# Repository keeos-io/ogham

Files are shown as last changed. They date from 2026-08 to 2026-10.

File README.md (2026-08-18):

# Ogham

A dual-voice **bytebeat synthesizer** for Eurorack, built on the Electro-Smith
Daisy Seed. This repository holds everything needed to build one: firmware
source, schematics, PCB, panel, and the fabrication package.

Instead of oscillators and wavetables, Ogham runs *bytebeat* expressions —
single lines of integer arithmetic that, evaluated over time, produce
surprisingly rich rhythmic and melodic patterns. It hosts a bank of them, plays
two at once, and clocks, pitches and modulates them from the rest of your rack.

- **Manual:** <https://keeos.io/docs/ogham-manual/> (or [`docs/ogham-manual.pdf`](docs/ogham-manual.pdf))
- **Firmware downloads and changelog:** <https://keeos.io/firmware/ogham/>
- **Module overview:** <https://keeos.io/modules/ogham/>

> **Status: prototype.** Built and tested on a handful of units, not qualified
> for production. Published so others can learn from it and build on it. Check
> the design yourself before you commit money to a fab run.

## What's here

| Path | Contents |
|---|---|
| [`firmware/`](firmware/) | Firmware source, build and flashing instructions |
| [`hardware/ogham-merged-v1.0/`](hardware/ogham-merged-v1.0/) | KiCad schematics and PCB — the shipping revision |
| [`hardware/panel/`](hardware/panel/) | Front panel: artwork, and the panel PCB project |
| [`hardware/production/`](hardware/production/) | Gerbers, BOM, placement — ready to upload to a fab |
| [`docs/`](docs/) | Build instructions, and the manual as a PDF |
| `lib/` | libDaisy and DaisySP, as pinned submodules |

Only the **current** board revision is published. Earlier prototypes are not
included, so there is nothing here to fabricate by mistake.

## Quick start

**To build the firmware** — [`docs/BUILDING.md`](docs/BUILDING.md) has the full
set-up for Windows, macOS and Linux; [`firmware/README.md`](firmware/README.md)
covers the firmware itself. In short:

```bash
git clone --recurse-submodules https://github.com/keeos-io/ogham.git
cd ogham && make -C lib/libDaisy -j8 && make -C lib/DaisySP -j8
cd firmware && make -j8
```

`--recurse-submodules` is not optional: libDaisy has nested submodules of its
own, and without them the build fails part-way with a missing HAL object.

**To have the boards made** — see [`hardware/README.md`](hardware/README.md).
Upload `hardware/production/ogham-merged-v1.0.zip`, and **read the
hand-populate list first**: several parts are deliberately excluded from
assembly and a board built from the BOM alone will be missing them.

## Licensing

Firmware is **MIT**. Hardware and documentation are **CC BY-SA 4.0**. Build one,
sell one, fork it — but share hardware modifications alike, and give credit. The
*Keeos* name and the panel identity are not covered.

Full terms in [`LICENSE.md`](LICENSE.md); third-party components and the panel
typefaces in [`THIRD-PARTY.md`](THIRD-PARTY.md).

## A note on reproducible builds

The published binaries are byte-for-byte reproducible from this repository.
Building the firmware at a given tag, with the submodules at their pinned
commits and **Arm GNU Toolchain 14.2.Rel1**, reproduces the exact `.bin` shipped
for that release — verified, not assumed.

Two things will break that: building against a *different* libDaisy commit, or a
different compiler version. Both produce working firmware; neither reproduces the
published checksums. If you are verifying a download rather than developing,
compare against the SHA-256 published with each release.

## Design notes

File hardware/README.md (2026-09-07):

# Ogham hardware

KiCad 10 sources and a ready-to-upload fabrication package for the shipping
board revision, **ogham-merged-v1.0**.

| | |
|---|---|
| Main PCB | 50 × 110 mm, 2-layer, double-sided SMT |
| Panel | 10 HP (50.5 × 128.5 mm) |
| Depth behind panel | ~32 mm including power-cable clearance — skiff-friendly |
| Supply | Eurorack ±12 V; the Seed runs from +12 V through a series Schottky, and an on-board +5 V regulator feeds the display and logic |
| MCU | Electro-Smith Daisy Seed (STM32H750), on pin-header standoffs |

Only this revision is published. Earlier prototypes (`ogham-logic`, `ogham-ui`
and their v0.2 iterations) are not included, so there is nothing here to
fabricate by mistake.

## Layout

| Path | Contents |
|---|---|
| `ogham-merged-v1.0/` | Schematics (hierarchical: power, MCU, CV I/O, audio, UI), PCB, netlist |
| `panel/` | Panel artwork as SVG, and the panel as a fabricable PCB (`PanelPCB-v2/`) |
| `production/` | Gerbers, BOM, placement, IPC netlist, and the interactive BOM |

The schematic is a two-level hierarchy: `ogham-merged-v1.0` is the root, and it
pulls in `ogham-logic-v2.0` (→ power, MCU, CV I/O) and `ogham-ui-v0.2` (→ audio,
UI). Those two keep the sheet names they had when the design was two separate
boards — they are **not** old revisions, they are live sub-sheets of this one.

## 3D models are not included

The PCB references five third-party 3D models. They are other people's files, in
one case 34 MB of one, and several arrived without a licence attached, so they
are not redistributed here. Everything else the board needs is in this
repository; only the 3D viewer is affected, and the board fabricates,
assembles and works without them.

The references are `${KIPRJMOD}`-relative, which means KiCad resolves them
against the project directory. Create `hardware/_libs/` and drop the files in
at these paths and the 3D view fills in with no edit to the PCB:

| Path under `hardware/_libs/` | Part | Source | Licence |
|---|---|---|---|
| `AudioJacks/AudioJacks.3dshapes/PJ398SM_Hex_nut.step` | Thonkiconn PJ398SM jacks | [clacktronics/AudioJacks](https://github.com/clacktronics/AudioJacks) | MIT |
| `kicad-3dmodels/potentiometers/ALPHA-RD901F-40.step` | Alpha 9mm pots | [dhaillant/kicad-3dmodels](https://github.com/dhaillant/kicad-3dmodels) | GPL-3.0 |
| `TM1637/YAAJ_4_Digit_LED_Display_0_36_Dots_TM1637_PinHeader_Left_cp.step` | TM1637 display | [yet-another-average-joe/KiCad-Chinese_Modules](https://github.com/yet-another-average-joe/KiCad-Chinese_Modules) | not stated upstream |
| `DaisySeed/ES_Daisy_Seed_Rev7-1.step` | Daisy Seed | Electro-Smith | not stated on the copy used here |
| `Encoder/EC11E1834403/3D/EC11E1834403.stp` | EC11 encoder | manufacturer model; provenance not recorded | unknown |
| `vendor/2MS1T1B1M2QES--3DModel-STEP-56544.STEP` | Mode toggle switch | manufacturer model | unknown |
| `vendor/TAP106J016SCS.STEP` | Tantalum capacitor | manufacturer model | unknown |

A missing model is a warning, not an error: KiCad opens the board and reports
which ones it could not find. Note also that each jack footprint carries a
second, dead model entry naming `${KICAD9_3DMODEL_DIR}`, a KiCad 9 path
variable that KiCad 10 does not define. The jacks render from the AudioJacks
model above, so that entry can be ignored.

## Browse the design without installing anything

[KiCanvas](https://kicanvas.org) renders KiCad files in the browser, straight
from this repository — pan, zoom, click a symbol, follow a net. Nothing to
install, nothing to download.

| | |
|---|---|
| Schematic and PCB | [Open in KiCanvas](https://kicanvas.org/?github=https://github.com/keeos-io/ogham/tree/main/hardware/ogham-merged-v1.0) |
| Panel PCB | [Open in KiCanvas](https://kicanvas.org/?github=https://github.com/keeos-io/ogham/tree/main/hardware/panel/PanelPCB-v2) |

Both links point at a **directory**, not at a file, and that is deliberate. Given
a single `.kicad_sch` KiCanvas loads it alone, which for a hierarchical design
means the root sheet and nothing below it — you would get a page of sheet symbols
with no way into them. Pointed at the directory it enumerates every file, so all
nine sheets resolve and the board is in the same viewer, behind the file picker
at the top left.

This matters more than convenience: these are **KiCad 10** sources, and KiCad 9
cannot open them at all. Until you have KiCad 10 in front of you, the links above
are the only way to read the circuit.

KiCanvas is a third-party viewer and fetches from GitHub anonymously, so it is
subject to GitHub's rate limits and is nobody's idea of a permanent archive. The
files in this repository are the source of truth; the links are a convenience.

## Having the boards made

The package in `production/` is formatted for JLCPCB assembly, but the gerbers
are standard and will work anywhere. **Read
[`production/JLC-upload-checklist.md`](production/JLC-upload-checklist.md)
before ordering** — it covers the whole flow, including the two things most
likely to cost you a board run.

### ⚠ 1. Nineteen parts must be marked "Do Not Place"

90 SMD parts are machine-assembled. **19 designators across 13 BOM rows are
hand-soldered** and will be flagged by the fab as unresolvable, because they
carry no LCSC number. Mark every one of them DNP:

- **C5** — 10 µF tantalum (`TAP106J016SCS`). This one is easy to miss: it looks
  like an ordinary SMD part in the BOM and it is the **+5 V bulk capacitor**, so
  a board that quietly ships without it is not a board you want.
- **A1** — the Daisy Seed
- **J1** — Eurorack power header
- **8 × jacks** — `J_CLK1`, `J_CVA1`, `J_CVB1`, `J_GATE_IN1`, `J_CV_OUT1`,
  `J_GATE_OUT1`, `J_OUT1`, `J_OUT2`
- **J_DISP1**, **J_DISP_SUPP** — display headers
- **4 × pots** — `RVA1`, `RVB1`, `RVLEVEL1`, `RVRATE1`
- **SW_ENC1** — encoder · **SW_MODE1** — mode toggle

### ⚠ 2. Check rotations before you confirm

Rotation is the classic assembly error — KiCad and the fab disagree about
reference orientation. Step through the placement preview and check the
polarised parts: diode cathodes (D1, D2, D8, D3, D4, D5, D_OCT1, D_OCT2, D6,
D7), IC pin-1 (U1–U7), and Q1's collector/emitter. Assembly is **double-sided**,
so also confirm the top-layer parts really are on top.

## Interactive BOM — use this while assembling

[`production/ogham-merged-v1.0-ibom.html`](production/ogham-merged-v1.0-ibom.html)
is a single self-contained file: click a line in the BOM and those parts light up
on the board, front and back, with checkboxes for tracking what you have sourced
and placed. No install, no network — **download it and open it in a browser**.

> GitHub displays committed HTML as source rather than rendering it, so use the
> download button rather than clicking through — the file is useless as text and
> perfectly good once saved.

It carries an **LCSC** column, which doubles as the hand-populate list: a part
with an LCSC number is machine-assembled, and a part **without** one is yours to
solder. `C5` shows its bare MPN `TAP106J016SCS`, and the jacks, pots, encoder and
headers show nothing at all — those are exactly the 19 designators to mark Do Not
Place.

Regenerate it with [`gen-ibom.sh`](gen-ibom.sh) whenever the board changes; the
output is committed, so it can otherwise drift from the design. It needs KiCad's
own Python and [InteractiveHtmlBom](https://github.com/openscopeproject/InteractiveHtmlBom)
**v2.11.2 or newer** — earlier versions cannot read KiCad 10 files.

## Hand-populated parts

Sources that have worked (UK):

| Part | Qty | Where |
|---|---|---|
| Thonkiconn PJ398SM jacks | 8 | [thonk.co.uk](https://www.thonk.co.uk/shop/thonkiconn/) |
| Alpha 9 mm B10K D-shaft pots | 4 | [thonk.co.uk](https://www.thonk.co.uk/shop/alpha-9mm-pots-dshaft/) |
| Rotary encoder, Bourns `PEC11R-4115K-S0018` | 1 | Any distributor — Mouser, Farnell, Digi-Key |
| Breakaway pin header | 1 bag | [thonk.co.uk](https://www.thonk.co.uk/shop/60-pin-header/) |
| 2×5 IDC power header | 1 | Mouser / Soundtronics / York Modular |
| Daisy Seed (Rev 4) | 1 | Electro-Smith |
| C5, 10 µF tantalum | 1 | Any distributor — `TAP106J016SCS` or equivalent |

> **Encoder note.** `PEC11R-4115K-S0018` is a 15 mm knurled (T18) shaft with a
> push switch, 18 detents and 18 pulses per revolution — one pulse per detent.
> It is the swapped-A/B part, which the **default** firmware build targets. Two
> batches exist with opposite A/B phase and the firmware cannot tell them apart,
> so if the Func encoder counts down when turned clockwise, flash the other
> build — see [`../firmware/README.md`](../firmware/README.md).
>
> **Why the 15 mm shaft.** It matches the Alpha pots dimensionally: the same
> 5 mm M7 × 0.75 bushing and the same 15 mm from mounting shoulder to shaft tip,
> so the encoder knob sits level with the four pot knobs rather than standing
> proud of them. The 20 mm variant of the same encoder carries a 7 mm bushing
> and would not. The cost of that choice is a short thread — 5 mm of bushing
> against a 1.6 mm panel — so expect to pack a washer under the nut to pull the
> encoder flush.

## Panel

`panel/` holds the artwork as SVG and as a fabricable PCB, which is how the
panels were actually made — a PCB panel is cheap, flat, and takes the graphics as
silkscreen.

`Ogham Panel Graphics (JLCPCB) v2.svg` is the editable artwork, and
`PanelPCB-v2/` is the KiCad project converted from it — that project, and the
gerbers in its `production/`, are what the built modules use. The first
revision has been removed to leave only one panel to order from; it is still in
the git history if you want it.

**The fabrication files do not depend on any fonts.** The artwork is stored as
polygons, converted from the SVG, so a panel ordered from
`PanelPCB-v2/production/` comes out right regardless of what is installed on your
machine.

**Editing the SVG does need fonts**, though all three are now free and
redistributable — the v2 artwork replaced Bahnschrift, a Windows system font,
with DINish. See
[`../THIRD-PARTY.md`](../THIRD-PARTY.md) for the full list and what to do on
macOS or Linux.

## Design notes

`ogham_pins.h` in the firmware is the pin-assignment source of truth and matches
this schematic. If you rework the board, keep them in step.

Two constraints worth knowing before you move things: the TM1637 display sits on
**D9/D10 (PB4/PB5)**, which are SPI pins with **no I²C alternate function** — an
I²C peripheral needs different pins. Seed pins 12/13 (PB8/PB9, I²C1) are
unconnected and are the obvious place to go.

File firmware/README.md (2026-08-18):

# Ogham firmware

C++ for the STM32H750 on an Electro-Smith Daisy Seed, built against libDaisy and
DaisySP. Runs from **internal flash at `0x08000000`** — there is no bootloader
involved, so the whole 128 KB region is the application.

## Building

Full per-platform setup for **Windows, macOS and Linux** — toolchain, Make, USB
drivers, udev rules — is in [`../docs/BUILDING.md`](../docs/BUILDING.md). That is
the authority; this file covers only what is specific to the firmware itself.

The short version, once the tools are installed:

```bash
git clone --recurse-submodules https://github.com/keeos-io/ogham.git
cd ogham
make -C lib/libDaisy -j8 && make -C lib/DaisySP -j8
cd firmware && make -j8            # -> build/ogham_bytebeat.{elf,bin,hex}
```

`--recurse-submodules` is not optional — libDaisy has nested submodules, and
without them the build fails part-way with a missing HAL object. Fix an existing
clone with `git submodule update --init --recursive`.

Libraries elsewhere? `make LIB_DIR=/path/to/libs -j8`.

Reproducing a published binary exactly needs **Arm GNU Toolchain 14.2.Rel1** and
the submodules at their pinned commits; any other compiler builds working
firmware that simply will not match the release checksum.

## ⚠ Two encoder builds — pick the right one

Two batches of rotary encoder exist with **opposite A/B phase**. The firmware
cannot detect which is fitted, so there are two builds:

| Build | Command | Output | For |
|---|---|---|---|
| **Default** | `make -j8` | `build/ogham_bytebeat.bin` | The current encoder — **almost certainly what you want** |
| Original | `make -f Makefile.encorig BUILD_DIR=build_encorig -j8` | `build_encorig/ogham_bytebeat_encorig.bin` | Early units with the original part |

**If after flashing the Func encoder counts *down* when you turn it clockwise,
you flashed the wrong one.** Flash the other and it is fixed. Nothing else
differs between them — same version, same behaviour, same display.

> Note for anyone reading older release notes: this naming **flipped in v1.05**.
> The default build used to be the original encoder, with the reversed one as
> the variant. It is now the other way round, because the reversed part is what
> current modules use.

## Flashing

Commands and platform notes are in [`../docs/BUILDING.md`](../docs/BUILDING.md#flashing).
In brief: `make program` with an ST-Link, or hold **BOOT**, tap **RESET**, and

```bash
dfu-util -a 0 -s 0x08000000:leave -D build/ogham_bytebeat.bin
```

The `:leave` matters, and **unplug USB before power-cycling** — the Seed is
powered by USB as well as the rack, so the case switch alone does not reset it.

## Layout

| File | Role |
|---|---|
| `ogham_main.cpp` | Init, main loop, encoder/menu state machine, persistence, telemetry |
| `bytebeat_engine.*` | 32.32 fixed-point phase accumulator; dual voice; hard sync; drone |
| `formulas.*` | The formula bank as inline functions, plus metadata |
| `ogham_audio_pipeline.*` | Tone macro, FX chain, low-pass gate |
| `ogham_controls.*` | ADC smoothing, quadrature decode, mode switch |
| `ogham_display.*`, `tm1637.*` | 4-digit 7-segment display |
| `ogham_cv_output.*` | Envelope follower / DC out on the DAC |
| `bpm_clock.*` | Tempo estimation for the EOC output |
| `ogham_pins.h` | Pin assignments — the source of truth, matching the schematic |

Formulas are compiled in. All bitwise operations follow JavaScript `ToInt32`
semantics (shift counts masked to `& 31`, output masked to `& 0xFF`) so formulas
behave as they do in browser bytebeat tools.

`formulas.h` and `formulas.cpp` are **generated**, not hand-written — the bank is
translated out of the curated library by `tools/gen_ogham_bank.cpp` in the
bytebeat repository (the search and curation tooling, which is not published).
The generator emits the manual's Appendix A from the same manifest, and compares
every generated function against the evaluator the formulas were auditioned on.
Change the library and regenerate rather than editing these two files, or the
module and the manual drift apart.

Which formula lands in which slot is stored on the curated formula itself rather
than derived from its position in the library: the generator reads those numbers
and does not sort, group or renumber. Slots are assigned in the bytebeat app's
CURATE view, which can also preview the whole bank against the firmware's
current `formulas.h` before anything is generated. The end-to-end process —
including the flash-size check, which is the binding constraint on this 128 KB
region — is `docs/PUBLISHING-THE-BANK.md` in that repository.

Appendix A of the manual lists every formula's expression and what A and B change.

## Calibration

Pots are non-linear because of the 10 kΩ pull-down, so the firmware holds
measured 12-o'clock ADC values for the Rate and Tone knobs. Those constants are a
fleet mean; if your build's centre detent feels off, measure yours:

```bash
make -f Makefile.diag -j8       # -> build_diag/ogham_pot_diag.{elf,bin}
```

Flash it, read the values off the display, and update `RATE_POT_CENTER` in
`ogham_main.cpp` and `LOFI_CENTER` in `ogham_audio_pipeline.cpp`.

`tools/` holds Python scripts that read live telemetry over SWD while the module
runs — useful for calibration and for watching CPU load.

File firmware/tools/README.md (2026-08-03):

# Ogham Monitor

A PC app that visualizes the running module live over the debugger (ST-Link/SWD):
the 7-segment display (exact segments, even with no TM1637 wired), module state,
pot positions, and CV inputs. For debugging and calibration.

It reads the firmware's `g_telemetry` struct via OpenOCD — **no USB to the
Daisy**, so the module runs on **Eurorack power** with the CV inputs live, and
there's no dual-supply contention.

## Run

1. Power the module from **Eurorack** and connect the **ST-Link** (the same SWD
   setup used for flashing). The board must be powered, or OpenOCD can't connect.
2. Close anything else using the ST-Link (you can't flash while the monitor runs).
3. `python ogham_monitor.py`

The app launches its own OpenOCD instance, finds `g_telemetry` via `nm` on
`build/ogham_bytebeat.elf`, and polls at ~12 Hz.

## Shows
- **7-segment display** — the exact bytes the firmware sends to the TM1637.
- **State** — mode (SELECT/DELAY), edited voice, Out1/Out2 formulas, delay,
  params A/B, rate, ext-clock, lo-fi clean, gate/clock inputs, CPU load.
- **Bars** — raw pot ADCs (A/B/Rate/Level), combined pot+CV (A/B), CV ADC pins
  (shown as volts).

## Notes
- Paths to OpenOCD and `arm-none-eabi-nm` are set at the top of the script.
- The telemetry struct layout is `STRUCT_FMT` in the script; it must match
  `struct Telemetry` in `ogham_main.cpp`. If you change the struct, update both.
- The struct address is found automatically (via `nm`); it moves on rebuilds.

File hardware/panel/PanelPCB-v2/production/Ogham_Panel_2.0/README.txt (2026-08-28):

 FRONT PANEL - NO ELECTRICAL FUNCTION

  1. ALL holes, slots and internal cutouts are NON-PLATED (NPTH).
     Do not plate any hole, slot or cutout.
  2. There are no nets and no plated holes on this board.
     The PTH drill file is intentionally empty.
  3. Internal openings are defined by the Edge_Cuts layer (15 openings)
     and by the NPTH drill file (4 mounting slots, 4.5 x 3.5 mm routed).
     Route all of them; none are plated.
  4. Front copper is decorative artwork only. Where copper meets a routed
     edge, cut through it. Do not add plating, do not add copper thieving,
     and do not modify the copper or silkscreen artwork.

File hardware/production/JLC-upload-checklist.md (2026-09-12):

# JLCPCB Upload Checklist — Ogham v1.0 (ogham-merged-v1.0)

Files: `ogham-merged-v1.0.zip` (gerbers) · `bom.csv` · `positions.csv`
Board: 50 × 110 mm, 2-layer. Assembly: **double-sided SMT** (55 parts bottom / 35 top) + hand-soldered THT.

---

## 1. Upload files
- [ ] Upload gerber zip → confirm JLC preview shows both copper layers, silk, and the board outline (50 × 110 mm)
- [ ] Turn ON "PCB Assembly" → upload `bom.csv` and `positions.csv`
- [ ] Assembly side = **both / top+bottom** (SMD is on both layers)

## 2. Mark "Do Not Place" (DNP) — 14 BOM rows / 19 designators
These are hand-soldered; they have no LCSC (or a non-LCSC MPN) and JLC will ask you to resolve them. Mark each **Do Not Place**:

- [ ] **C5** — 10µF tantalum (MPN `TAP106J016SCS`, not an LCSC number)
- [ ] **A1** — Daisy Seed module
- [ ] **J1** — Eurorack power header
- [ ] **J_CLK1, J_CVA1, J_CVB1, J_GATE_IN1** — 4× audio jacks
- [ ] **J_CV_OUT1** — jack
- [ ] **J_GATE_OUT1** — jack
- [ ] **J_OUT1, J_OUT2** — 2× jacks
- [ ] **J_DISP1** — TM1637 display header
- [ ] **J_DISP_SUPP** — display support header
- [ ] **RVA1, RVB1, RVLEVEL1, RVRATE1** — 4× pots
- [ ] **SW_ENC1** — encoder
- [ ] **SW_MODE1** — mode toggle

_(Everything else — the 90 SMD parts — has a valid LCSC and should stay "Place".)_

## 3. Verify part rotations/polarity in JLC's placement preview
Rotation is the classic assembly error (KiCad vs JLC reference orientation). Eyeball the polarized parts in the online preview; fix any that look flipped 90°/180° before confirming:

- [ ] **Diode cathodes** — D1, D2, **D8** (SS14); D3 (1N4148); D4, D5, D_OCT1, D_OCT2 (BAT54WS); D6, D7 (1N5819WS)
- [ ] **IC pin-1** — U1 (LM4040), U2 (L7805), U3 (MCP6004), U4, U7 (TL072), U5 (74AHCT1G125), U6 (LM393)
- [ ] **Q1** (MMBT3904) collector/emitter orientation
- [ ] Spot-check a couple of the SMD parts on the **top** layer render (double-sided — confirm they're on the correct side)

## 4. Parts / stock confirmation
- [ ] **U1 LM4040 (C156291, LM4040C50FTA)** — confirm in stock at order time (1 per board). Substituted for C156302 on 2026-09-12; JLCPCB places this part, so kits, build guide and manuals are unaffected
- [ ] Note any **Extended parts** loading fee (TL072, MCP6004, LM4040, LM393, 74AHCT1G125 are likely Extended, ~$3 one-time each)

## 5. Place order
- [ ] Review price (double-sided SMT costs more than single-sided)
- [ ] Confirm and order

---

### Hand-solder yourself after boards arrive (the DNP parts above)
8× Thonkiconn jacks · 4× Alpha pots · encoder · mode toggle · Eurorack power header · 2× display headers · C5 tantalum · Daisy Seed (on its pin-header standoffs).

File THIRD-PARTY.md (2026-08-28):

# Third-party components

Everything Ogham depends on that was not written for it, and the licence each
arrives under.

## Firmware

| Component | Licence | Source |
|---|---|---|
| **libDaisy** | MIT © Electrosmith, Corp. | <https://github.com/electro-smith/libDaisy> |
| **DaisySP** | MIT © Electrosmith, Corp. | <https://github.com/electro-smith/DaisySP> |

Both are **git submodules pinned to exact commits**, not copies:

| Submodule | Pinned commit |
|---|---|
| `lib/libDaisy` | `f044cdc312455f174b01bef98d9e97598d94d3bc` |
| `lib/DaisySP`  | `599511b740f8f3a9b8db72a0642aa45b8a23c3a3` |

Pinning is deliberate. A firmware binary is only reproducible if the libraries
are, and libDaisy in particular changes underneath you. Building at these commits
reproduces the published binaries byte for byte; building at `main` may not.

Neither library is modified. If you need a newer one, update the submodule and
rebuild — but expect to re-verify, not to match the published checksums.

The hardware itself is built around the **Electro-Smith Daisy Seed**, which is
itself open hardware. Its schematics and design files are Electrosmith's, are not
reproduced here, and are published at <https://github.com/electro-smith/Hardware>.

## Panel typefaces

The panel artwork uses three typefaces. **No font files are redistributed here** —
the SVG sources reference them by name.

| Typeface | Used for | Licence |
|---|---|---|
| **Uncial Antiqua** | the "ogham" wordmark | SIL Open Font License 1.1 — <https://fonts.google.com/specimen/Uncial+Antiqua> |
| **Noto Sans Ogham** | the ogham script characters | SIL Open Font License 1.1 — <https://fonts.google.com/noto/specimen/Noto+Sans+Ogham> |
| **DINish** | control labels | SIL Open Font License 1.1 — <https://fonts.playbeing.com/dinish/> |

### What this means in practice

**The fabrication files do not depend on any of them.** `hardware/panel/PanelPCB-v2`
and the gerbers in its `production/` directory carry the artwork as **polygons**,
converted from the SVG by svg2shenzhen. The only text left in the footprint is
KiCad's own `Ref**`/`Val**` placeholders, which do not print. You can order a
panel with no fonts installed at all, on any operating system, and get exactly
the intended result.

**The editable SVG sources do depend on them.** Open
`hardware/panel/*.svg` without these fonts installed and the renderer will
substitute — the lettering will still appear, but with different metrics, so it
will not match the fabricated panel and may overlap its own layout. If you intend
to *edit* the panel rather than just fabricate it, install all three: Uncial
Antiqua and Noto Sans Ogham are on Google Fonts, and DINish is at
<https://fonts.playbeing.com/dinish/>. All three are OFL, free, and available on
every platform.

The control labels were set in Bahnschrift until the v2 panel artwork. That is a
Windows system font, proprietary to Microsoft and not redistributable, so editing
the panel on macOS or Linux meant substituting it and re-laying out the labels.
DINish is a DIN 1451 descendant and takes its place with no such condition
attached.

## Fabrication

The `hardware/production/` package is formatted for JLCPCB's assembly service.
Nothing in it is licensed by JLCPCB; the file formats (Gerber, IPC-D-356,
positions CSV) are open. It will work at other fabs, though the BOM's LCSC part
numbers are specific to JLCPCB's supplier and would need mapping.

## Bytebeat formulas

The formulas in `firmware/src/formulas.h` were discovered by machine search
(a purpose-built GPU search with a neural fitness model) and are original to this
project, not taken from published bytebeat collections.

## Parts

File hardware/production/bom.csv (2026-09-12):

Designator | Footprint | Quantity | Value | LCSC Part #
A1 | Electrosmith_Daisy_Seed | 1 | Electrosmith_Daisy_Seed_Rev4
C1, C10, C2 | 1210 | 3 | 10uF | C138687
C3, C4, C6, C7, C8, C9, C_BYP_U3, C_BYP_U4N1, C_BYP_U4P1, C_BYP_U5, C_BYP_U6, C_ENC_A1, C_ENC_B1, C_ENC_SW1, C_FLT1, C_FLT2, C_FLT3, C_FLT4, C_TL1, C_TL2 | 0603 | 20 | 100nF | C14663
C5 | CP_Radial_D5.0mm_P2.50mm | 1 | 10uF | TAP106J016SCS
C_FB_A1, C_FB_B1, C_VOCT_ADC1 | 0603 | 3 | 1nF | C1588
C_FILT1, C_FILT2 | 0603 | 2 | 2.2nF | C1604
D1, D2, D8 | D_SMA | 3 | SS14 | C2480
D3 | D_SOD-323 | 1 | 1N4148 | C2128
D4, D5, D_OCT1, D_OCT2 | D_SOD-323 | 4 | BAT54WS | C22629
D6, D7 | D_SOD-323 | 2 | 1N5819WS | C191023
FB1, FB2 | 0603 | 2 | BLM18PG121 | C14709
J1 | PinHeader_2x05_P2.54mm_Vertical | 1 | Eurorack_Power
J_CLK1, J_CVA1, J_CVB1, J_GATE_IN1 | Jack_3.5mm_QingPu_WQP-PJ398SM_Vertical_CircularHoles | 4 | AudioJack2_SwitchT
J_CV_OUT1 | Jack_3.5mm_QingPu_WQP-PJ398SM_Vertical_CircularHoles | 1 | CV_OUT
J_DISP1 | PinHeader_1x04_P2.54mm_Vertical | 1 | TM1637
J_DISP_SUPP | PinHeader_1x04_P2.54mm_Vertical | 1 | PinHeader_1x04_P2.54mm_Vertical
J_GATE_OUT1 | Jack_3.5mm_QingPu_WQP-PJ398SM_Vertical_CircularHoles | 1 | GATE_OUT
J_OUT1 | Jack_3.5mm_QingPu_WQP-PJ398SM_Vertical_CircularHoles | 1 | OUT1
J_OUT2 | Jack_3.5mm_QingPu_WQP-PJ398SM_Vertical_CircularHoles | 1 | OUT2
Q1 | SOT-23 | 1 | MMBT3904 | C20526
R1, R_CLK_IN1, R_CLK_PU1, R_CV_GND1, R_DIO1, R_DIV1, R_DIV2, R_F1, R_F2, R_VOCT1 | 0603 | 10 | 10k | C25804
R2, R5, R8, R9, R_FB_A1, R_FB_B1, R_GATE_IN1, R_HYS1, R_PD1, R_PD2, R_PD3, R_PD4 | 0603 | 12 | 100k | C25803
R3, R6 | 0603 | 2 | 470k | C23178
R4, R7 | 0603 | 2 | 200k | C25811
RVA1, RVB1, RVLEVEL1, RVRATE1 | Potentiometer_Alpha_RD901F-40-00D_Single_Vertical | 4 | 10k
R_CV_FB1 | 0603 | 1 | 20k | C4184
R_CV_OUT1, R_FLT1, R_FLT2, R_FLT3, R_FLT4, R_GOUT1, R_OUT1, R_OUT2, R_VOCT_ADC1 | 0603 | 9 | 1k | C21190
R_FILT1, R_FILT2 | 0603 | 2 | 470 | C23179
R_G1, R_G2 | 0603 | 2 | 2.7k | C13167
R_GATE_DIV1 | 0603 | 1 | 33k | C4216
R_VOCT2 | 0603 | 1 | 18k | C25810
SW_ENC1 | RotaryEncoder_Alps_EC11E-Switch_Vertical_H20mm | 1 | Encoder
SW_MODE1 | SW_2MS1T1B1M2QES | 1 | SW_SPDT
U1 | SOT-23 | 1 | LM4040-5.0 | C156291
U2 | TO-263-2 | 1 | L7805 | C15077
U3 | TSSOP-14_4.4x5mm_P0.65mm | 1 | MCP6004 | C50282
U4, U7 | SOIC-8_3.9x4.9mm_P1.27mm | 2 | TL072 | C67473
U5 | SOT-23-5 | 1 | 74AHCT1G125 | C7484
U6 | SOIC-8_3.9x4.9mm_P1.27mm | 1 | LM393 | C136033

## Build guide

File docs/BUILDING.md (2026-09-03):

# Building and flashing Ogham firmware

Step-by-step for **Windows**, **macOS** and **Linux**. If you only want to *run*
the firmware, you do not need any of this — download a `.bin` from the
[releases page](https://github.com/keeos-io/ogham/releases) or use the
in-browser flasher at <https://keeos.io/firmware/ogham/>, and skip to
[Flashing](#flashing).

> **Verification note.** The Windows instructions are the ones used day to day
> and are known good. The macOS and Linux instructions follow the standard route
> for each platform and use the same official Arm toolchain, but have not been
> exercised on those machines. If something is off, please open an issue — it
> will be a documentation bug, not a firmware one.

## What you need

| | Why | Version |
|---|---|---|
| **Arm GNU Toolchain, `arm-none-eabi`** | Cross-compiler | **14.2.Rel1** — see below |
| **GNU Make** | Build driver | Any recent |
| **Git** | With submodule support | Any recent |
| *Optional:* **OpenOCD** | Flashing over SWD with an ST-Link | 0.12.x |
| *Optional:* **dfu-util** | Flashing over USB, no probe needed | 0.11+ |
| *Optional:* **Python 3** | Live telemetry tools in `firmware/tools/` | 3.9+ |

### Why the toolchain version is called out

The published binaries are byte-for-byte reproducible with **Arm GNU Toolchain
14.2.Rel1** and the submodules at their pinned commits. A different compiler
version builds perfectly good firmware — it just will not match the SHA-256
published with the release. If you are verifying a download rather than
developing, use 14.2.Rel1; otherwise use whatever you have.

Direct downloads for 14.2.Rel1 (all verified live):

| Platform | File |
|---|---|
| Windows | [`…-mingw-w64-i686-arm-none-eabi.exe`](https://developer.arm.com/-/media/Files/downloads/gnu/14.2.rel1/binrel/arm-gnu-toolchain-14.2.rel1-mingw-w64-i686-arm-none-eabi.exe) |
| macOS (Apple Silicon) | [`…-darwin-arm64-arm-none-eabi.tar.xz`](https://developer.arm.com/-/media/Files/downloads/gnu/14.2.rel1/binrel/arm-gnu-toolchain-14.2.rel1-darwin-arm64-arm-none-eabi.tar.xz) |
| macOS (Intel) | [`…-darwin-x86_64-arm-none-eabi.tar.xz`](https://developer.arm.com/-/media/Files/downloads/gnu/14.2.rel1/binrel/arm-gnu-toolchain-14.2.rel1-darwin-x86_64-arm-none-eabi.tar.xz) |
| Linux (x86-64) | [`…-x86_64-arm-none-eabi.tar.xz`](https://developer.arm.com/-/media/Files/downloads/gnu/14.2.rel1/binrel/arm-gnu-toolchain-14.2.rel1-x86_64-arm-none-eabi.tar.xz) |
| Linux (ARM64) | [`…-aarch64-arm-none-eabi.tar.xz`](https://developer.arm.com/-/media/Files/downloads/gnu/14.2.rel1/binrel/arm-gnu-toolchain-14.2.rel1-aarch64-arm-none-eabi.tar.xz) |

---

## Windows

Use **Git Bash** (installed with Git for Windows) for the commands below. The
Makefiles are POSIX shell; they will not run in `cmd.exe` or PowerShell.

The exact set-up in use, via `winget`:

```powershell
winget install Arm.GnuArmEmbeddedToolchain    # 14.2.Rel1
winget install ezwinports.make                # GNU Make 4.4.1
winget install xpack-dev-tools.openocd-xpack  # optional, for ST-Link flashing
```

**Windows does not ship `make`, and the Arm toolchain does not include it** —
that is the step people miss. `ezwinports.make` is a plain native build with no
MSYS baggage. MSYS2's `make`, or Chocolatey's, work equally well.

`dfu-util` has no reliable winget package; take the Windows binary from
<https://dfu-util.sourceforge.net/> and put it on your `PATH`.

The Arm installer offers to add itself to `PATH` — say yes, or add it per shell:

```bash
export PATH="/c/Program Files (x86)/Arm GNU Toolchain arm-none-eabi/14.2 rel1/bin:$PATH"
```

### USB drivers

Windows needs a driver bound to the device before flashing tools can see it:

- **ST-Link** — install ST's ST-LINK USB driver, or use the one bundled with
  STM32CubeProgrammer.
- **DFU (bootloader mode)** — the Seed enumerates as *STM32 BOOTLOADER* and
  needs the **WinUSB** driver. Use [Zadig](https://zadig.akeo.ie/): put the Seed
  in DFU mode, pick that device, select **WinUSB**, and hit Replace Driver.
  Without this, `dfu-util` reports no DFU capable devices found.

---

## macOS

With [Homebrew](https://brew.sh):

```bash
brew install --cask gcc-arm-embedded    # Arm toolchain (check the version it gives you)
brew install make git open-ocd dfu-util
```

macOS ships GNU Make 3.81, which is old but sufficient here. Homebrew's `make`
installs as `gmake` unless you adjust `PATH`; either works.

**If you need exactly 14.2.Rel1** — because you want to reproduce a published
checksum — install Arm's tarball rather than the cask, since the cask tracks
whatever is current:

```bash
curl -LO https://developer.arm.com/-/media/Files/downloads/gnu/14.2.rel1/binrel/arm-gnu-toolchain-14.2.rel1-darwin-arm64-arm-none-eabi.tar.xz
sudo mkdir -p /opt/arm && sudo tar -xf arm-gnu-toolchain-14.2.rel1-darwin-arm64-arm-none-eabi.tar.xz -C /opt/arm
export PATH="/opt/arm/arm-gnu-toolchain-14.2.rel1-darwin-arm64-arm-none-eabi/bin:$PATH"
```

Substitute `darwin-x86_64` on an Intel Mac.

**Gatekeeper.** Binaries downloaded outside the App Store are quarantined, and
the first `arm-none-eabi-gcc` run may be blocked. Clear it once:

```bash
sudo xattr -dr com.apple.quarantine /opt/arm
```

No driver work is needed — ST-Link and DFU both work through the system USB
stack.

---

## Linux

Install Make, Git and the flashing tools from your distribution:

```bash
# Debian / Ubuntu
sudo apt install build-essential git openocd dfu-util

# Fedora
sudo dnf install make git openocd dfu-util

# Arch
sudo pacman -S make git openocd dfu-util
```

For the compiler, **prefer Arm's tarball over the distro package**. Distro
`gcc-arm-none-eabi` versions vary widely, and some have historically shipped
without the newlib the build expects:

```bash
curl -LO https://developer.arm.com/-/media/Files/downloads/gnu/14.2.rel1/binrel/arm-gnu-toolchain-14.2.rel1-x86_64-arm-none-eabi.tar.xz
sudo mkdir -p /opt/arm && sudo tar -xf arm-gnu-toolchain-14.2.rel1-x86_64-arm-none-eabi.tar.xz -C /opt/arm
export PATH="/opt/arm/arm-gnu-toolchain-14.2.rel1-x86_64-arm-none-eabi/bin:$PATH"
```

Add that `export` to your `~/.bashrc` to make it stick.

> On 64-bit-only distributions the toolchain may need 32-bit support libraries.
> If `arm-none-eabi-gcc` reports "No such file or directory" despite clearly
> existing, that is the cause — install your distro's 32-bit compatibility
> packages.

### udev rules — the step that catches everyone

Without these, flashing fails with a permissions error unless you run as root.
Create `/etc/udev/rules.d/49-ogham.rules`:

```
# ST-Link V2 / V2.1 / V3
SUBSYSTEM=="usb", ATTR{idVendor}=="0483", ATTR{idProduct}=="3748", MODE="0666", TAG+="uaccess"
SUBSYSTEM=="usb", ATTR{idVendor}=="0483", ATTR{idProduct}=="374b", MODE="0666", TAG+="uaccess"
SUBSYSTEM=="usb", ATTR{idVendor}=="0483", ATTR{idProduct}=="374f", MODE="0666", TAG+="uaccess"
# STM32 DFU bootloader (the Daisy Seed in bootloader mode)
SUBSYSTEM=="usb", ATTR{idVendor}=="0483", ATTR{idProduct}=="df11", MODE="0666", TAG+="uaccess"
```

Then reload and re-plug the device:

```bash
sudo udevadm control --reload-rules && sudo udevadm trigger
```

---

## Building

Identical on all three platforms once the tools are in place.

```bash
git clone --recurse-submodules https://github.com/keeos-io/ogham.git
cd ogham
make -C lib/libDaisy -j8      # a few minutes the first time
make -C lib/DaisySP  -j8
cd firmware && make -j8
```

Output lands in `firmware/build/`: `ogham_bytebeat.elf`, `.bin` and `.hex`.

**`--recurse-submodules` is not optional.** libDaisy has nested submodules of its
own (CMSIS, the STM32 HAL). Without them the build fails part-way with
`No rule to make target '.../stm32h7xx_hal.o'`, which does not hint at the real
cause. If you already cloned without it:

```bash
git submodule update --init --recursive
```

**On Windows, turn on long paths before cloning.** Some CMSIS test-suite paths
inside libDaisy are longer than the old 260-character limit, so the recursive
clone stops with `Filename too long` and `Unable to checkout ... in submodule
path 'lib/libDaisy/Drivers/CMSIS_5'`:

```bash
git config --global core.longpaths true
```

Then clone again, or repair an existing clone with the `git submodule update`
line above. The files that fail to arrive are CMSIS unit tests, and a build on
top of the incomplete checkout still produced byte-identical firmware here — but
git reports the clone as failed, which is not a state worth building on.

### Libraries somewhere else

```bash
make LIB_DIR=/path/to/libs -j8    # expects $LIB_DIR/libDaisy and $LIB_DIR/DaisySP
```

---

## Flashing

The application lives in **internal flash at `0x08000000`**. There is no
bootloader, so the whole 128 KB region is yours.

### With an ST-Link (SWD)

Wire the probe to the Seed's SWD pads, power the module from your rack, then:

```bash
cd firmware && make program
```

Look for `** Verified OK **`.

On a Seed3 this route needs soldering first: Electro-Smith replaced the
surface-mount debug connector with bare through-hole pads, so there is nothing
to clip a probe onto until you fit a header. DFU, below, needs no probe at all
and is the easier path on that revision.

### Over USB (DFU) — no probe required

Use a data-capable cable — USB-C on a Seed3, micro-USB on earlier revisions. A
charge-only cable will not enumerate.

Hold **BOOT**, tap **RESET**, release **BOOT**, then:

```bash
dfu-util -a 0 -s 0x08000000:leave -D build/ogham_bytebeat.bin
```

**The `:leave` suffix matters.** Without it the Seed stays parked in DFU mode
with a blank display, looking dead. A trailing
`Error during download get_status` is a benign detach artefact — the write
succeeded.

### ⚠ After flashing, unplug USB before power-cycling

The Seed is powered by USB **and** by the Eurorack bus. With USB connected,
switching your case off does not reset the chip — so the new firmware never
starts and the module looks broken when it is fine. Unplug USB, then power up
from the rack.

---

## Troubleshooting

| Symptom | Cause |
|---|---|
| `No rule to make target '.../stm32h7xx_hal.o'` | Submodules not initialised — `git submodule update --init --recursive` |
| `arm-none-eabi-gcc: command not found` | Toolchain not on `PATH` for *this* shell |
| `make: command not found` (Windows) | Make is a separate install — see above |
| `Target voltage: 0.00V` | Module not powered, or the SWD header is not seated |
| `Target voltage: ~1.8V` | Loose SWD/VTREF contact — reseat the probe |
| `open failed` / device busy | Another tool is holding the probe |
| `No DFU capable USB device available` | Not in DFU mode, or (Windows) no WinUSB driver — see Zadig above |
| `LIBUSB_ERROR_ACCESS` (Linux) | udev rules missing — see above |
| Blank display after DFU | Flashed without `:leave`, so still in DFU mode. Re-flash with it, or power-cycle **with USB unplugged** |
| Builds fine, checksum differs | Different compiler version or unpinned submodules. Harmless unless you are verifying a release |

Anything not covered here, please open an
[issue](https://github.com/keeos-io/ogham/issues).

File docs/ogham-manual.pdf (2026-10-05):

# Ogham Manual

Full user manual for Ogham - a dual-voice bytebeat synthesizer for Eurorack.

UPDATED 5 OCTOBER 2026

A dual-voice bytebeat synthesizer for Eurorack, built on the Electro-Smith Daisy Seed.

# 1. Introduction

Ogham is a Eurorack voice that turns tiny mathematical formulas into music. Instead of oscillators and wavetables, it runs bytebeat expressions - single lines of integer arithmetic that, evaluated over time, produce surprisingly rich rhythmic and melodic patterns. Ogham hosts a bank of these formulas, lets you play two of them at once, shape them with a bipolar Tone macro and a 3-stage modulation FX chain, and clock, pitch, and modulate them from the rest of your system.

At a glance

100 function slots ( F0 - F99 ), each with two performable parameters (A & B). All hundred are filled, grouped by character - twenty each of textural, noise, percussive, rhythmic and melodic (see Section 4). A special AA slot holds a built-in A=440 Hz tuning reference.
Two independent voices (Out 1 / Out 2), each playing its own function.
Out 2 “drone/freeze” - decouple Out 2 into an independent, self-sustaining voice that ignores the knobs, clock, pitch, and FX.
Bipolar Tone macro - one knob from clean through low-pass filtering, wavefolding, saturation, sample-rate reduction, and resonant band-pass grit.
3-stage modulation FX - Chorus → Flanger → Phaser, each with a clean and a characterful variant, in series or parallel.
Mode switch: Clk ↔ VOct on a shared jack.
Clk - external tempo/clock (one pulse per beat) sets the bytebeat playback rate.
VOct - 1 V/oct drives the playback rate, so a formula’s natural pulse tracks the CV.
Hard-sync Sync input - sample-accurate waveform reset, usable up to audio rates.
CV over A and B (±5 V, summed with the knobs); either CV can be re-routed to the Tone macro instead of its parameter.
Internal LPG - a low-pass gate on the output, plucked from the Sync input: sharp attack, decay from 2 ms to 20 s, filter and VCA moving together.
Selectable CV Out - an envelope follower of either voice, or a raw bytebeat used as a slow DC modulation/LFO source; plus an EOC pulse out.
Voice selections, the full effects/settings menu, and all options persist across power cycles; a one-gesture factory reset.
Ogham Manual | Page 1 of 43

Ogham in VCV Rack

There is a VCV Rack 2 version of Ogham - free, and for Windows, macOS and Linux. It is not a recreation. Seven of the firmware’s nine source files are compiled into the plugin unmodified, so the voices you hear there are this module’s own code, and the panel is the same artwork at the same size.

Two things necessarily differ. A mouse has to stand in for a shaft you turn and press, so the encoder answers drag, click and hold instead; and patches do not transfer in either direction, because the module keeps its settings in its own flash format and nothing reads it out.

https://github.com/keeos-io/ogham-vcv (https://github.com/keeos-io/ogham-vcv)

# 2. The panel

Ogham packs a lot into a small panel: five knobs (one is the Func encoder), a mode switch, a 4-digit display, four inputs, and four outputs. The map below names every control; the detailed behaviour of each is in Section 5, Controls - full reference (the numbers here match the references there).

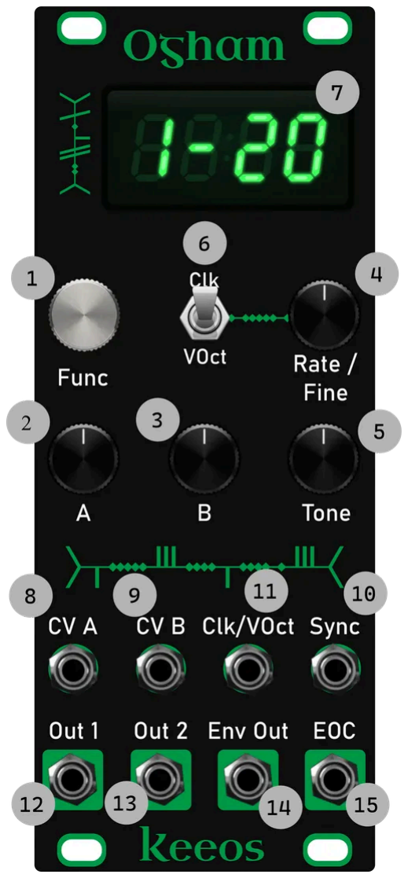
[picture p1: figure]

Control legend

# | Control | Type | In short

1 Func | | Rotary encoder (with push) | Select each voice’s function; long-press opens the Menu; short-click switches voice
2 | A | Knob (+ CV) | Formula Parameter A (0-255), shared by both voices
3 | B | Knob (+ CV) | Formula Parameter B (0-255), shared by both voices
4 | Rate / Fine | Knob | Playback rate 1/64×-64× (a quantized clock ×/÷ when a clock is patched); ±12-semitone fine tune in VOct mode

# | Control | Type | In short

5 | Tone | Knob | Bipolar tone macro - clean at 12 o’clock, filtering/fold CCW, crush/resonance CW
6 | Mode | Toggle switch | Selects the shared jack (11): Clk (tempo) or VOct (pitch)
7 | Display | 4-digit 7-segment | Current function, menu fields, parameter flashes
8 | CV A | Input (±5 V) | Modulates Parameter A (summed with knob 2); can be routed to Tone
9 | CV B | Input (±5 V) | Modulates Parameter B (summed with knob 3); can be routed to Tone
10 | Sync | Input (trigger/gate) | Hard-sync reset - restarts the waveform (audio-rate capable)
11 | Clk/VOct | Input (shared) | Tempo clock or 1 V/oct pitch, per the Mode switch (6)
12 | Out 1 | Audio output | Voice 1 (primary) - drives the EOC / default envelope
13 | Out 2 | Audio output | Voice 2 - independent function; can be frozen as a drone
14 CV Out | | CV output (DC-coupled) | Envelope follower of a voice, or a raw bytebeat DC/LFO - mode set in the Menu
15 | EOC | Gate output | End-of-cycle pulse (~10 ms), BPM-synced from Voice 1

Reading the display (7): functions show as 1-NN / 2-NN (voice + function, 0-based), 1-AA for the tuning reference, and various codes in the Menu (Section 5).

# 3. What is bytebeat?

Bytebeat is a style of music discovered and popularised by Viznut (Ville-Matias Heikkilä) in 2011. The whole instrument is a single expression:

output = f(t) | // f returns an 8-bit value 0-255

t is a counter that increments at a fixed sample rate (Ogham uses 8 kHz for its authored formulas). You feed t through arithmetic and bitwise operators - shifts, AND/OR/XOR, multiply, divide, modulo - and the low 8 bits of the result are sent to the DAC as audio. No envelopes, no note lists; the structure of the number sequence itself becomes rhythm, melody, and timbre.

A classic example is t*(((t>>12)|(t>>8))&(63&(t>>4))) - a handful of characters that produce an evolving arpeggio. It is worth seeing what that actually looks like, because it explains why bytebeat behaves the way it does:

One expression, three time scales

t * (((t>>12) | (t>>8)) & (63 & (t>>4))) — the classic bytebeat one-liner, at 8 kHz
128 steps — 16 ms | the individual numbers, stepping
1,024 steps — 0.13 s | a repeating wave, so a pitch
8,192 steps — 1 s | the pattern moving through it

Same expression in all three — no oscillator, no sequencer, just t counting up

Zoom right in and you see the individual numbers stepping - that is the waveform, and so the timbre. Pull back and those steps form a repeating wave, which is the pitch. Pull back further and the wave itself is being reshaped, and that is the rhythm and the melody.

All three come from the same expression. There is no oscillator and no sequencer to adjust separately, which is what makes bytebeat so compact - and why small changes to the constants produce wildly different results, and why it is both fascinating and hard to control.

How Ogham plays it

Each formula runs at its base rate (8 kHz for the authored bank), then is linearly interpolated up to the 48 kHz codec output for a smoother, less aliased sound.
A 32.32 fixed-point phase accumulator bridges the two rates and provides the variable playback rate (the Rate / Fine knob, or an external clock).
All maths use JavaScript ToInt32 semantics (shifts masked to & 31 , result masked to & 0xFF ) so formulas behave exactly as they do in the browser bytebeat tools they were designed in.

# 4. The functions - 100 slots

Ogham addresses 100 function slots, shown on the display as F0 - F99 (the numbering is 0-based: the first function reads 1-00 ). Turning the Func encoder (1) moves through them; the selector does not wrap (see Section 5).

What’s in the slots today

Slots | Contents
F0 - F19 | Textural (8 kHz base rate) - drones, sweeps and evolving beds.
F20 - F39 | Noise - grit, hiss and broken-radio textures.
F40 - F59 | Percussive - hits, clicks and drum-like transients.
F60 - F79 | Rhythmic - patterns and grooves that repeat.
F80 - F99 | Melodic - pitched lines and harmonic movement.
AA | The A=440 Hz tuning reference - a special slot past F99 (see Section 5, A440 reference).

Appendix A at the end of this manual lists the bank as shipped with your firmware - each function’s name and number, its actual bytebeat expression, and what the A and B knobs change in it. The bank is revised between firmware versions, so the appendix is the authority; the rest of this manual describes how the functions behave rather than naming individual ones.

Discovery

The raw formulas came out of a purpose-built bytebeat research toolchain:

GPU search - evaluating huge numbers of candidate expressions in parallel.
Neural fitness - a model trained on human preference data to score how “musical” a candidate sounds, steering the search toward usable results.

This surfaces expressions with interesting rhythmic and harmonic behaviour from an otherwise enormous and mostly-noisy search space.

Parameterisation (choosing A & B) - evolved in

To make a formula performable, two of its numbers have to become the live parameters A and B. Taking a finished formula and promoting two of its constants turns out to be the hard part:

Most constants in a bytebeat formula are critical - change one by 1 and you get silence, noise, or an unrelated sound. Only a few constants vary musically.

We tried automating that (sweeping every constant on the GPU and scoring for smoothness + variance). It mostly failed - of 75 formulas tested, 66 scored zero. The reasons are fundamental to bytebeat:

1. Integer discontinuity - changing a shift from >>8 to >>9 halves the pitch; there’s no smooth in-between, so a naive search sees only abrupt jumps.
2. Co-evolved constants - in a discovered formula every constant is tuned to work together; replace one and the interference patterns collapse.

Both problems come from the same place: the formula was finished before anyone asked whether it could be played. So the search stopped producing formulas and then parameterising them, and started evolving a and b as part of the expression. They are variables the search can use anywhere, from the first generation -not constants promoted afterwards.

That changes what a candidate has to be good at. Fitness no longer scores one sound; it renders the formula across the whole A/B plane and scores the set of sounds that come back - how far apart they are, how much of the plane is dead, and whether neighbouring settings are related or unrelated. A formula that sounds wonderful at one setting and identical everywhere else now scores badly, because that is a knob you cannot play.

How A and B change the sound

Height is how far each knob setting lands from the average sound of the surface.

a % t >> (t << (b - t) / (76 % 85)) ^ (t - (b ^ t) ^ t >> t / b) >> t

255

B

255

A

0

Slopes are where the knobs sweep the sound; flat ground is where they do nothing, and a step is where a small turn

changes the sound completely.

The search scores this shape. A formula whose surface is flat scores nothing for it, however good it sounds standing

still.

The surface above is one function’s response, measured the way the search measures it: every point is a different A and B, and the height is how far that setting lands from the average sound of the whole plane. Slopes are playable territory. Flat ground is a knob doing nothing. The steps are the integer discontinuity from the first problem above - it does not go away, it is simply now something a candidate is scored on rather than something discovered afterwards.

The co-evolved-constants problem does not go away either; it stops mattering, because nothing gets replaced. a and b were critical from the start, and the rest of the expression grew around them.

The result: on Ogham, A and B always do something for each formula - but what they do is formula-specific, and part of the instrument is exploring it. Expect plateaus and sudden jumps as well as smooth sweeps; all three are visible in the surface above, and all three are in the bank. (The Smooth q option, Section 5, tames the abrupt jumps when you want glide.)

Parameter behaviour on the module

A and B are each 0-255, set by the knobs (and CV), and fed to both voices.
There are no hidden per-formula ranges or stored defaults - the knob position is the value, always. Selecting a new function keeps your current A/B (it just reinterprets them), which maximises exploration and keeps the two voices’ parameters predictable.
Because formulas use A/B differently, expect some knob positions to be silent or harsh on some formulas - that’s the territory; sweep to find the sweet spots.
A few formulas mention only one of A and B, or neither; on those slots the other knob does nothing. Appendix A shows which, since the expressions are printed exactly as the module evaluates them.

One-shots - functions that fire once

Seventeen of the hundred are one-shots. They make their sound over the first fraction of a second to a few seconds, then settle to a steady value - and a steady value is silence at an AC-coupled output. They are not broken; that is the shape of a crash, a snare or a fall.

F2 , F16 , F27 , F37 , F39 , F40 , F41 , F48 , F51 , F52 , F53 , F54 , F55 , F56 , F58 , F59 , F96 .
Eleven of the seventeen are in the percussive twenties of the bank, which is where you would expect them.

Selecting a function restarts it, so a one-shot fires as soon as you land on it and you can audition the whole bank by turning Func. To hear it again, trigger Sync - every edge restarts the waveform. That is what one-shots are for: patch a clock division into Sync and they become a rhythmic voice.

Match the trigger rate to the length. The shortest are well under a second ( F59 Aliasing Hit is about half a second, F53 Ringmod Hit about three quarters); the longest run for a minute or more ( F37 Jet Phase, F27 Hunt The Wumpus). A one-shot triggered slower than its own length simply leaves a gap.

Other functions can become one-shots at particular A and B. Eleven more - F9 , F19 , F24 , F25 , F28 , F31 , F38 , F50 , F64 , F83 , F95 - run continuously across most of their range but fall silent in a corner of it. If a function that was playing goes quiet as you turn a knob, that is usually what has happened: move A or B back, or trigger Sync to restart it.

A separate reason for silence: the LPG. The internal low-pass gate is independent of all of this. If it is switched on (Menu field 18, Lp.NN ) and nothing is patched to Sync, both outputs stay shut whatever function is selected. The two can also compound - a one-shot behind a closed gate is silent twice over. Check the LPG first; see Troubleshooting if in doubt.

# 5. Controls - full reference

This section details every control. Numbers in bold refer to the panel map in Section 2.

Func encoder (1) - the heart of the interface

The Func encoder has two modes. SELECT mode chooses each voice’s function; MENU mode is the effects & settings menu (see below). A long press toggles between them.

Gesture | In SELECT mode | In MENU mode
Turn | Set the selected voice’s function ( F0 - F99 , then AA ; no wrap) | Move through the menu fields (no wrap, accelerating)
Short click | Switch voice (Out 1 ↔ Out 2) | Edit / commit the current field
Long press (~0.6 s) | Enter the Menu | Exit the Menu (from anywhere, incl. mid-edit)
Hold during power-on | Factory reset (functions → F0 , menu → defaults)

No wrap-around: the selector clamps at the ends - a hard crank reliably slams to F0 at one end and AA at the other, instead of looping around. The Menu’s field list clamps the same way.
Acceleration: turn slowly for single steps (one function per detent); spin faster to jump several at a time (roughly ×2 / ×4 / ×8 with turn speed), so you can cross the 100-slot range quickly and still land precisely. The Menu’s fields accelerate too, on a gentler curve (up to ×3) suited to its much shorter list -a brisk crank crosses the whole Menu in a few detents, while a deliberate turn always moves exactly one field.
Editing menu values: in MENU mode, turn to move through fields; click to start editing the highlighted field (its value flashes while editing); turn to change it; click again to commit.
Display: 1-07 = Out 1 playing function 7 (0-based; first slot is 1-00 ); 2-14 = Out 2 playing function 14; 1-AA = Out 1 on the A440 reference.

The Menu (1) - effects chain + settings

A long press on Func opens the Menu. It holds the FX chain (the modulation effects) plus a set of global settings (the CV-output mode with its slew and hold, the internal LPG, CV→Tone routing, parameter smoothing, the Out 2 drone, and the display’s brightness and auto-off).

Navigate with turn; click to edit a field (its value flashes while editing); turn to change it; click to commit; long-press to exit. The field list does not wrap - it stops at the first and last field - and accelerates with turn speed, so a crank reliably slams to either end. Everything in the Menu is saved to flash, and the performance knobs (A, B, Rate / Fine, Tone) keep working while it’s open.

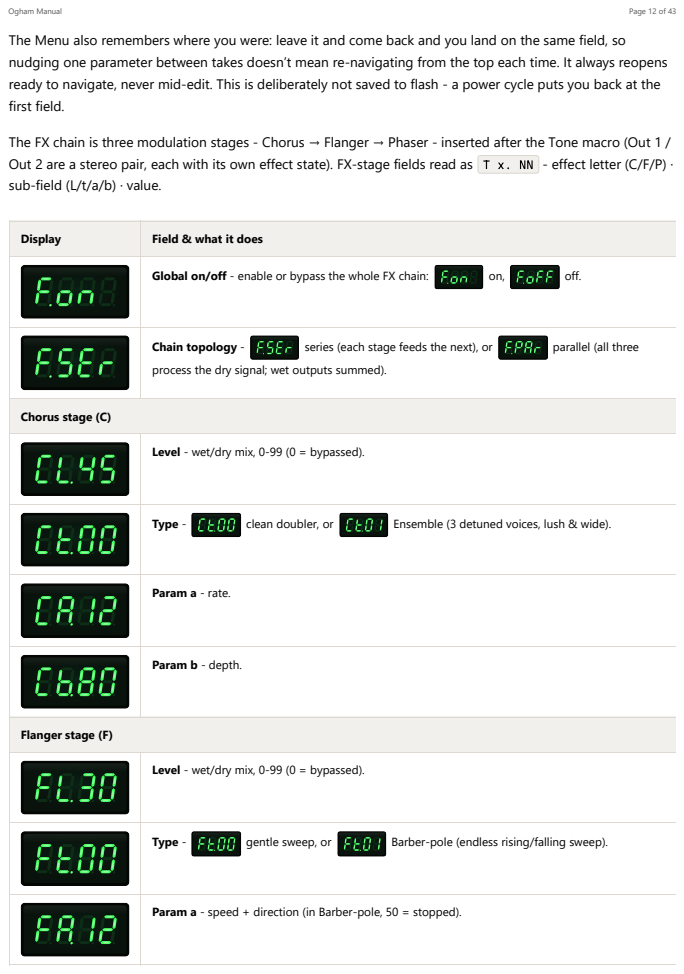
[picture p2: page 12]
Chorus stage (C); Flanger stage (F)

The Menu also remembers where you were: leave it and come back and you land on the same field, so
nudging one parameter between takes doesn’t mean re-navigating from the top each time. It always reopens
ready to navigate, never mid-edit. This is deliberately not saved to flash - a power cycle puts you back at the
first field.

The FX chain is three modulation stages - Chorus → Flanger → Phaser - inserted after the Tone macro (Out 1 /
Out 2 are a stereo pair, each with its own effect state). FX-stage fields read as T x. NN - effect letter (C/F/P) ·
sub-field (L/t/a/b) · value.

Display | Field & what it does

Global on/off - enable or bypass the whole FX chain: on, off.

Chain topology -series (each stage feeds the next), or parallel (all three process the dry signal; wet outputs summed).

Level - wet/dry mix, 0-99 (0 = bypassed).

Type -clean doubler, or Ensemble (3 detuned voices, lush & wide).

Param a - rate.

Param b - depth.

Type -gentle sweep, or Barber-pole (endless rising/falling sweep).

Param a - speed + direction (in Barber-pole, 50 = stopped).

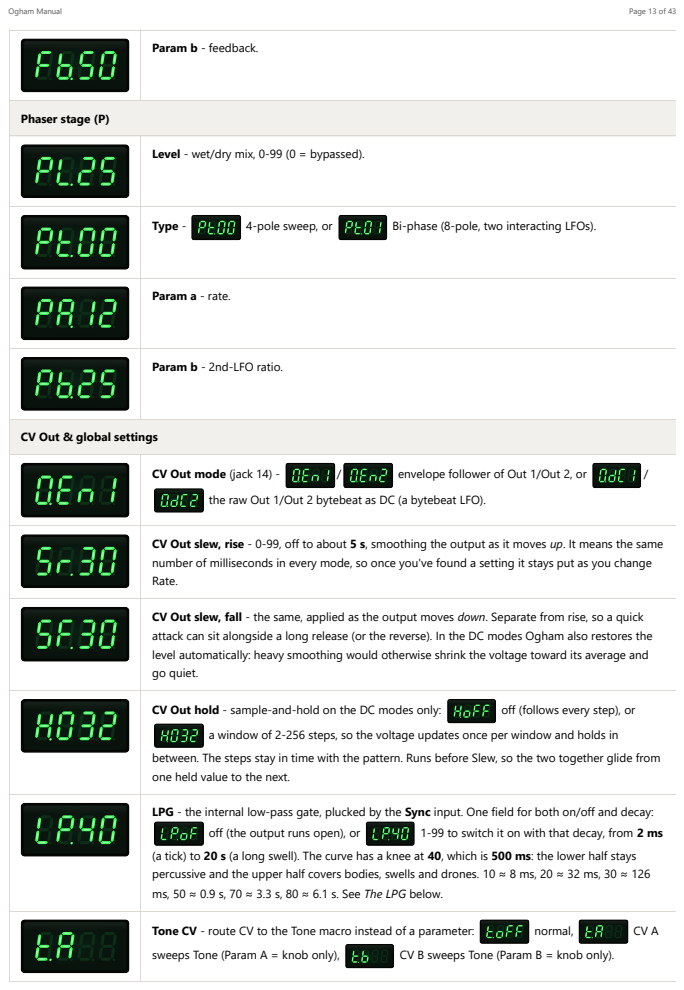
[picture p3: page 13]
Param b - feedback.; Phaser stage (P)

Level - wet/dry mix, 0-99 (0 = bypassed).

Type -4-pole sweep, or Bi-phase (8-pole, two interacting LFOs).

Param a - rate.

Param b - 2nd-LFO ratio.

CV Out & global settings

CV Out mode (jack 14) -/ envelope follower of Out 1/Out 2, or / the raw Out 1/Out 2 bytebeat as DC (a bytebeat LFO).

CV Out slew, rise - 0-99, off to about 5 s, smoothing the output as it moves up. It means the same number of milliseconds in every mode, so once you've found a setting it stays put as you change Rate.

CV Out slew, fall - the same, applied as the output moves down. Separate from rise, so a quick attack can sit alongside a long release (or the reverse). In the DC modes Ogham also restores the level automatically: heavy smoothing would otherwise shrink the voltage toward its average and go quiet.

CV Out hold - sample-and-hold on the DC modes only: off (follows every step), or a window of 2-256 steps, so the voltage updates once per window and holds in between. The steps stay in time with the pattern. Runs before Slew, so the two together glide from one held value to the next.

LPG - the internal low-pass gate, plucked by the Sync input. One field for both on/off and decay: off (the output runs open), or 1-99 to switch it on with that decay, from 2 ms (a tick) to 20 s (a long swell). The curve has a knee at 40, which is 500 ms: the lower half stays percussive and the upper half covers bodies, swells and drones. 10 ≈ 8 ms, 20 ≈ 32 ms, 30 ≈ 126 ms, 50 ≈ 0.9 s, 70 ≈ 3.3 s, 80 ≈ 6.1 s. See The LPG below.

Tone CV - route CV to the Tone macro instead of a parameter: normal, CV A sweeps Tone (Param A = knob only), CV B sweeps Tone (Param B = knob only).

Smooth ( q ) - A/B parameter interpolation: off (raw), or a grid step 4-128 that crossfades the formula output between grid points so A/B sweeps glide (smaller = finer).

Drone - Out 2 decouple / freeze: freeze Out 2 as an independent drone (own pitch + A/B, bypasses Tone + FX), live. The frozen pitch + A/B persist across power cycles.

Display - brightness and auto-off in one field. The last digit is the brightness, 0 (dimmest) to 7. A first digit of 1 adds auto-off: the display goes dark one second after you last turned the encoder
or a knob, and lights again as soon as you touch one. So | 00-07 is always on, and
10-17 is auto-off (the default, at brightness 4). One detent takes you from 07 to 10, and the brightness changes as you edit, so you can judge it by eye. The display's LED drive can add a faint buzz to the outputs; auto-off keeps it away while you're playing hands-off, and a lower brightness makes it quieter when the display is on.

A & B knobs (2, 3) - formula parameters (knob + CV)

Range: 0-255 each, shared by both voices.
Knob + CV are summed in hardware. The knob sets the base value; CV offsets it bipolarly around that point; the sum is clamped 0-255.
CV is ±5 V bipolar (8, 9). With the knob centered, ±5 V sweeps the full range (with a little headroom). With the knob toward an extreme, CV has room only in the other direction (e.g. knob full up → only negative CV does anything).
Moving Rate briefly flashes what it is doing: the playback multiplier when free-running ( 1.0 , 0.25 , 64 ), or the fine tune in semitones off the centre detent when the Mode switch is on V/oct ( 0.0 , -1.5 , 12.0 ). Under a live clock it flashes the clock ratio instead.
Moving A or B briefly flashes its value on the display ( A nnn / b nnn , ~1 s), showing the combined knob + CV value. The flash is triggered by turning the knob (not by CV alone), but once shown it tracks live CV changes until it times out.
Unpatched CV jack = 0 V, so the knob alone sets the value.
Either channel’s CV can be re-routed to the Tone macro - see Tone CV.

Rate / Fine knob (4) - playback rate, or V/oct fine-tune

The label reflects its two jobs, one per Mode:

In Clk/normal mode - Rate: playback rate, 1/64×-64× exponential, 12 o’clock = 1× (native speed). It stretches/compresses time for both voices (it scales the shared phase accumulator) - a coarse pitch/tempo control. With an external clock present, the knob changes character: it becomes a quantized clock multiplier/divider (see Clk input).
In VOct mode - Fine: the knob is a bipolar ±12-semitone fine tune (12 o’clock = 0). Pitch comes from the V/oct CV; the knob trims it, so Ogham can be tuned to another oscillator by ear.

Tone knob (5) - bipolar tone macro

One knob, two opposite characters, clean in the centre detent - the only position with no processing. It applies equally to both voices (unless Out 2 is decoupled). Output level is fixed at unity - use a downstream VCA/mixer. Both endpoints and the centre are calibrated to the physical knob positions.

You find the clean position by feel: the knob detents there, and the detent is calibrated to sit inside the clean band rather than at its edge. Earlier firmware lit a decimal point to confirm it, which was worth having when the knob was smooth and noon had to be judged by eye. With a detented knob the indicator was telling you something your fingers already knew, so it was removed in v1.18.

From center… | Early travel | Further travel
CCW ⟲ | Low-pass filter sweeps closed (smooths/darkens) | Drive → wavefolder → saturation (re-synthesises rich harmonics from the smoothed wave)
CW ⟳ | Sample-rate reduction + saturation ramp in, and a resonant band-pass opens (cutoff rising, bandwidth narrowing) | Adds overdrive/distortion grit; the band-pass sweeps up into a tight resonant peak (gritty, vocal, crushed)

The CW side stacks four stages - sample-rate reduction (exponential), soft saturation, overdrive/distortion (drive into a hard clip), and a resonant band-pass sweep whose cutoff and resonance rise across the throw. So CCW = warm/folded, CW = gritty resonant crush, center = clean. Via Tone CV, CV A or B can sweep this macro hands-free.

Mode switch (6) - Clk ↔ VOct

A toggle that selects what the shared Clk/VOct jack (11) does:

Clk - the jack is an external tempo/clock input (see Clk input).
VOct - the jack is a 1 V/oct pitch input (see VOct input).

The switch changes the jack’s role immediately; the rest of the panel keeps working as normal.

Flipping it does move the pitch, by a little under a semitone, and that is deliberate rather than a fault. The two modes measure from different places: in Clk the Rate knob’s centre is the function’s own natural speed, and in VOct it is concert pitch. Those cannot be the same number - see Why the pitch shifts when you flip the switch, below.

Sync input (10) - hard-sync reset

A rising edge resets t to 0 for both voices (restarts the waveform).
Implemented as a hardware interrupt, applied sample-accurately - so it works cleanly from slow triggers all the way up to audio-rate hard sync: drive it from an oscillator and Ogham locks to that pitch with bytebeat timbre.

Catches narrow trigger pulses (edge-triggered, not width-dependent).
Exception: a decoupled Out 2 (drone) free-runs and ignores Sync; the reset still applies to Out 1. The same edge also plucks the internal LPG, when it is switched on (below).

Gotcha: a formula that starts silent

Many formulas open with a flat run - a stretch at the very beginning where the expression evaluates to the same number over and over, which is silence. Played normally you never notice it, because t runs straight past in a fraction of a second and never comes back.

Hard sync changes that. Every rising edge restarts the formula at t = 0 , so what you hear is only ever its opening, repeated. If that opening is silent and the sync period is shorter than it, the formula never reaches its audible part and the output stays quiet - however far you turn A and B.

It shows up as a formula that sounds fine free-running going silent the moment Sync is patched, or one that plays at low notes and drops out as you move up the keyboard: a higher note is a shorter window, so less of the formula is reached.

Three ways out, in the order worth trying:

Turn the Rate knob up. Under hard sync the Rate knob is a timbre control - it sets how much of the formula is covered between one sync edge and the next. Raising it reaches further in each cycle, which is usually enough on its own.
Sync more slowly, or play lower. A longer window reaches further in.
Choose a different formula. The openings vary enormously: most are audible within a few dozen steps, a handful take thousands.

This is a property of the formulas rather than a fault, and it is why a hard-synced patch can behave quite differently from the same formula free-running.

The LPG - internal low-pass gate

Ogham has a low-pass gate on its output, off by default and switched on from the Menu ( Lp.NN ). It is the classic Buchla-style pairing: one envelope drives a VCA and a low-pass filter together, so a quiet moment is also a dark one. That coupling is what makes it sound like a struck object decaying rather than a volume fade -Ogham’s raw bytebeat, bright and relentless by nature, becomes a plucked, resonant body.

The filter deliberately runs ahead of the VCA: it darkens faster than the note gets quieter, so brightness collapses early in the decay while the level is still up. That is what gives the gate its bite rather than a polite fade.

Trigger: the Sync input. Every rising edge fires the gate - the same edge that resets the waveform, so a single trigger both restarts the timbre and plucks it. Patch a trigger sequencer into Sync and Ogham plays notes.
Attack: fixed and sharp (under a millisecond), so the transient always has bite. It shortens further at the fastest decays, so a 2 ms setting really is a tick.

Decay shares the Lp.NN Menu field with on/off - Lp.oF is off, 1-99 switches it on with that decay, 2 ms to 20 s. The curve is deliberately lopsided: a knee at 40 = 500 ms keeps the percussive material in the lower half (0 ≈ 2 ms, 10 ≈ 8 ms, 20 ≈ 32 ms, 30 ≈ 126 ms) and hands the upper half to bodies and swells (50 ≈ 0.9 s, 70 ≈ 3.3 s, 80 ≈ 6.1 s, 99 = 20 s). The figure is the real length of the note - the envelope reaches actual silence at that time rather than trailing off. The fall is also flatter than a textbook exponential, so a note holds its body and then drops away instead of collapsing the instant it is struck.
Retriggering mid-decay restarts the attack from the current level, so fast trigger streams swell rather than click.

Two things worth knowing:

With the LPG on and nothing patched to Sync, the module is silent - the gate is shut and waiting. That is the nature of an LPG, not a fault. Switching it on in the Menu plucks it once so you can hear the setting; after that it needs triggers.
A decoupled Out 2 (drone) is not gated. The drone deliberately ignores Sync, so it keeps running underneath while Out 1 is plucked - one patch gives you a sustained drone and a rhythmic voice.

The LPG sits last in the chain, after Tone and the FX, so it gates the finished sound. CV Out follows the gated audio, which makes it a ready-made envelope for the rest of your rack.

Clk input (11, Mode = Clk) - tempo / clock

A clock input via a comparator (accepts any Eurorack clock/gate/audio level). It sets the bytebeat playback rate.

Send it one pulse per beat - quarter notes, the division most clocks put out by default. A quarter note at 120 BPM is 2 Hz, and that plays at 1× (native speed); a faster clock plays faster, proportionally. Tempos from about 24 BPM upwards are tracked.

Nothing checks what you actually send, and the rate simply scales with it - a sixteenth-note clock at the same tempo runs the engine 4× faster, a bar clock 4× slower. Both still work; use the Rate / Fine knob’s quantized multiply/divide to bring the result back where you want it.

Edges are timed in hardware (stable, jitter-free) and median-filtered.

Quantized multiply / divide (Rate / Fine knob): with a clock present, the Rate / Fine knob (4) stops being a continuous trim and instead snaps to clean power-of-two ratios of the clock rate. 12 o’clock = 1× (play at the clock rate); clockwise multiplies (×2, ×4, ×8, ×16, ×32); counter-clockwise divides (÷2 … ÷32). Because “rate” time-stretches the whole formula, a multiply/divide shifts pitch and timbre together with the tempo - it is not a pure tempo divider.

As you turn the knob under a clock, the display briefly flashes the selected ratio: a multiply is a bare number -
(×4) - and a divide is the same number with a small bar to its left - | (÷8), | (÷32).

Freeze / hold on cable-pull: when a running clock stops - you pull the cable - Ogham holds the last tempo and keeps playing at it, rather than jumping to whatever the knob says. This is the least-surprising result when a cable is yanked mid-pattern.

Re-lock: if an edge arrives later (a slow clock, or a resumed sequencer), Ogham re-syncs to it and tracks again - so a genuinely slow clock keeps working; only true silence stays frozen.
Take back control: move the Rate / Fine knob past a small deadband to drop the held clock and return to continuous rate control.
Consequence: if you pause your sequencer (the clock genuinely stops), Ogham keeps playing at the held tempo instead of stopping - nudge the knob to go manual.
Because the held tempo simply continues, there is no audible “revert” glitch on a pull, and slow clocks no longer risk a dropout between their beats. (The jacks still have no cable-detect switch - a future hardware revision adds true detection - but freezing sidesteps the old slow-clock timeout entirely.)

VOct input (11, Mode = VOct) - pitch

With the Mode switch on VOct, the shared jack becomes a 1 V/oct pitch CV that drives the playback rate. The formula plays out as normal - nothing is cut short - and everything in it speeds up or slows down together.

That is what makes it track: if a formula contains a repeating pattern, playing it twice as fast doubles that pattern’s frequency, which is exactly one octave. Every partial moves with it, so the character is preserved the way varispeed on tape preserves it.

Formulas with a natural tone play melodically. Roughly a third of the bank has a steady enough pulse to hold a note; those track 1 V/oct properly.
The rest become an exponential speed control - still useful, just not pitched. Nothing goes silent, which is the important part: every formula remains playable in VOct mode.
The Rate / Fine knob (4) is a bipolar fine tune, ±12 semitones with 12 o’clock at zero - continuous, so you can tune Ogham to another oscillator by ear. The V/oct CV adds 1 V/oct on top.
The input is unipolar 0-5 V, so the CV spans about five octaves upward from wherever the fine tune sits. Tuning is one global correction, not a per-formula table: every formula in the bank with a usable pulse repeats over a power-of-two number of steps, so they all sit at the same offset from concert pitch and differ only by octaves. The firmware corrects that offset once, so the whole melodic set is in tune with itself and with the AA 440 Hz reference.
Pitch and evolution are linked. A low note plays the formula slowly, so it evolves slowly; a high note races through it. That is inherent to changing speed, and the Sync input is how you get around it - see below.
Formulas differ in how fast their natural pulse runs - across the bank it spans about seven octaves - so which register a formula lands in is a property of the formula, not something the fine tune can move it out of. The ones that play in a musical range directly are those with a slower pulse; the faster ones are better driven through Sync, where the sync sets the pitch outright.

Why the pitch shifts when you flip the switch

Leave the Rate / Fine knob alone and move the Mode switch between Clk and VOct, and the pitch steps by about three quarters of a semitone. Nothing is broken. The two modes are measuring from different reference points, and they have to be.

In Clk, the knob at 12 o’clock means 1×: the function running at its own natural speed, exactly as written. That has to stay exact, because it is what makes an external clock lock. A function whose pattern repeats every 256 steps runs at 8000 ÷ 256 = 31.25 Hz at 1×, and 31.25 Hz is not a note - it sits about three quarters of a semitone below C1.

In VOct, 0 V has to be a note: C1, at 32.70 Hz. Getting there means running the function about 4.6 % faster than its natural speed, and that is the correction described above - the single number that brings the whole melodic set into tune.

So the same knob position means “as written” in one mode and “in tune” in the other, and the gap between them is the correction. Applying it in Clk as well would put every clocked pattern 4.6 % off the beat, which is a far worse trade: a drifting pattern is obvious, where three quarters of a semitone on a free-running drone is not.

If you are matching a pitch by ear across a mode change, expect to retune with the fine tune. If you are clocked, the question does not arise.

Holding the timbre still across a melody. Patch the Sync input (10) from an oscillator tracking the same 1 V/oct. The sync then sets the pitch, and because both the sync frequency and the playback rate scale together, the slice of the formula heard per cycle stays the same size at every note. The result is a wavetable-style oscillator whose timbre does not drift as you play - and it works for any formula, tonal or not. If a formula falls silent under sync, see the gotcha in the Sync section - its opening is probably a flat run.

A440 reference ( AA slot)

Past F99 sits a special AA slot - a built-in A = 440.0 Hz tuning reference. Select it on Out 1 ( 1-AA ) and Ogham emits a steady 440 Hz tone for tuning oscillators or your ear.

The pitch is fixed and exact - it ignores the Rate / Fine knob, external clock, and V/oct, so you can’t accidentally detune it.
It’s tuned in firmware against the real hardware, reading 440.0 Hz on a meter.
Use it on Out 1 (the primary voice, which clocks the engine); on Out 2 it plays but is not guaranteed to be 440 Hz.

Outputs (12-15)

Output | Carries
Out 1 (12) | Voice 1 - the primary voice. Shaped by the Tone macro + FX.
Out 2 (13) | Voice 2 - an independent formula, same Tone + FX (unless frozen via Drone).
CV Out (14) | Mode-selectable (Menu) - envelope follower of either voice, or a raw bytebeat as a DC/LFO source. See below.
EOC (15) | End-of-cycle pulse (≈10 ms), BPM-synced to Voice 1’s detected tempo.

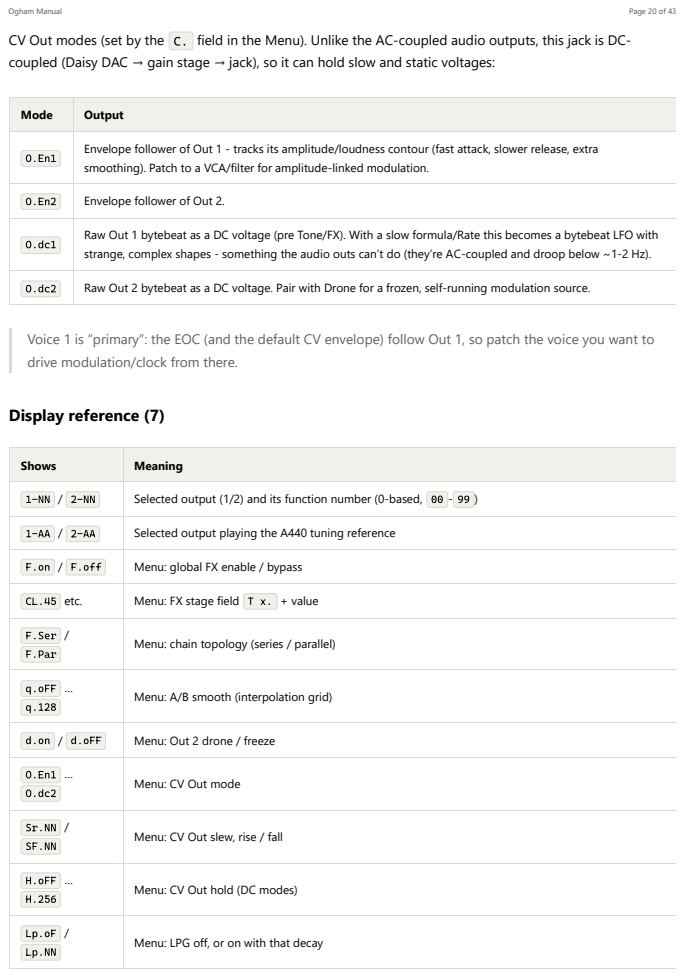
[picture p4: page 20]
Display reference (7)

CV Out modes (set by the C. field in the Menu). Unlike the AC-coupled audio outputs, this jack is DC-
coupled (Daisy DAC → gain stage → jack), so it can hold slow and static voltages:

Mode | Output

O.En1 | Envelope follower of Out 1 - tracks its amplitude/loudness contour (fast attack, slower release, extra smoothing). Patch to a VCA/filter for amplitude-linked modulation.

O.En2 | Envelope follower of Out 2.

O.dc1 | Raw Out 1 bytebeat as a DC voltage (pre Tone/FX). With a slow formula/Rate this becomes a bytebeat LFO with strange, complex shapes - something the audio outs can’t do (they’re AC-coupled and droop below ~1-2 Hz).

O.dc2 | Raw Out 2 bytebeat as a DC voltage. Pair with Drone for a frozen, self-running modulation source.

Voice 1 is “primary”: the EOC (and the default CV envelope) follow Out 1, so patch the voice you want to
drive modulation/clock from there.

Shows | Meaning

1-NN / 2-NN | Selected output (1/2) and its function number (0-based, 00 - 99 )

1-AA / 2-AA | Selected output playing the A440 tuning reference

F.on / F.off | Menu: global FX enable / bypass

CL.45 etc. | Menu: FX stage field T x. + value

F.Ser / F.Par | Menu: chain topology (series / parallel)

q.oFF … q.128 | Menu: A/B smooth (interpolation grid)

d.on / d.oFF | Menu: Out 2 drone / freeze

O.En1 … O.dc2 | Menu: CV Out mode

Sr.NN / SF.NN | Menu: CV Out slew, rise / fall

H.oFF … H.256 | Menu: CV Out hold (DC modes)

Lp.oF / Lp.NN | Menu: LPG off, or on with that decay

Shows | Meaning
t.oFF / t.A / t.b | Menu: CV→Tone routing
br.00 … br.17 | Menu: display brightness (last digit) + auto-off (first digit 1)
(dark) | Auto-off: one second after the last encoder or knob movement. Any of them lights it again; the Mode switch, CV and gates don’t. It stays lit in the Menu
A nnn / b nnn | Brief flash of Param A / B as you adjust it (~1 s)
1.0 / 0.25 / 64 | Playback rate as a multiplier, while turning Rate free-running
0.0 / -1.5 | V/oct fine tune in semitones off the centre detent, while turning Rate

Power-on sequence

At power-up Ogham shows, in order:

1. A startup animation - a single segment chases the outer border of the display for about a second.
2. The firmware version - M.mm for about a second: 1.03 is major version 1, minor 03. Worth noting before you update, since it identifies the installed build. The module also stores it, so a later update can tell which version it is replacing.
3. Normal operation - the function display, and audio begins. With auto-off on (the default), the display goes dark a second later until you touch a control.

Firmware 1.00 predates the version display and shows nothing at step 2; if the animation runs straight into the function display, that is what you have. See Section 12 to update.

To factory-reset, hold the Func encoder through this sequence (see below).

Persistence & factory reset

Your two function selections and the entire Menu (FX levels/types/params, topology, global on/off, smooth q , drone, CV-out mode, Tone-CV routing, LPG on/off and decay, display brightness and auto-off) are saved to flash and restored on power-up (a few seconds after you stop changing them). A frozen drone’s pitch and A/B are saved too.
Factory reset: hold the Func encoder while powering on → both voices return to F0 and the Menu returns to defaults.
Knob-driven values (A, B, Rate / Fine, Tone) always follow the live knobs and are not stored - the panel always reflects what’s playing.

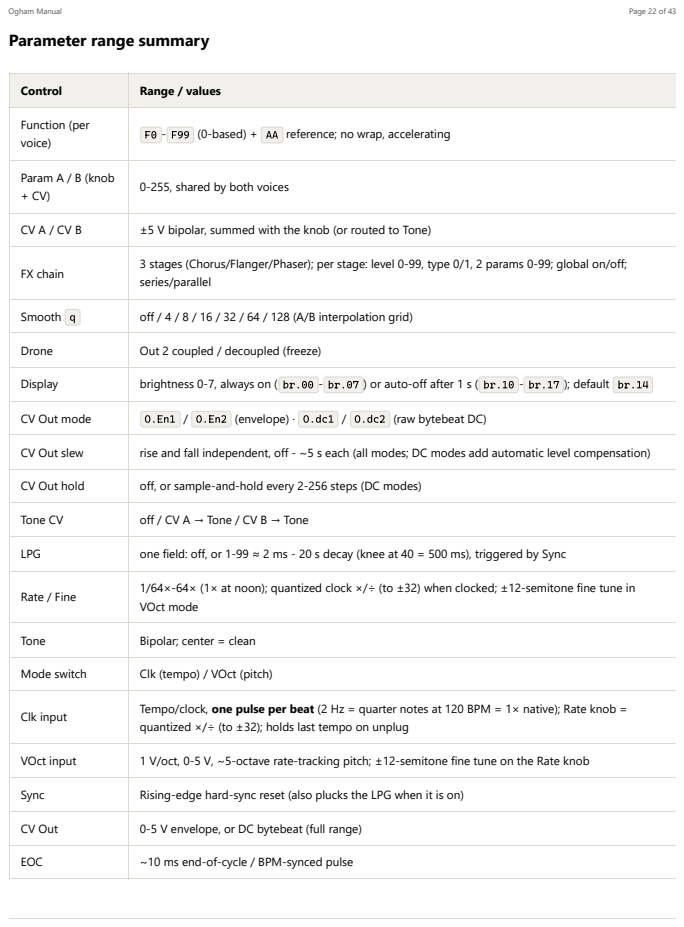
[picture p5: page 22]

Parameter range summary

Control | Range / values

Function (per voice) | F0 - F99 (0-based) + AA reference; no wrap, accelerating

Param A / B (knob + CV) | 0-255, shared by both voices

CV A / CV B | ±5 V bipolar, summed with the knob (or routed to Tone)

FX chain | 3 stages (Chorus/Flanger/Phaser); per stage: level 0-99, type 0/1, 2 params 0-99; global on/off; series/parallel

Smooth q | off / 4 / 8 / 16 / 32 / 64 / 128 (A/B interpolation grid)

Drone | Out 2 coupled / decoupled (freeze)

Display | brightness 0-7, always on ( br.00 - br.07 ) or auto-off after 1 s ( br.10 - br.17 ); default br.14

CV Out mode | O.En1 / O.En2 (envelope) · O.dc1 / O.dc2 (raw bytebeat DC)

CV Out slew | rise and fall independent, off - ~5 s each (all modes; DC modes add automatic level compensation)

CV Out hold | off, or sample-and-hold every 2-256 steps (DC modes)

Tone CV | off / CV A → Tone / CV B → Tone

LPG | one field: off, or 1-99 ≈ 2 ms - 20 s decay (knee at 40 = 500 ms), triggered by Sync

Rate / Fine | 1/64×-64× (1× at noon); quantized clock ×/÷ (to ±32) when clocked; ±12-semitone fine tune in VOct mode

Tone | Bipolar; center = clean

Mode switch | Clk (tempo) / VOct (pitch)

Clk input | Tempo/clock, one pulse per beat (2 Hz = quarter notes at 120 BPM = 1× native); Rate knob = quantized ×/÷ (to ±32); holds last tempo on unplug

VOct input | 1 V/oct, 0-5 V, ~5-octave rate-tracking pitch; ±12-semitone fine tune on the Rate knob

Sync | Rising-edge hard-sync reset (also plucks the LPG when it is on)

CV Out | 0-5 V envelope, or DC bytebeat (full range)

EOC | ~10 ms end-of-cycle / BPM-synced pulse

# 6. Working with two voices

Ogham is really two bytebeat voices sharing one time base:

Out 1 (12) = formula1(t), Out 2 (13) = formula2(t).
By default they share the Rate, A/B params, the Tone macro, and the FX chain, but each plays its own function on its own output.
Each voice keeps independent effect state, so the FX (chorus/flanger/phaser) give Out 1 and Out 2 their own movement - a natural stereo spread.

To set them up: turn Func to set Out 1’s function → short-click to Out 2 → turn to set its function → short-click back to Out 1 as needed.

Decoupling Out 2 (Drone). The Menu’s d.on toggle breaks the link: Out 2 freezes into an independent drone at its current pitch and A/B, bypassing Tone and FX, while Out 1 stays fully live. This turns the pair into a held drone + a performable lead (see Section 5, Drone).

Ideas this enables

Two different formulas → a layered/stereo pair from one module.
Same formula on both → a doubled, FX-widened mono-to-stereo voice.
Freeze + perform → d.on a lush Out 2 drone, then solo over it on Out 1.
CV/gate from Out 1 only → use Voice 1 as a “lead” that also drives the envelope and EOC outs, with Voice 2 as a free companion texture.

# 7. Patch ideas & use cases

Voice / melodic

Layered lead + texture: different formulas on Out 1 and Out 2 to separate channels for an instant stereo/dual-voice patch; sweep A/B to morph both.
V/oct melodies: switch Mode → VOct, patch a sequencer/keyboard’s 1 V/oct into the Clk/VOct jack, and use the Rate / Fine knob to tune to the rest of the patch. Formulas with a steady pulse play chromatically; the rest turn the CV into an exponential speed control.
Wavetable-style lead: as above, but also patch a VCO tracking the same 1 V/oct into Sync. The sync sets the pitch and the window stays the same size at every note, so the timbre holds still across the melody.
Plucked notes: switch the LPG on ( Lp.20 , i.e. on with a short decay) and drive Sync from a trigger sequencer - each trigger restarts the waveform and plucks the gate, so Ogham plays discrete percussive notes instead of a continuous stream. Add V/oct on the Clk/VOct jack and you have a playable tuned instrument.
Drone + pluck from one module: LPG on, drone on ( d.on ). Out 2 holds a frozen drone (ungated) while Out 1 plays plucked notes over it.
Hard-sync lead: patch a VCO (saw/pulse) into the Sync input and take Out 1 - Ogham becomes a hard-synced timbre that tracks the VCO’s pitch; A/B shape the sync’d timbre.
Tune up: select AA on Out 1 for a 440 Hz reference to tune your oscillators.

Rhythmic / clocked

Tempo-locked patterns: Mode → Clk, feed the Clk input one pulse per beat from your master clock (2 Hz at 120 BPM) so Ogham’s rhythm rides your tempo; use the Rate / Fine knob to pick a clean multiply/divide (÷32 … ×32) for half/double-time feels, and reset phase per bar with the Sync input. Pull the clock and it holds the tempo.
Rack clock source: take the EOC out (BPM-synced to the playing formula) to drive sequencers, dividers, or envelopes - a generative clock from the music itself.
Drum/percussion voice: short, sync-reset hits - trigger the Sync input from a sequencer so each step restarts the waveform; pick percussive formulas and use Tone CW for crunch.

Timbre / texture

Modulation FX: long-press into the Menu and bring up Chorus for width, Flanger for sweeps, or Phaser for swirl - try the Barber-pole flanger for an endless rising sweep, or the Ensemble chorus for a lush detuned spread. Flip F.Ser / F.Par to hear series vs parallel.
Hands-free Tone (Tone CV): set t.A , patch an LFO/envelope into CV A, and let it sweep the whole clean→crush macro while knob A sets Param A.
Tone performance: ride the Tone knob live - CCW for warm folded leads, CW for thin/clicky/decimated breakdowns, snap back to center for clean.

Evolving drone: set a low Rate, hold a formula, then d.on to freeze Out 2 as a self-running drone while you keep playing Out 1.

Modulation / system integration

Bytebeat LFO out: set the CV Out to O.dc1 (or O.dc2 ), drop the Rate low, and use the resulting slow, strange bytebeat waveform as a DC modulation/LFO source for filters, VCAs, or wavefolders elsewhere - the audio outs can’t hold these slow shapes, but this DC-coupled jack can. Freeze Out 2
( d.on ) + O.dc2 for a stable, independent LFO. Add Hold for a stepped sample-and-hold voltage and Slew to glide between the steps; nudge the Rate knob to re-roll the shape if a setting feels dull. Envelope follower: set O.En1 (or O.En2 ) and take CV Out into a VCA, filter cutoff, or VCO index - so Ogham’s dynamics shape another voice (auto-wah, ducking, amplitude-linked timbre).
Animated timbres: patch LFOs/envelopes into CV A and CV B (centered knobs) for bipolar modulation of the formula parameters.
Generative duo: cross-patch - Ogham’s EOC clocks a sequencer whose CV drives Ogham’s A/B, and the Sync input is reset from a slow divider - a self-evolving system that never quite repeats.

Quick-start patch

1. Out 1 → mixer/speakers. Tone at 12 o’clock (clean).
2. Turn Func to choose Out 1’s function; sweep A/B to taste.
3. Rate / Fine knob to set speed (12 o’clock = native).
4. Short-click Func → set Out 2 to a second function; patch Out 2 to another channel for stereo.
5. Long-press Func into the Menu; raise a stage’s level and tweak its params (try Chorus), then long-press out.
6. Patch a clock to the Clk/VOct jack (Mode = Clk) or a 1 V/oct source (Mode = VOct), and a trigger to the Sync input (reset/sync).

# 8. Clocking, pitch & sync in depth

Ogham gives you three ways to control time and pitch, and they can be combined.

Free-running: with nothing patched (Mode = Clk, no cable), the Rate / Fine knob sets speed (1/64×-64×, 1× at noon).
Tempo / clock (Mode = Clk): the external clock sets the playback rate (the clock rate plays at 1× native; faster = faster). The Rate / Fine knob is a quantized multiply/divide of the clock - ÷32 … ×1 at noon … ×32 in powers of two. On unplug Ogham holds the last tempo and keeps playing (a later edge re-locks; nudge the Rate knob to return to continuous control).
Pitch / V-oct (Mode = VOct): a 1 V/oct CV drives the playback rate, so a formula’s own pulse tracks the CV over ~5 octaves and the formula keeps running rather than being cut short. The Rate / Fine knob is a ±12-semitone fine tune. Tuning is one global correction (validated by the AA 440 Hz reference).
Hard sync (Sync input): a rising edge restarts the waveform sample-accurately. At audio rates this is true oscillator hard sync - the waveform repeats at the input pitch for a clean, tonal note (here the Rate knob shapes timbre). At musical rates it’s a phase/one-shot reset per trigger. A great pitched path if you don’t have a dedicated V/oct source.

The Clk input sets the tempo; VOct sets pitch; the Sync input restarts the waveform. Clk and VOct share one jack (selected by the Mode switch); Sync is separate and can be combined with either (e.g. V/oct pitch + a per-bar Sync reset).

# 9. Deriving control voltages

CV Out can do two quite different jobs, and the difference matters more than the name suggests. It can follow a voice’s loudness, which behaves like any envelope follower you’ve used before. Or it can use the bytebeat’s own value as a voltage, which behaves like nothing else - and comes with a few consequences worth understanding before you decide something is broken.

How CV Out is built

bytebeat

engine

envelope

follower

Hold

(DC only)

Slew

rise / fall

level

compensation

DC modes take the raw formula value, skipping the follower

O.En1 / O.En2 follow the loudness of a voice

O.dc1 / O.dc2 use the formula value itself as a voltage | Hold and level compensation act on the DC modes only

The two families

Mode | What comes out | Good for
O.En1 / O.En2 | The amplitude contour of Out 1 / Out 2 -rectified, smoothed, always positive. | Ducking, auto-wah, opening a filter in time with the part. Predictable.
O.dc1 / O.dc2 | The formula’s own value, straight out as a voltage (before Tone and FX). | A modulation source with a character you won’t get from an LFO - but see the gotchas.

The envelope modes are the safe choice: whatever the formula is doing, its loudness contour is smooth and well-behaved. The DC modes are where the interesting material is, and where the rest of this section applies.

Hold and Slew

Two stages shape the DC modes, in this order.

Hold ( H.oFF … H.256 ) decides how often the voltage updates. Off, it follows every step of the formula. Set to a window, it takes one value per window and sits on it - a sample-and-hold clocked by the bytebeat itself. The steps stay in time with the pattern.

Slew ( Sr.NN / SF.NN ) smooths the movement, rise and fall independently. It’s a plain time - roughly 3 ms to 5 seconds - and means the same thing at any Rate, so a setting you like stays put as you speed the engine up or down.

Hold and Slew

Hold off — follows every step

Hold 32 — one value per 32 steps

Hold 32 + Slew — glides between the held values

the same 448 formula steps in each row

Together they cover most of what you’d want: raw for something jagged and detailed, Hold for a stepped sequence locked to the music, Hold plus Slew for a smooth wandering voltage.

Slew also compensates its own level in the DC modes. Smoothing a signal shrinks it toward its average - that’s unavoidable - so Ogham measures how much it lost and puts it back. There’s a ceiling: smooth a very fast LFO hard enough and there is genuinely nothing left to restore, and the output goes quiet. That’s physics, not a fault.

Gotcha 1 - where the sample lands decides everything

This is the one that surprises people, and it’s a property of bytebeat itself rather than of Ogham.

Most formulas multiply by t and keep the low 8 bits. The hold window is a power of two. So if the sample were taken exactly on the window boundary, those low bits would be zero every single time - and the output would be a constant. Not a dull voltage: a flat line.

Why the sample point matters

One function, hold window 64. Same function, same window — only the sample point differs.

the formula itself, every step | sampled on the boundary | sampled 7 steps later

Result — every sample lands on zero, so the voltage never moves

Result — the same formula, sampled 7 steps off the boundary

Ogham never samples on the boundary — this is what it is avoiding

The top row is the formula itself, every step. The red dots mark where a boundary sample lands - every one of them on zero, which is the whole problem. The green dots are the same formula and the same window, sampled seven steps later, and they land all over the waveform. The two rows below are the voltages those two choices produce.

Ogham always samples off the boundary, so you should never see the flat case. It also picks a new sample point each time you move the Rate knob, because which point you land on changes the character of the result quite a lot and there’s no way to know a good one in advance. If a setting feels dull, nudge Rate and you get a different draw of the same formula at the same speed. That is the intended way to hunt for something you like.

Gotcha 2 - some functions can only make a handful of voltages

A bytebeat formula was written to sound interesting, not to make a good control voltage, and those are different jobs. A function can sound rich and still be built from very few numbers - and if there are only a few numbers, there are only a few voltages.

The cause is usually a single operator, and it shows up plainly if you plot a function on top of every voltage it can reach:

How many voltages a function can make

Faint lines mark every value a function can reach — the trace can only ever sit on them.

t * ((t>>11 * A) & B) - 126 | A = 176 B = 204
4

voltages

multiples of 64 — a

mask leaves the

multiplier just four

values

((t | t>>1) / A) & (((B % t) ^ (23 % (t + t)) + t) << 4) | A = 101 B = 99
16

voltages

multiples of 16 — a

final AND with one

side shifted left by

four

t * ((t>>11 * A) & B) - 126 | A = 120 B = 190
32

voltages

multiples of 8 — the

same formula, opened

up by a different A

and B

The faint lines are the complete set - every value the function is capable of producing, not just the ones in view. The trace can only ever sit on them.

Each panel prints the function’s actual expression - taken from the current bank - along with the A and B it was drawn at.

The first manages just four voltages. The mask in (t»11 × A) & B leaves its multiplier only four possible values, so the output jumps between four rails with nothing in between: closer to a four-step sequencer than an LFO. The second reaches 16, where the « 4 at the end of its expression forces every value onto a multiple of 16.

The third is the same expression as the first, with different A and B - and it reaches 32. That is the clearest demonstration that the knobs matter as much as the choice of function: one setting gives a four-step stepper, another gives something eight times finer, from identical arithmetic. If a function looks promising and still won’t move, try A and B before giving up on it.

Even 32 is a staircase rather than a contour once spread across the output range, and Slew will not fill the gaps - it smooths the path between values, it cannot invent values the function never produces. The better functions in the bank reach all 256 and sweep smoothly; these three cannot, whatever you do downstream.

Gotcha 3 - a longer Hold changes the timing, not the range

Widening the hold window makes the voltage step less often. What it does not do is give the function more values to reach - that is fixed by the function and its A/B setting.

What a bigger Hold window does

Hold 16 against Hold 128, on the same stretch of each function. Dots mark the Hold 128 samples.

A function with plenty of levels — a shorter window buys detail

Hold 16

Hold 128

A function with only a few levels — the window changes timing, not range

Hold 16

Hold 128

Same range in both rows of the lower pair — only the step rate changed

The top pair is a function with plenty of levels. A short window traces a detailed contour; a long one picks a few points out of the same shape.

The bottom pair is a function with only a handful. Both windows cover about the same range, and all the longer window does is hold each value for longer.

That second case is the usual reason for “I changed Hold and nothing happened”. If the function only has a few voltages in it, every window setting looks much the same - the steps simply get wider. The fix is a different function, or different A and B, not a different window.

A long window can also actively lose range on some functions, because it keeps landing on a similar part of the pattern. One in the bank reaches 64 distinct values at a 16-step window and only 4 at 256; another drops to 2. If a long Hold goes lifeless, shorten it or nudge Rate to re-roll the sample point.

Getting a good result

Find a function with range before tuning anything else. Put the CV on a scope or a slow filter sweep and step through functions with Hold off - the usable ones move over most of the range in many small steps, rather than flicking between a few levels. It is worth a minute; it decides everything that follows. Hold sets the rhythm, Rate sets the speed. Drop Rate well below noon for LFO territory; the free-running range goes down to 1/64×.

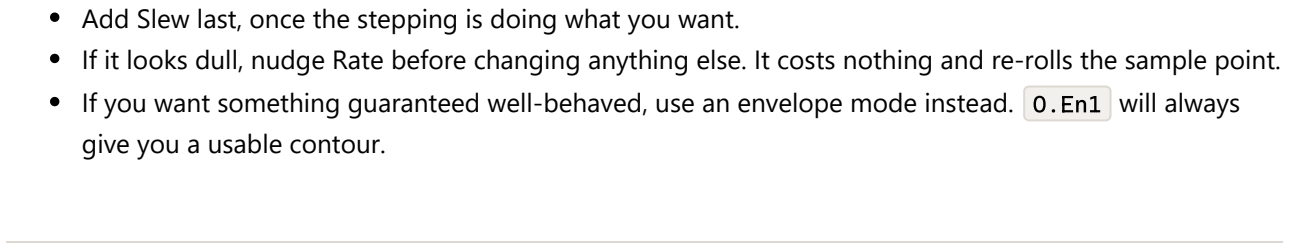
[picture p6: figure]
give you a usable contour.

Add Slew last, once the stepping is doing what you want.
If it looks dull, nudge Rate before changing anything else. It costs nothing and re-rolls the sample point. If you want something guaranteed well-behaved, use an envelope mode instead. O.En1 will always

# 10. Troubleshooting

No sound at all, but the module boots and the Menu works

Before suspecting a hardware fault, check the internal LPG (Menu field 18, Lp.NN / Lp.oF ). With it switched on and nothing patched to Sync, the gate sits fully shut on both outputs - that is the LPG working as designed, not a fault. It plucks once when you switch it on so you can hear the setting, then goes quiet again until the next trigger.

Long-press Func into the Menu, navigate to field 18, and switch it off - sound returns immediately, since the LPG is the last stage in the chain.
Or patch a trigger/gate into Sync to pluck it.

If it is back on after a power cycle, that is the saved setting doing its job, not a bug - see Persistence & factory reset above. A factory reset (hold Func at power-on) clears it back to off.

See The LPG above for the full behaviour.

A function that made a sound has gone quiet

Two independent causes, and it is worth knowing which you are looking at.

The function is a one-shot - it fired and finished. Seventeen of the bank behave this way, and eleven more do so at particular A/B settings. Trigger Sync to restart it, or turn Func away and back. See One-shots - functions that fire once in section 4 for the list.
The LPG is on with nothing patched to Sync - see above. This one silences every function, not just some, which is the quickest way to tell them apart.

The display goes dark

That’s auto-off, the default since firmware 1.19: the display goes dark one second after you last turned the encoder or a knob, and lights again as soon as you touch one. Patched CV, gates and the Mode switch don’t wake it, so a module you aren’t touching stays dark. To keep it lit, set the Menu’s last field to br.00 - br.07 (see The Menu above).

# 11. Specifications

Platform: Electro-Smith Daisy Seed (STM32H7), custom Eurorack PCB.
Format: 10 HP (50.5 × 128.5 mm panel), 32 mm deep behind the panel including power-cable clearance - skiff-friendly.
Voices: 2 independent bytebeat voices, shared time base; Out 2 decouple/freeze.
Functions: 100 slots ( F0 - F99 ), all filled (8 kHz base, interpolated to 48 kHz output) - twenty each of textural, noise, percussive, rhythmic and melodic - plus an AA A=440 Hz tuning reference. See Appendix A for the bank as shipped.
FX: 3-stage modulation chain (Chorus / Flanger / Phaser), each with a clean and a characterful variant; per-stage mix, series/parallel, global bypass; A/B interpolation (“smooth”).
LPG: internal low-pass gate (coupled VCA + 2-pole filter), sharp attack, decay 2 ms - 20 s, triggered from the Sync input.
Audio: 2 outputs (Out 1 / Out 2), ~10 Vpp (±5 V, Eurorack level), AC-coupled.
CV in: CV A, CV B (±5 V bipolar, summed with knobs, or routable to the Tone macro).
Pitch / clock in: shared Clk/VOct jack (Mode switch) - external tempo clock (one pulse per beat), or 1 V/oct rate-tracking pitch (~5 octaves).
CV out: DC-coupled; selectable envelope follower (of Out 1 or Out 2) or raw bytebeat DC/LFO (of Out 1 or Out 2).
Sync in: hard-sync reset (edge-triggered, up to audio rate).
EOC out: end-of-cycle / BPM-synced pulse (~10 ms).
Display: 4-digit 7-segment (TM1637); 8 brightness levels, optional auto-off.
Power: Eurorack ±12 V (with an on-board +5 V regulator for the Daisy); +3.3 V from the Seed. Controls: rotary encoder (Func) + 4 pots + Mode switch; settings persist to flash.

# 12. Updating the firmware

Ogham’s firmware can be updated over the same USB socket the Daisy Seed uses for power - either from your browser, with nothing to install, or with dfu-util if you would rather drive it yourself. Both write the same image by the same route; the browser simply does the talking for you.

Check what you are running first: the version appears on the display at power-up (see Power-on sequence, Section 5).

Putting the module in bootloader mode

Both methods need the Seed in its DFU bootloader:

1. Power down the case and remove the module.
2. Connect the Daisy Seed to your computer with a USB data cable - a charge-only cable will not enumerate.
3. Hold BOOT, tap RESET, then release BOOT.

Nothing visible happens: the display stays blank and the module makes no sound. That is the bootloader, not a fault.

This bootloader is in the STM32’s factory ROM and cannot be overwritten. An interrupted flash leaves a module that will not start, but never a dead one - BOOT + RESET always brings it back here to try again.

Flashing from the browser

Open the firmware page (http://localhost:4487/firmware/ogham/) and use the flasher there. It needs Chrome, Edge or Opera on desktop: Firefox and Safari have not implemented WebUSB, and the page will tell you so rather than fail silently. It also only works over https:// - WebUSB is unavailable on an insecure origin, and the page distinguishes that case from an unsupported browser, because the fix is a different one.

Click Connect module and the browser shows its device chooser. The list is filtered to devices identifying as 0483:DF11 - the STM32 bootloader - so a module in DFU mode is normally the only entry, and there is nothing to identify by guesswork. Pick STM32 BOOTLOADER , then Flash.

The page erases only the sectors the image occupies, writes it, and verifies the size and checksum of what it sent. When it finishes, power-cycle the module.

On Windows the module may not appear in the chooser at all. Browsers can only reach USB devices through WinUSB, and Windows usually binds ST’s own DFU driver first. Zadig (https://zadig.akeo.ie/) replaces the driver for STM32 BOOTLOADER with WinUSB; reconnect afterwards and it appears. macOS and Linux need no driver setup.

Flashing with dfu-util

Download the .bin from the firmware page, then:

dfu-util -a 0 -s 0x08000000:leave -D ogham-v1.18-standard.bin

The :leave matters. Without it the module stays parked in DFU mode after writing - blank display,
apparently dead - and, because USB keeps it powered, a rack power cycle will not shift it. A trailing | Error
during download get_status | is the device detaching as it restarts, not a failed write.

dfu-util does not verify by default. To check the image landed intact, read the flash back and compare it against what you downloaded:

dfu-util -a 0 -U readback.bin -s 0x08000000:128400

cmp readback.bin ogham-v1.18-standard.bin

Each release on the firmware page publishes its SHA-256 and exact byte size, so you can confirm the download before flashing as well as after. The size above is v1.18’s; use the figure for the release you are flashing.

After flashing: unplug USB before power-cycling

The Seed is powered by USB and by the Eurorack bus. With the USB cable connected, powering the case off and on does not actually reset it - the Seed never loses power, so the new firmware never starts, and the module can look broken when it is fine.

Unplug USB, then power up from the rack. You should see the startup animation, the version, and normal operation.

If the encoder turns the wrong way

Some modules use an encoder with its A/B phases swapped, and there are two builds of each release to match. If the Func encoder counts down when you turn it clockwise, you have flashed the other one -download the alternative from the firmware page and flash again. Nothing else differs between them.

# Appendix A - the formula bank

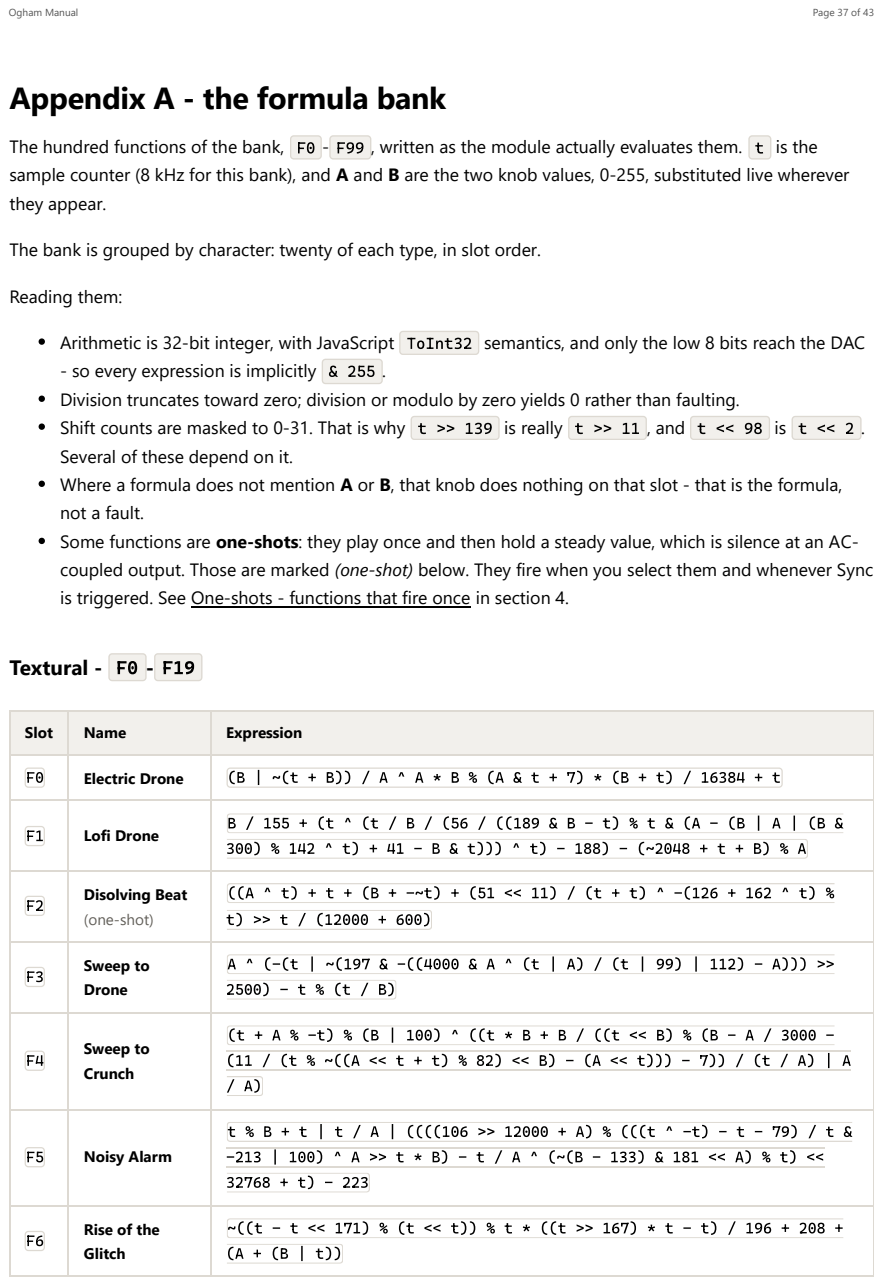
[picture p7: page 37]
Reading them:; Textural - F0 - F19

The hundred functions of the bank, F0 - F99 , written as the module actually evaluates them. t is the
sample counter (8 kHz for this bank), and A and B are the two knob values, 0-255, substituted live wherever
they appear.

The bank is grouped by character: twenty of each type, in slot order.

Arithmetic is 32-bit integer, with JavaScript ToInt32 semantics, and only the low 8 bits reach the DAC
- so every expression is implicitly & 255 .
Division truncates toward zero; division or modulo by zero yields 0 rather than faulting.
Shift counts are masked to 0-31. That is why t >> 139 is really t >> 11 , and t << 98 is t << 2 .
Several of these depend on it.
Where a formula does not mention A or B, that knob does nothing on that slot - that is the formula,
not a fault.
Some functions are one-shots: they play once and then hold a steady value, which is silence at an AC-
coupled output. Those are marked (one-shot) below. They fire when you select them and whenever Sync
is triggered. See One-shots - functions that fire once in section 4.

Slot | Name | Expression

F0 | Electric Drone | (B | ~(t + B)) / A ^ A * B % (A & t + 7) * (B + t) / 16384 + t

F1 | Lofi Drone | B / 155 + (t ^ (t / B / (56 / ((189 & B - t) % t & (A - (B | A | (B & 300) % 142 ^ t) + 41 - B & t))) ^ t) - 188) - (~2048 + t + B) % A

F2 | Disolving Beat (one-shot) | ((A ^ t) + t + (B + -~t) + (51 << 11) / (t + t) ^ -(126 + 162 ^ t) % t) >> t / (12000 + 600)

F3 | Sweep to Drone | A ^ (-(t | ~(197 & -((4000 & A ^ (t | A) / (t | 99) | 112) - A))) >> 2500) - t % (t / B)

F4 | Sweep to Crunch | (t + A % -t) % (B | 100) ^ ((t * B + B / ((t << B) % (B - A / 3000 -(11 / (t % ~((A << t + t) % 82) << B) - (A << t))) - 7)) / (t / A) | A / A)

F5 | Noisy Alarm | t % B + t | t / A | ((((106 >> 12000 + A) % (((t ^ -t) - t - 79) / t & -213 | 100) ^ A >> t * B) - t / A ^ (~(B - 133) & 181 << A) % t) << 32768 + t) - 223

F6 | Rise of the Glitch | ~((t - t << 171) % (t << t)) % t * ((t >> 167) * t - t) / 196 + 208 + (A + (B | t))

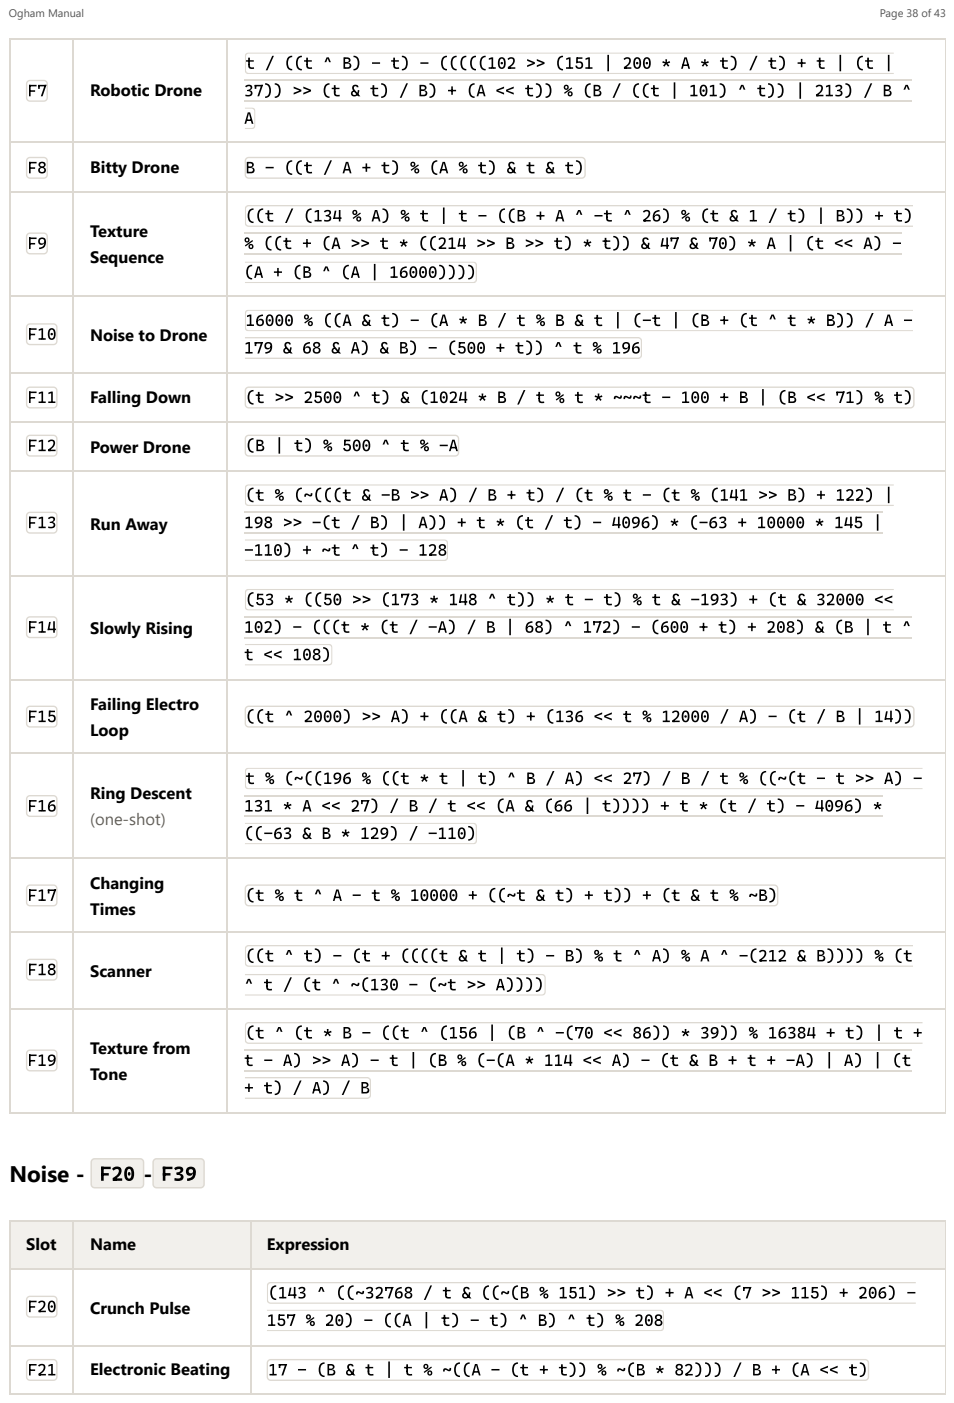
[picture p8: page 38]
Noise - F20 - F39

F7 | Robotic Drone | t / ((t ^ B) - t) - (((((102 >> (151 | 200 * A * t) / t) + t | (t | 37)) >> (t & t) / B) + (A << t)) % (B / ((t | 101) ^ t)) | 213) / B ^ A

F8 | Bitty Drone | B - ((t / A + t) % (A % t) & t & t)

F9 | Texture Sequence | ((t / (134 % A) % t | t - ((B + A ^ -t ^ 26) % (t & 1 / t) | B)) + t) % ((t + (A >> t * ((214 >> B >> t) * t)) & 47 & 70) * A | (t << A) -(A + (B ^ (A | 16000))))

F10 | Noise to Drone | 16000 % ((A & t) - (A * B / t % B & t | (-t | (B + (t ^ t * B)) / A -179 & 68 & A) & B) - (500 + t)) ^ t % 196

F11 | Falling Down | (t >> 2500 ^ t) & (1024 * B / t % t * ~~~t - 100 + B | (B << 71) % t)

F12 | Power Drone | (B | t) % 500 ^ t % -A

F13 | Run Away | (t % (~(((t & -B >> A) / B + t) / (t % t - (t % (141 >> B) + 122) | 198 >> -(t / B) | A)) + t * (t / t) - 4096) * (-63 + 10000 * 145 | -110) + ~t ^ t) - 128

F14 | Slowly Rising | (53 * ((50 >> (173 * 148 ^ t)) * t - t) % t & -193) + (t & 32000 << 102) - (((t * (t / -A) / B | 68) ^ 172) - (600 + t) + 208) & (B | t ^ t << 108)

F15 | Failing Electro Loop | ((t ^ 2000) >> A) + ((A & t) + (136 << t % 12000 / A) - (t / B | 14))

F16 | Ring Descent (one-shot) | t % (~((196 % ((t * t | t) ^ B / A) << 27) / B / t % ((~(t - t >> A) -131 * A << 27) / B / t << (A & (66 | t)))) + t * (t / t) - 4096) * ((-63 & B * 129) / -110)

F17 | Changing Times | (t % t ^ A - t % 10000 + ((~t & t) + t)) + (t & t % ~B)

F18 | Scanner | ((t ^ t) - (t + ((((t & t | t) - B) % t ^ A) % A ^ -(212 & B)))) % (t ^ t / (t ^ ~(130 - (~t >> A))))

F19 | Texture from Tone | (t ^ (t * B - ((t ^ (156 | (B ^ -(70 << 86)) * 39)) % 16384 + t) | t + t - A) >> A) - t | (B % (-(A * 114 << A) - (t & B + t + -A) | A) | (t + t) / A) / B

Slot | Name | Expression

F20 | Crunch Pulse | (143 ^ ((~32768 / t & ((~(B % 151) >> t) + A << (7 >> 115) + 206) -157 % 20) - ((A | t) - t) ^ B) ^ t) % 208

F21 | Electronic Beating | 17 - (B & t | t % ~((A - (t + t)) % ~(B * 82))) / B + (A << t)

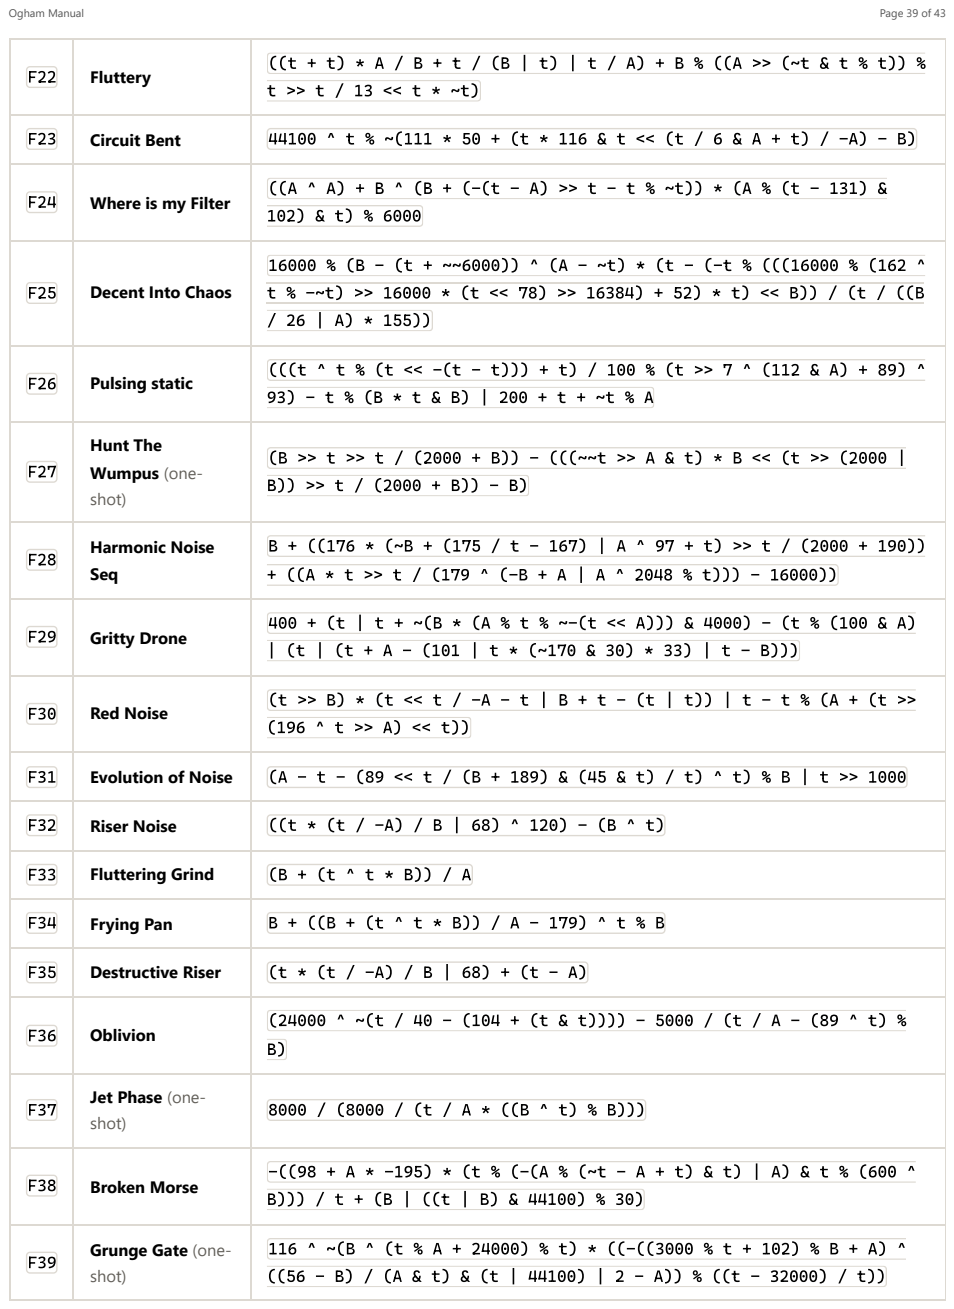
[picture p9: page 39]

F22 | Fluttery | ((t + t) * A / B + t / (B | t) | t / A) + B % ((A >> (~t & t % t)) % t >> t / 13 << t * ~t)

F23 | Circuit Bent | 44100 ^ t % ~(111 * 50 + (t * 116 & t << (t / 6 & A + t) / -A) - B)

F24 | Where is my Filter | ((A ^ A) + B ^ (B + (-(t - A) >> t - t % ~t)) * (A % (t - 131) & 102) & t) % 6000

F25 | Decent Into Chaos | 16000 % (B - (t + ~~6000)) ^ (A - ~t) * (t - (-t % (((16000 % (162 ^ t % -~t) >> 16000 * (t << 78) >> 16384) + 52) * t) << B)) / (t / ((B / 26 | A) * 155))

F26 | Pulsing static | (((t ^ t % (t << -(t - t))) + t) / 100 % (t >> 7 ^ (112 & A) + 89) ^ 93) - t % (B * t & B) | 200 + t + ~t % A

F27 | Hunt The Wumpus (one-shot) | (B >> t >> t / (2000 + B)) - (((~~t >> A & t) * B << (t >> (2000 | B)) >> t / (2000 + B)) - B)

F28 | Harmonic Noise Seq | B + ((176 * (~B + (175 / t - 167) | A ^ 97 + t) >> t / (2000 + 190)) + ((A * t >> t / (179 ^ (-B + A | A ^ 2048 % t))) - 16000))

F29 | Gritty Drone | 400 + (t | t + ~(B * (A % t % ~-(t << A))) & 4000) - (t % (100 & A) | (t | (t + A - (101 | t * (~170 & 30) * 33) | t - B)))

F30 | Red Noise | (t >> B) * (t << t / -A - t | B + t - (t | t)) | t - t % (A + (t >> (196 ^ t >> A) << t))

F31 | Evolution of Noise | (A - t - (89 << t / (B + 189) & (45 & t) / t) ^ t) % B | t >> 1000

F32 | Riser Noise | ((t * (t / -A) / B | 68) ^ 120) - (B ^ t)

F33 | Fluttering Grind | (B + (t ^ t * B)) / A

F34 | Frying Pan | B + ((B + (t ^ t * B)) / A - 179) ^ t % B

F35 | Destructive Riser | (t * (t / -A) / B | 68) + (t - A)

F36 | Oblivion | (24000 ^ ~(t / 40 - (104 + (t & t)))) - 5000 / (t / A - (89 ^ t) % B)

F37 | Jet Phase (one-shot) | 8000 / (8000 / (t / A * ((B ^ t) % B)))

F38 | Broken Morse | -((98 + A * -195) * (t % (-(A % (~t - A + t) & t) | A) & t % (600 ^ B))) / t + (B | ((t | B) & 44100) % 30)

F39 | Grunge Gate (one-shot) | 116 ^ ~(B ^ (t % A + 24000) % t) * ((-((3000 % t + 102) % B + A) ^ ((56 - B) / (A & t) & (t | 44100) | 2 - A)) % ((t - 32000) / t))

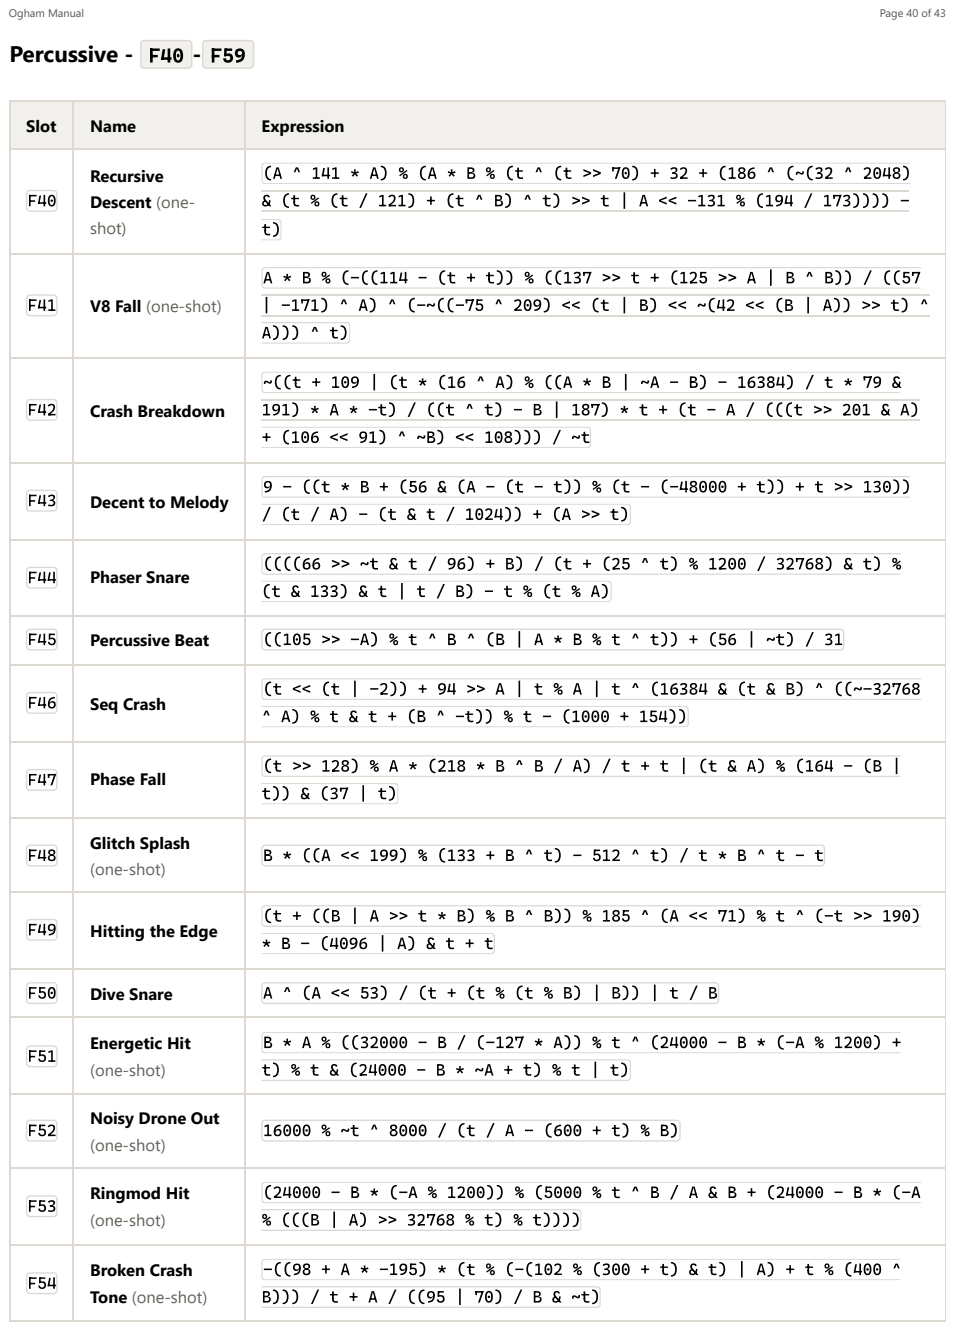
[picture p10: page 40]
Percussive - F40 - F59

Slot | Name | Expression

F40 | Recursive Descent (one-shot) | (A ^ 141 * A) % (A * B % (t ^ (t >> 70) + 32 + (186 ^ (~(32 ^ 2048) & (t % (t / 121) + (t ^ B) ^ t) >> t | A << -131 % (194 / 173)))) -t)

F41 | V8 Fall (one-shot) | A * B % (-((114 - (t + t)) % ((137 >> t + (125 >> A | B ^ B)) / ((57 | -171) ^ A) ^ (-~((-75 ^ 209) << (t | B) << ~(42 << (B | A)) >> t) ^ A))) ^ t)

F42 | Crash Breakdown | ~((t + 109 | (t * (16 ^ A) % ((A * B | ~A - B) - 16384) / t * 79 & 191) * A * -t) / ((t ^ t) - B | 187) * t + (t - A / (((t >> 201 & A) + (106 << 91) ^ ~B) << 108))) / ~t

F43 | Decent to Melody | 9 - ((t * B + (56 & (A - (t - t)) % (t - (-48000 + t)) + t >> 130)) / (t / A) - (t & t / 1024)) + (A >> t)

F44 | Phaser Snare | ((((66 >> ~t & t / 96) + B) / (t + (25 ^ t) % 1200 / 32768) & t) % (t & 133) & t | t / B) - t % (t % A)

F45 | Percussive Beat | ((105 >> -A) % t ^ B ^ (B | A * B % t ^ t)) + (56 | ~t) / 31

F46 | Seq Crash | (t << (t | -2)) + 94 >> A | t % A | t ^ (16384 & (t & B) ^ ((~-32768 ^ A) % t & t + (B ^ -t)) % t - (1000 + 154))

F47 | Phase Fall | (t >> 128) % A * (218 * B ^ B / A) / t + t | (t & A) % (164 - (B | t)) & (37 | t)

F48 | Glitch Splash (one-shot) | B * ((A << 199) % (133 + B ^ t) - 512 ^ t) / t * B ^ t - t

F49 | Hitting the Edge | (t + ((B | A >> t * B) % B ^ B)) % 185 ^ (A << 71) % t ^ (-t >> 190) * B - (4096 | A) & t + t

F50 | Dive Snare | A ^ (A << 53) / (t + (t % (t % B) | B)) | t / B

F51 | Energetic Hit (one-shot) | B * A % ((32000 - B / (-127 * A)) % t ^ (24000 - B * (-A % 1200) + t) % t & (24000 - B * ~A + t) % t | t)

F52 | Noisy Drone Out (one-shot) | 16000 % ~t ^ 8000 / (t / A - (600 + t) % B)

F53 | Ringmod Hit (one-shot) | (24000 - B * (-A % 1200)) % (5000 % t ^ B / A & B + (24000 - B * (-A % (((B | A) >> 32768 % t) % t))))

F54 | Broken Crash Tone (one-shot) | -((98 + A * -195) * (t % (-(102 % (300 + t) & t) | A) + t % (400 ^ B))) / t + A / ((95 | 70) / B & ~t)

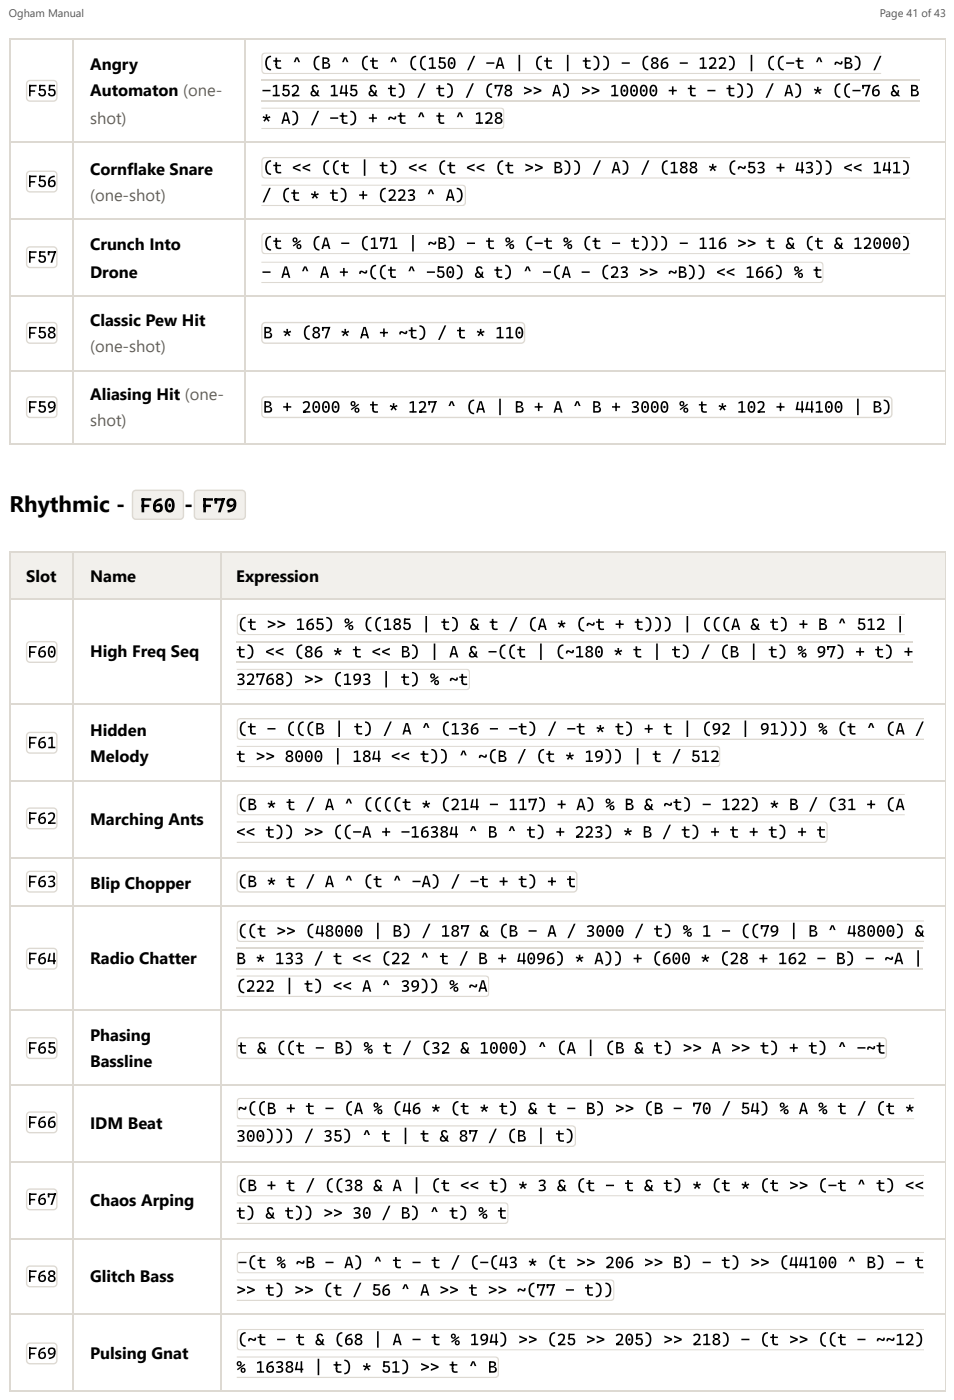
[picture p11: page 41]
Rhythmic - F60 - F79

F55 | Angry Automaton (one-shot) | (t ^ (B ^ (t ^ ((150 / -A | (t | t)) - (86 - 122) | ((-t ^ ~B) / -152 & 145 & t) / t) / (78 >> A) >> 10000 + t - t)) / A) * ((-76 & B * A) / -t) + ~t ^ t ^ 128

F56 | Cornflake Snare (one-shot) | (t << ((t | t) << (t << (t >> B)) / A) / (188 * (~53 + 43)) << 141) / (t * t) + (223 ^ A)

F57 | Crunch Into Drone | (t % (A - (171 | ~B) - t % (-t % (t - t))) - 116 >> t & (t & 12000) - A ^ A + ~((t ^ -50) & t) ^ -(A - (23 >> ~B)) << 166) % t

F58 | Classic Pew Hit (one-shot) | B * (87 * A + ~t) / t * 110

F59 | Aliasing Hit (one-shot) | B + 2000 % t * 127 ^ (A | B + A ^ B + 3000 % t * 102 + 44100 | B)

Slot | Name | Expression

F60 | High Freq Seq | (t >> 165) % ((185 | t) & t / (A * (~t + t))) | (((A & t) + B ^ 512 | t) << (86 * t << B) | A & -((t | (~180 * t | t) / (B | t) % 97) + t) + 32768) >> (193 | t) % ~t

F61 | Hidden Melody | (t - (((B | t) / A ^ (136 - -t) / -t * t) + t | (92 | 91))) % (t ^ (A / t >> 8000 | 184 << t)) ^ ~(B / (t * 19)) | t / 512

F62 | Marching Ants | (B * t / A ^ ((((t * (214 - 117) + A) % B & ~t) - 122) * B / (31 + (A << t)) >> ((-A + -16384 ^ B ^ t) + 223) * B / t) + t + t) + t

F63 | Blip Chopper | (B * t / A ^ (t ^ -A) / -t + t) + t

F64 | Radio Chatter | ((t >> (48000 | B) / 187 & (B - A / 3000 / t) % 1 - ((79 | B ^ 48000) & B * 133 / t << (22 ^ t / B + 4096) * A)) + (600 * (28 + 162 - B) - ~A | (222 | t) << A ^ 39)) % ~A

F65 | Phasing Bassline | t & ((t - B) % t / (32 & 1000) ^ (A | (B & t) >> A >> t) + t) ^ -~t

F66 | IDM Beat | ~((B + t - (A % (46 * (t * t) & t - B) >> (B - 70 / 54) % A % t / (t * 300))) / 35) ^ t | t & 87 / (B | t)

F67 | Chaos Arping | (B + t / ((38 & A | (t << t) * 3 & (t - t & t) * (t * (t >> (-t ^ t) << t) & t)) >> 30 / B) ^ t) % t

F68 | Glitch Bass | -(t % ~B - A) ^ t - t / (-(43 * (t >> 206 >> B) - t) >> (44100 ^ B) - t >> t) >> (t / 56 ^ A >> t >> ~(77 - t))

F69 | Pulsing Gnat | (~t - t & (68 | A - t % 194) >> (25 >> 205) >> 218) - (t >> ((t - ~~12) % 16384 | t) * 51) >> t ^ B

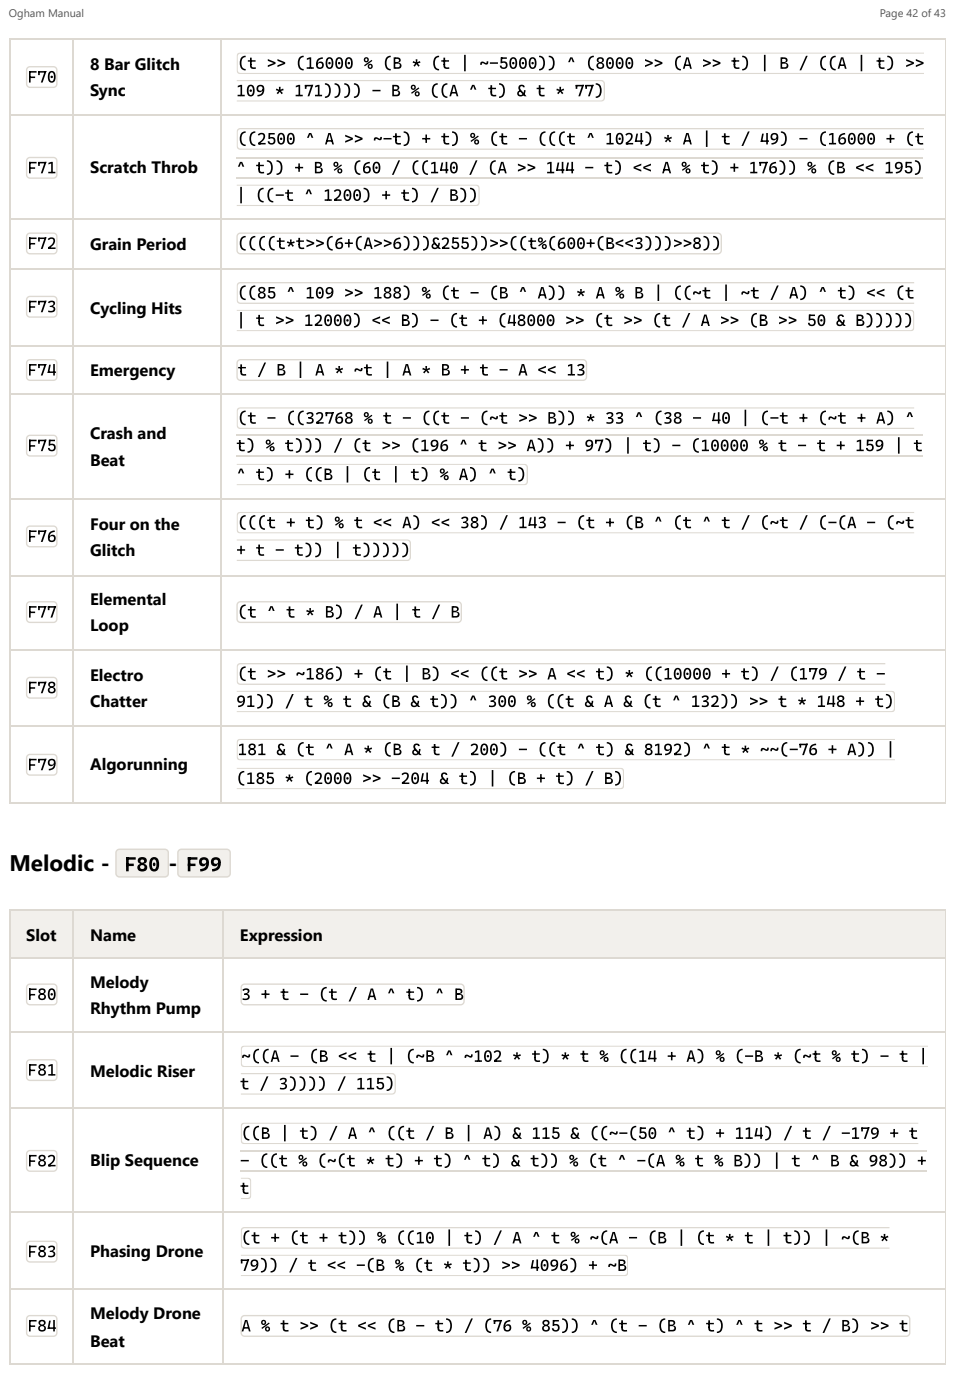
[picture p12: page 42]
Melodic - F80 - F99

F70 | 8 Bar Glitch Sync | (t >> (16000 % (B * (t | ~-5000)) ^ (8000 >> (A >> t) | B / ((A | t) >> 109 * 171)))) - B % ((A ^ t) & t * 77)

F71 | Scratch Throb | ((2500 ^ A >> ~-t) + t) % (t - (((t ^ 1024) * A | t / 49) - (16000 + (t ^ t)) + B % (60 / ((140 / (A >> 144 - t) << A % t) + 176)) % (B << 195) | ((-t ^ 1200) + t) / B))

F72 | Grain Period | ((((t*t>>(6+(A>>6)))&255))>>((t%(600+(B<<3)))>>8))

F73 | Cycling Hits | ((85 ^ 109 >> 188) % (t - (B ^ A)) * A % B | ((~t | ~t / A) ^ t) << (t | t >> 12000) << B) - (t + (48000 >> (t >> (t / A >> (B >> 50 & B)))))

F74 | Emergency | t / B | A * ~t | A * B + t - A << 13

F75 | Crash and Beat | (t - ((32768 % t - ((t - (~t >> B)) * 33 ^ (38 - 40 | (-t + (~t + A) ^ t) % t))) / (t >> (196 ^ t >> A)) + 97) | t) - (10000 % t - t + 159 | t ^ t) + ((B | (t | t) % A) ^ t)

F76 | Four on the Glitch | (((t + t) % t << A) << 38) / 143 - (t + (B ^ (t ^ t / (~t / (-(A - (~t + t - t)) | t)))))

F77 | Elemental Loop | (t ^ t * B) / A | t / B

F78 | Electro Chatter | (t >> ~186) + (t | B) << ((t >> A << t) * ((10000 + t) / (179 / t -91)) / t % t & (B & t)) ^ 300 % ((t & A & (t ^ 132)) >> t * 148 + t)

F79 | Algorunning | 181 & (t ^ A * (B & t / 200) - ((t ^ t) & 8192) ^ t * ~~(-76 + A)) | (185 * (2000 >> -204 & t) | (B + t) / B)

Slot | Name | Expression

F80 | Melody Rhythm Pump | 3 + t - (t / A ^ t) ^ B

F81 | Melodic Riser | ~((A - (B << t | (~B ^ ~102 * t) * t % ((14 + A) % (-B * (~t % t) - t | t / 3)))) / 115)

F82 | Blip Sequence | ((B | t) / A ^ ((t / B | A) & 115 & ((~-(50 ^ t) + 114) / t / -179 + t - ((t % (~(t * t) + t) ^ t) & t)) % (t ^ -(A % t % B)) | t ^ B & 98)) + t

F83 | Phasing Drone | (t + (t + t)) % ((10 | t) / A ^ t % ~(A - (B | (t * t | t)) | ~(B * 79)) / t << -(B % (t * t)) >> 4096) + ~B

F84 | Melody Drone Beat | A % t >> (t << (B - t) / (76 % 85)) ^ (t - (B ^ t) ^ t >> t / B) >> t

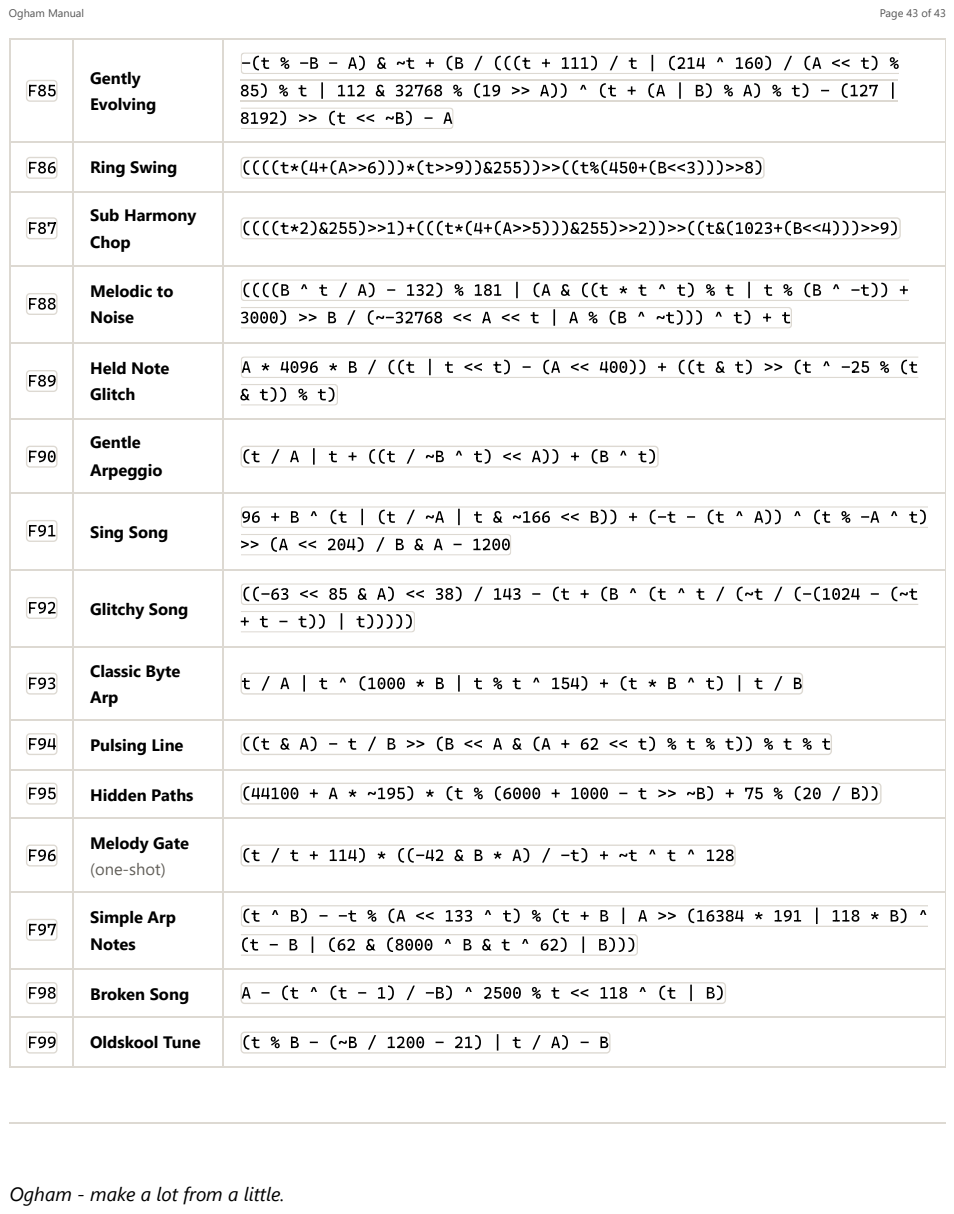
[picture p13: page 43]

F85 | Gently Evolving | -(t % -B - A) & ~t + (B / (((t + 111) / t | (214 ^ 160) / (A << t) % 85) % t | 112 & 32768 % (19 >> A)) ^ (t + (A | B) % A) % t) - (127 | 8192) >> (t << ~B) - A

F86 | Ring Swing | ((((t*(4+(A>>6)))*(t>>9))&255))>>((t%(450+(B<<3)))>>8)

F87 | Sub Harmony Chop | ((((t*2)&255)>>1)+(((t*(4+(A>>5)))&255)>>2))>>((t&(1023+(B<<4)))>>9)

F88 | Melodic to Noise | ((((B ^ t / A) - 132) % 181 | (A & ((t * t ^ t) % t | t % (B ^ -t)) + 3000) >> B / (~-32768 << A << t | A % (B ^ ~t))) ^ t) + t

F89 | Held Note Glitch | A * 4096 * B / ((t | t << t) - (A << 400)) + ((t & t) >> (t ^ -25 % (t & t)) % t)

F90 | Gentle Arpeggio | (t / A | t + ((t / ~B ^ t) << A)) + (B ^ t)

F91 | Sing Song | 96 + B ^ (t | (t / ~A | t & ~166 << B)) + (-t - (t ^ A)) ^ (t % -A ^ t) >> (A << 204) / B & A - 1200

F92 | Glitchy Song | ((-63 << 85 & A) << 38) / 143 - (t + (B ^ (t ^ t / (~t / (-(1024 - (~t + t - t)) | t)))))

F93 | Classic Byte Arp | t / A | t ^ (1000 * B | t % t ^ 154) + (t * B ^ t) | t / B

F94 | Pulsing Line | ((t & A) - t / B >> (B << A & (A + 62 << t) % t % t)) % t % t

F95 | Hidden Paths | (44100 + A * ~195) * (t % (6000 + 1000 - t >> ~B) + 75 % (20 / B))

F96 | Melody Gate (one-shot) | (t / t + 114) * ((-42 & B * A) / -t) + ~t ^ t ^ 128

F97 | Simple Arp Notes | (t ^ B) - -t % (A << 133 ^ t) % (t + B | A >> (16384 * 191 | 118 * B) ^ (t - B | (62 & (8000 ^ B & t ^ 62) | B)))

F98 | Broken Song | A - (t ^ (t - 1) / -B) ^ 2500 % t << 118 ^ (t | B)

F99 | Oldskool Tune | (t % B - (~B / 1200 - 21) | t / A) - B

Ogham - make a lot from a little.

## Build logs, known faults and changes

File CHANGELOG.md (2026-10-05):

# Changelog

Firmware releases. Each version is tagged here, with its binary attached to the
corresponding GitHub Release and the SHA-256 published. Releases up to 1.17
carried two encoder builds; from 1.18 there is one.

Full release notes, and the in-browser flasher, live at
<https://keeos.io/firmware/ogham/>.

## 1.19 - 2026-10-05

The display can dim itself, or turn itself off when you're not touching the
module.

- **New Menu field 22, `br.NN`.** The last digit is the display brightness, 0-7
  (the TM1637's eight levels). A first digit of 1 adds auto-off: the display
  goes dark one second after the last encoder or knob movement and lights on the
  next one, so `br.00`-`br.07` stay on and `br.10`-`br.17` auto-off. One detent
  goes from 07 to 10. Default `br.14`: brightness 4 as before, plus auto-off.
- **Why.** On the v1.0 board the display's multiplexed LED current is audible
  on the outputs as a faint buzz that grows with brightness. It is not the
  CLK/DIO bus: a build that stopped writing to the display entirely left it
  unchanged. Auto-off removes it hands-off; the hardware fix (a series resistor
  and bulk capacitor at the display connector) is for the next board revision.
- **What wakes it.** The encoder and the four knobs. The Mode switch, CV, gates
  and clock never do, so a patched module you aren't touching stays dark. It
  never sleeps in the Menu or while a value flash is showing.
- **Settings survive.** The new setting lives in the byte that was `reserved0`,
  stored as the menu value + 1, so every existing patch reads as the default
  and `SETTINGS_VERSION` stays 16. Invalid values, left by a field that was
  withdrawn in development, reset to the default at boot.
- 128,952 B (98.38%), 2,120 B spare.

## 1.17 — 2026-08-30

A correctness fix that changes nothing on the module. The image is byte-identical
to 1.16; it is here because the same source now also runs in the VCV Rack port,
where the difference is real.

- **`BpmClock` initialises its own members.** The class follows the usual
  `Init()`-rather-than-constructor convention, and `Init()` leaves four working
  arrays alone — `fftBuffer_`, `fluxLin_`, `corr_` and `bpmHist_` — because they
  are written before they are read in normal operation. On the module that is
  free: the instance is a file-scope static, so the loader zeroes it. In Rack it
  is a member of a heap-allocated object, where those arrays start as whatever
  was in that memory, and `bpmHist_` is the estimator's agreement history — so a
  fresh instance could lock to a tempo derived from nothing, differently each
  time. Every member now carries a default initialiser, which makes the class
  correct wherever it is constructed rather than correct-if-the-caller-remembers.
- **Nothing changed on the module.** The initialisers are all constant
  expressions, so the static instance is still constant-initialised into `.bss`.
  The compiled binary is byte-for-byte identical to 1.16 — same text, data and
  bss, same MD5 — so there is no reason to reflash for this.
- Settings are untouched — the stored layout is unchanged.

## 1.16 — 2026-08-18

Housekeeping ahead of the sources being published: the unreachable placeholder
formula is gone.

- **The out-of-range fallback is removed.** Every numbered slot has held a real
  formula since 1.11, and both voices clamp their index before the lookup, so
  the placeholder could not be reached from the panel or by any tool. An
  out-of-range index now returns slot 0. Nothing sounds different; 48 bytes of
  flash recovered, leaving the build at 127,712 B (97.44%).
- Settings are untouched — the stored layout is unchanged.

## 1.15 — 2026-08-18

The A and B knobs get their top fifth back, one-shot formulas fire when you
select them, and a menu field added the day before is withdrawn.

- **A and B stopped climbing at 2 o'clock.** Both knobs reached 255 at about 80%
  of travel, on every module, and the last fifth of the rotation did nothing.
  The pot and its CV were summed in hardware into a single ADC, and that sum sits
  on the 0 V rail before the pot finishes its sweep — by the time the firmware
  saw it, the information was gone. The pot is now read from its own ADC and the
  CV recovered as the sum's departure from the fitted line: 255 arrives at 100%
  of travel on both channels. Bipolar CV behaviour is unchanged, measured
  symmetric at +83/−82 counts about the pot's position. Channel A had also
  carried a ~1% scale error against B since the original port.
- **Selecting a one-shot fires it.** Roughly a fifth of the bank is percussive
  one-shots that make their sound within the first few thousand ticks and are
  silent ever after, so landing on one after a few minutes of playing gave
  nothing at all — at every A and B, with no indication why. Changing either
  voice's formula now restarts the waveform. A decoupled Out 2 drone is not
  affected.
- **The V/oct start offset (`P`) field is withdrawn**, added and removed the same
  day. Skipping a formula's silent opening is better described in the manual than
  dialled in from a menu, so the Sync chapter gains a section on formulas that
  start silent — the first remedy being to turn Rate up. Settings are *not*
  reset: the persisted byte was kept as a reserved field, so the stored layout
  and `SETTINGS_VERSION` 16 are unchanged.
- **Appendix A marks the one-shots.** Every formula in the manual now says
  whether it plays continuously, one-shots, or one-shots only at some A/B
  settings, classified by measurement across the whole bank rather than by ear.
- Flash: 127,760 B, 97.47% of the 128 KB region.

## 1.14 — 2026-08-11

Pitch, tempo and the low-pass gate all change here.

> **This update resets your settings.** The stored layout changed, so every
> module returns to factory defaults on first boot: both voices to `F0`, and the
> whole menu — FX chain, LPG, CV Out — back to defaults.

- **V/oct transposes instead of hard-syncing.** It previously reset the formula
  every cycle to force a pitch, which gave a clean note but discarded most of
  what the formula was doing, and silenced plenty of formulas outright. It now
  scales the playback rate exponentially, so every partial moves together —
  varispeed transposition rather than a per-cycle reset. The Rate knob becomes a
  quantized octave placement, ÷32 to ×32, which is what puts a formula into a
  register you can play.
- **Clock In assumes one pulse per beat**, not per sixteenth — what most gear
  actually sends. At the same knob position a patched clock now plays about four
  times slower and sits much closer to native speed. The dropout timeouts moved
  from 2 s to 10 s with it: a 4/4 bar at 120 BPM is exactly 2 s, so a slow clock
  had been reading as a stopped one.
- **The LPG decay knee moves to 40 = 500 ms** (it was 50 = 10 s). The bottom
  third of the dial had crammed a 166× range into 30 numbers while the top half
  spent 49 values on a 2× range nobody could hear. A stored patch keeps its
  number but sounds different.
- **A and B recover their odd numbers** — a resolution loss in the parameter
  path, separate from the range problem fixed in 1.15.

## 1.13 — 2026-08-10

The encoder stops missing clicks, and effects you are not using stop costing you
CPU. Settings are not reset.

- **The encoder no longer drops small movements.** Its scan ran on the
  lowest-priority timer interrupt in the system, below the audio callback: at
  light load that cost nothing, but under a full FX chain the effective scan rate
  collapsed by nearly half, and a brisk turn crossed two positions between looks
  — at which point the movement was discarded rather than delayed. The scan
  interrupt now outranks the audio DMA. Measured on the same gesture: 21 detents
  decoded under load, against 6 before.
- **A stage at Level 0 is skipped, not just mixed out.** All three FX stages were
  evaluated and then discarded, so a one-effect patch paid for the whole chain. A
  typical one-effect patch now runs at about 20% CPU. Stage phasors keep running
  while skipped, so a sweep does not jump when its level comes back up.
- v1.12 was a bench build flashed to one module during the encoder
  investigation, and is folded into this release.

## 1.11 — 2026-08-10

The full bank: all 100 slots are now real formulas, grouped by character.

- **The bank is complete and reorganised.** `F0`–`F99` are a hundred curated
  formulas — twenty each of **textural** (`F0`–`F19`), **noise** (`F20`–`F39`),
  **percussive** (`F40`–`F59`), **rhythmic** (`F60`–`F79`) and **melodic**
  (`F80`–`F99`). The placeholder no longer plays on any numbered slot.
- **Every slot number now means something different.** The previous 22-formula
  bank is entirely replaced, so a saved patch (or a written-down slot number)
  selects a different sound than it did on 1.10. Settings themselves are not
  touched — the layout is unchanged, so updating does **not** reset them — but
  the two saved formula indices will need re-choosing by ear.
- The formulas are generated from the curated library rather than hand-written,
  and each one is verified against the evaluator they were auditioned on before
  it ships: 72 million samples per build, across nine A/B settings and four
  windows of `t`, all matching sample for sample.
- Manual: Appendix A rewritten as the hundred-formula bank, grouped by type,
  listing each slot's number, name and expression.

## 1.10 — 2026-08-08

Maintenance release: no new user-facing features, no settings-layout change
(updating from 1.09 does **not** reset your saved settings).

- Firmware source clean-up — removed several accessors and one code path left
  behind by earlier, since-superseded designs (an unused Out 2 "delay"
  mechanism, an unused engine freeze, unused polled gate/clock edge
  detection, among others). No behaviour change.
- Manual: new Troubleshooting section — the internal LPG being left on with
  nothing patched to Sync produces total silence on both outputs by design,
  not a fault; that's now written down instead of only discoverable by
  re-deriving it live.

## 1.09 — 2026-07-30

First release published from this repository.

- **Internal LPG.** A low-pass gate on the output, off by default, plucked by the
  **Sync** input. One envelope drives a VCA *and* a low-pass filter together, so
  quiet is also dark — the module can play discrete percussive notes from a
  trigger instead of only running continuously. Decay 2 ms – 20 s.
- **Menu navigation.** The field list no longer wraps, it remembers where you
  were, and it accelerates with turn speed.
- **Encoder scanning moved to a dedicated 10 kHz timer.** 1.03 fixed steps being
  lost during display writes; this fixes the remainder, where a fast crank
  outran the 1 kHz scan.

> **Updating from 1.03 or earlier resets the module to factory defaults** — the
> stored-settings layout changed. Both voices return to `F0` and the menu to its
> defaults, once, on the first boot after flashing.

## 1.03 — 2026-07-28

- Firmware version shown for ~1 s at boot, and recorded in stored settings.
- Encoder decoding moved into the audio interrupt, so detents are no longer
  dropped while the display is being written.
- Pot ranges recalibrated across the built units; the Tone control's clockwise
  sweep spread out so the crush and resonance region is easier to land on.
- Two encoder builds introduced, for the two A/B phasings in circulation.

## 1.00

Initial release. Predates the boot version display — if the startup animation
runs straight into the function display with no version, that is what the module
is running.

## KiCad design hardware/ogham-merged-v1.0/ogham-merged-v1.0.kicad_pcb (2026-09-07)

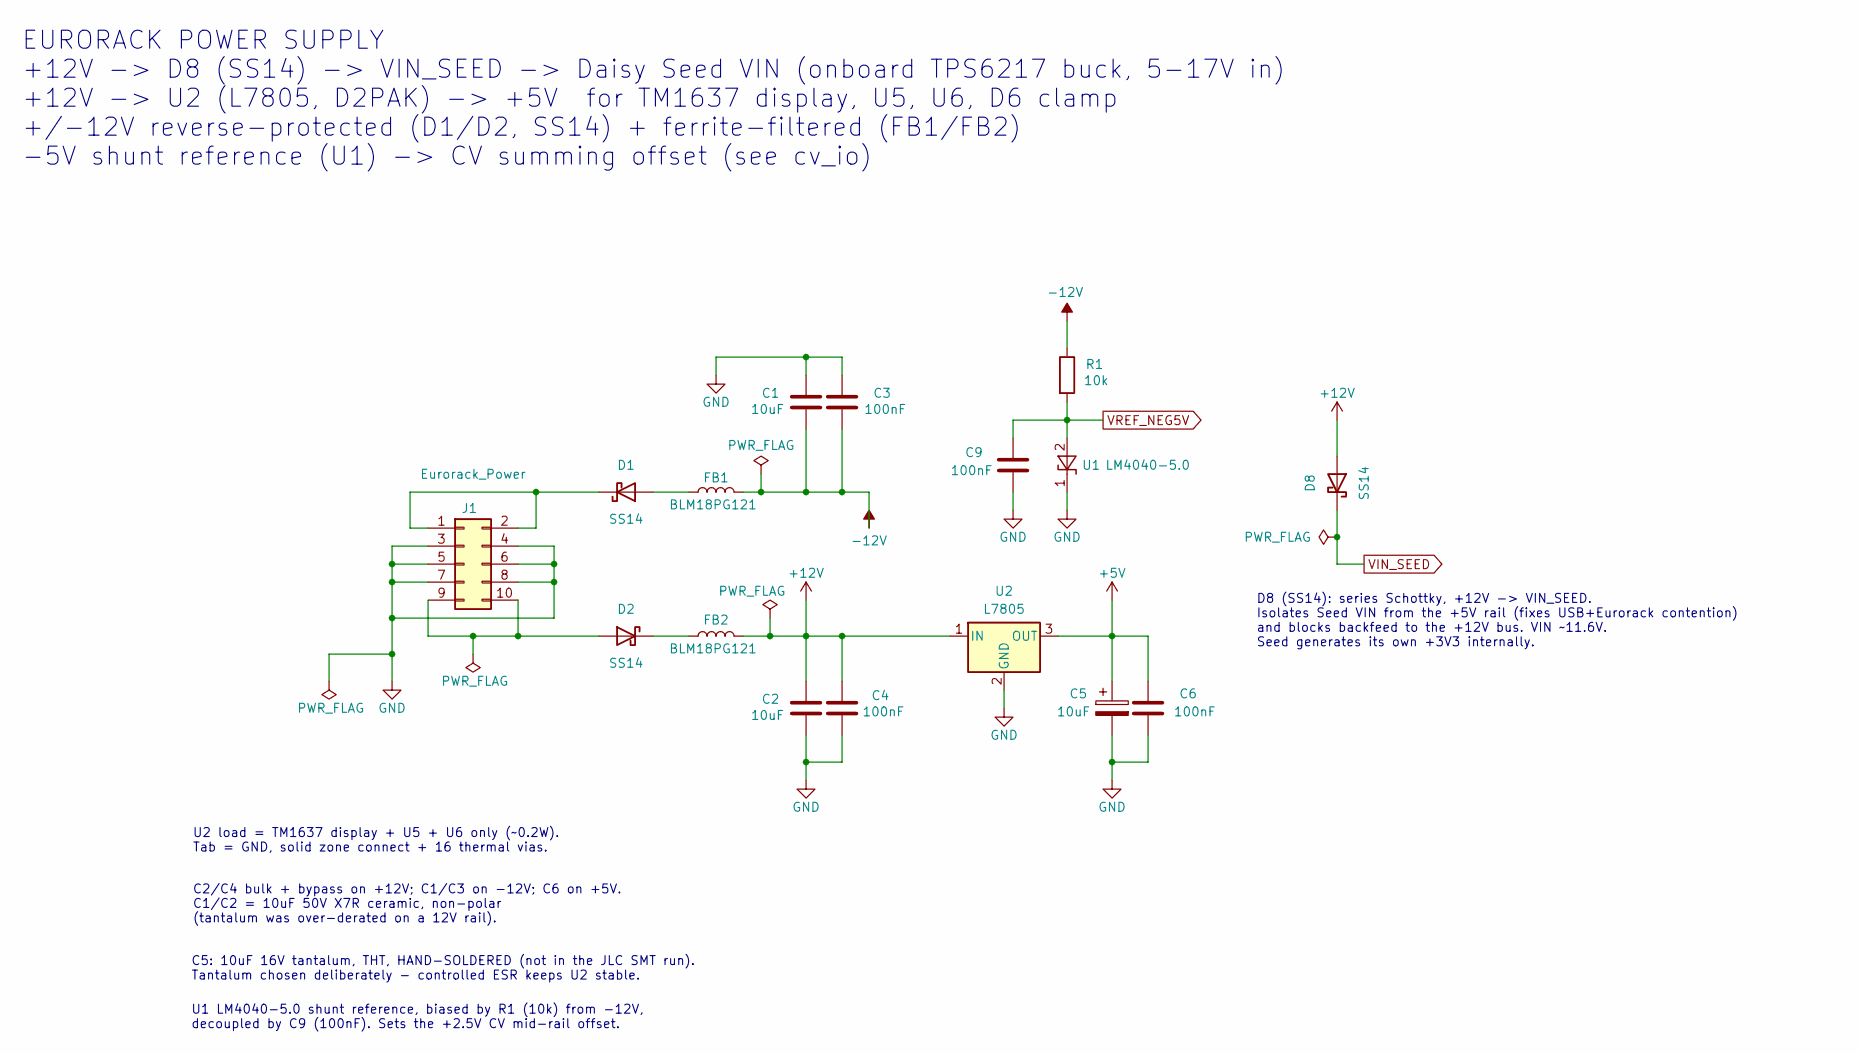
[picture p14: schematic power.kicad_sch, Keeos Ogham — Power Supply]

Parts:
C1, C2: 10uF; C_1210_3225Metric; LCSC C138687
C3, C4, C6, C9: 100nF; C_0603_1608Metric; LCSC C14663
C5: 10uF; CP_Radial_D5.0mm_P2.50mm; LCSC TAP106J016SCS
D1, D2, D8: SS14; D_SMA; LCSC C2480
FB1, FB2: BLM18PG121; L_0603_1608Metric; LCSC C14709
J1: Eurorack_Power; PinHeader_2x05_P2.54mm_Vertical
R1: 10k; R_0603_1608Metric; LCSC C25804
U1: LM4040-5.0; SOT-23; LCSC C156302
U2: L7805; TO-263-2; LCSC C15077

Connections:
+5V: C5.1, C6.1, U2.3 (OUT); also elsewhere on the board
+12V: C2.1, C4.1, D8.2 (A), FB2.2, U2.1 (IN); also elsewhere on the board
-12V: C1.2, C3.2, FB1.2, R1.1; also elsewhere on the board
GND: C1.1, C2.2, C3.1, C4.2, C5.2, C6.2, C9.2, J1.3, J1.4, J1.5, J1.6, J1.7, J1.8, U1.1 (K), U2.2 (GND); also elsewhere on the board
unnamed: D1.2 (A), FB1.1
unnamed: D1.1 (K), J1.1, J1.2
unnamed: D2.2 (A), J1.9, J1.10
unnamed: D2.1 (K), FB2.1
VIN_SEED: D8.1 (K); also elsewhere on the board
VREF_NEG5V: C9.1, R1.2, U1.2 (A); also elsewhere on the board

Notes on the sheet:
U1 LM4040-5.0 shunt reference, biased by R1 (10k) from -12V, decoupled by C9 (100nF). Sets the +2.5V CV mid-rail offset.
EURORACK POWER SUPPLY +12V -> D8 (SS14) -> VIN_SEED -> Daisy Seed VIN (onboard TPS6217 buck, 5-17V in) +12V -> U2 (L7805, D2PAK) -> +5V for TM1637 display, U5, U6, D6 clamp +/-12V reverse-protected (D1/D2, SS14) + ferrite-filtered (FB1/FB2) -5V shunt reference (U1) -> CV summing offset (see cv_io)
D8 (SS14): series Schottky, +12V -> VIN_SEED. Isolates Seed VIN from the +5V rail (fixes USB+Eurorack contention) and blocks backfeed to the +12V bus. VIN ~11.6V. Seed generates its own +3V3 internally.
C5: 10uF 16V tantalum, THT, HAND-SOLDERED (not in the JLC SMT run). Tantalum chosen deliberately - controlled ESR keeps U2 stable.
U2 load = TM1637 display + U5 + U6 only (~0.2W). Tab = GND, solid zone connect + 16 thermal vias.
C2/C4 bulk + bypass on +12V; C1/C3 on -12V; C6 on +5V. C1/C2 = 10uF 50V X7R ceramic, non-polar (tantalum was over-derated on a 12V rail).

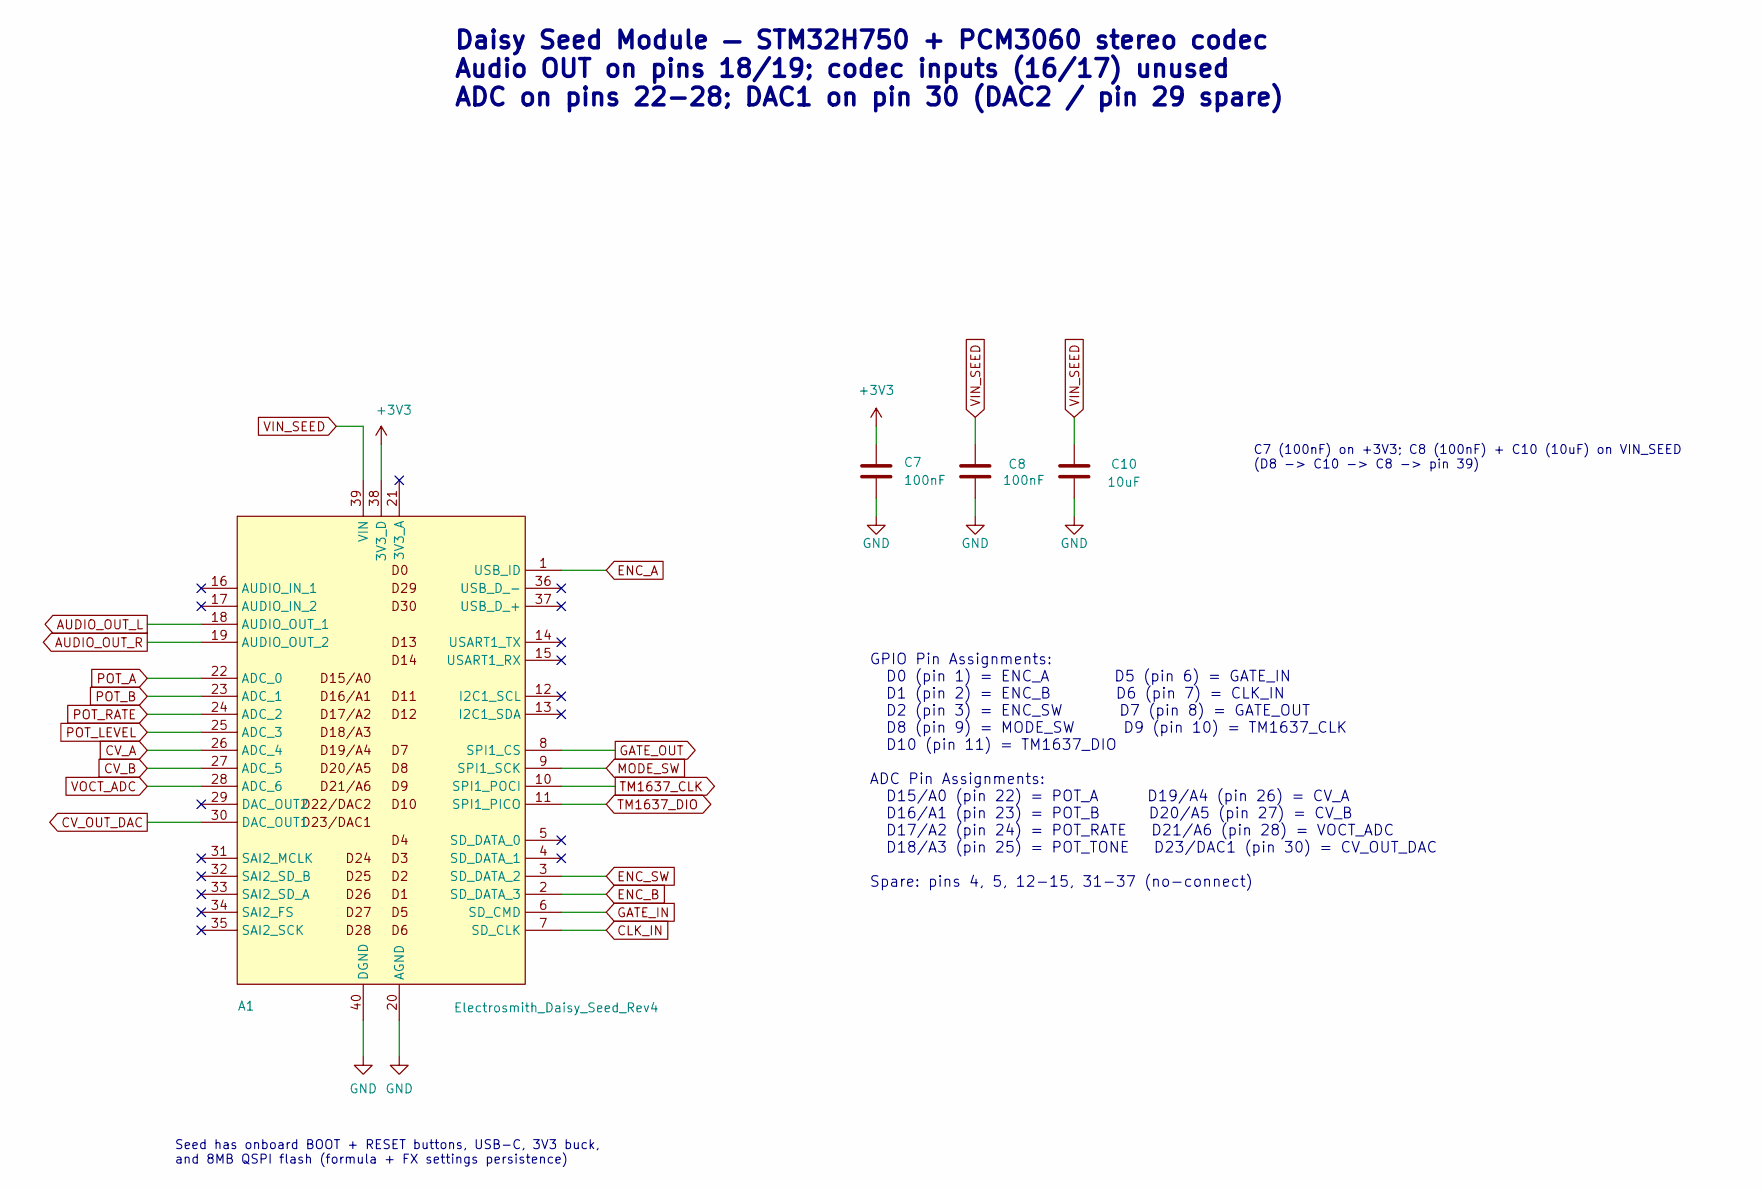
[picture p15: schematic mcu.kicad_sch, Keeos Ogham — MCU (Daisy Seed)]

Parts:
A1: Electrosmith_Daisy_Seed_Rev4; Electrosmith_Daisy_Seed
C7, C8: 100nF; C_0603_1608Metric; LCSC C14663
C10: 10uF; C_1210_3225Metric; LCSC C138687

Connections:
+3V3: A1.38 (3V3_D), C7.1; also elsewhere on the board
AUDIO_OUT_L: A1.18 (AUDIO_OUT_1); also elsewhere on the board
AUDIO_OUT_R: A1.19 (AUDIO_OUT_2); also elsewhere on the board
CLK_IN: A1.7 (SD_CLK); also elsewhere on the board
CV_A: A1.26 (ADC_4); also elsewhere on the board
CV_B: A1.27 (ADC_5); also elsewhere on the board
CV_OUT_DAC: A1.30 (DAC_OUT1); also elsewhere on the board
ENC_A: A1.1 (USB_ID); also elsewhere on the board
ENC_B: A1.2 (SD_DATA_3); also elsewhere on the board
ENC_SW: A1.3 (SD_DATA_2); also elsewhere on the board
GATE_IN: A1.6 (SD_CMD); also elsewhere on the board
GATE_OUT: A1.8 (SPI1_CS); also elsewhere on the board
GND: A1.20 (AGND), A1.40 (DGND), C7.2, C8.2, C10.2; also elsewhere on the board
MODE_SW: A1.9 (SPI1_SCK); also elsewhere on the board
POT_A: A1.22 (ADC_0); also elsewhere on the board
POT_B: A1.23 (ADC_1); also elsewhere on the board
POT_LEVEL: A1.25 (ADC_3); also elsewhere on the board
POT_RATE: A1.24 (ADC_2); also elsewhere on the board
TM1637_CLK: A1.10 (SPI1_POCI); also elsewhere on the board
TM1637_DIO: A1.11 (SPI1_PICO); also elsewhere on the board
VIN_SEED: A1.39 (VIN), C8.1, C10.1; also elsewhere on the board
VOCT_ADC: A1.28 (ADC_6); also elsewhere on the board

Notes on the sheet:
C7 (100nF) on +3V3; C8 (100nF) + C10 (10uF) on VIN_SEED (D8 -> C10 -> C8 -> pin 39)
Daisy Seed Module — STM32H750 + PCM3060 stereo codec Audio OUT on pins 18/19; codec inputs (16/17) unused ADC on pins 22-28; DAC1 on pin 30 (DAC2 / pin 29 spare)
GPIO Pin Assignments: D0 (pin 1) = ENC_A D5 (pin 6) = GATE_IN D1 (pin 2) = ENC_B D6 (pin 7) = CLK_IN D2 (pin 3) = ENC_SW D7 (pin 8) = GATE_OUT D8 (pin 9) = MODE_SW D9 (pin 10) = TM1637_CLK D10 (pin 11) = TM1637_DIO ADC Pin Assignments: D15/A0 (pin 22) = POT_A D19/A4 (pin 26) = CV_A D16/A1 (pin 23) 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
Seed has onboard BOOT + RESET buttons, USB-C, 3V3 buck, and 8MB QSPI flash (formula + FX settings persistence)

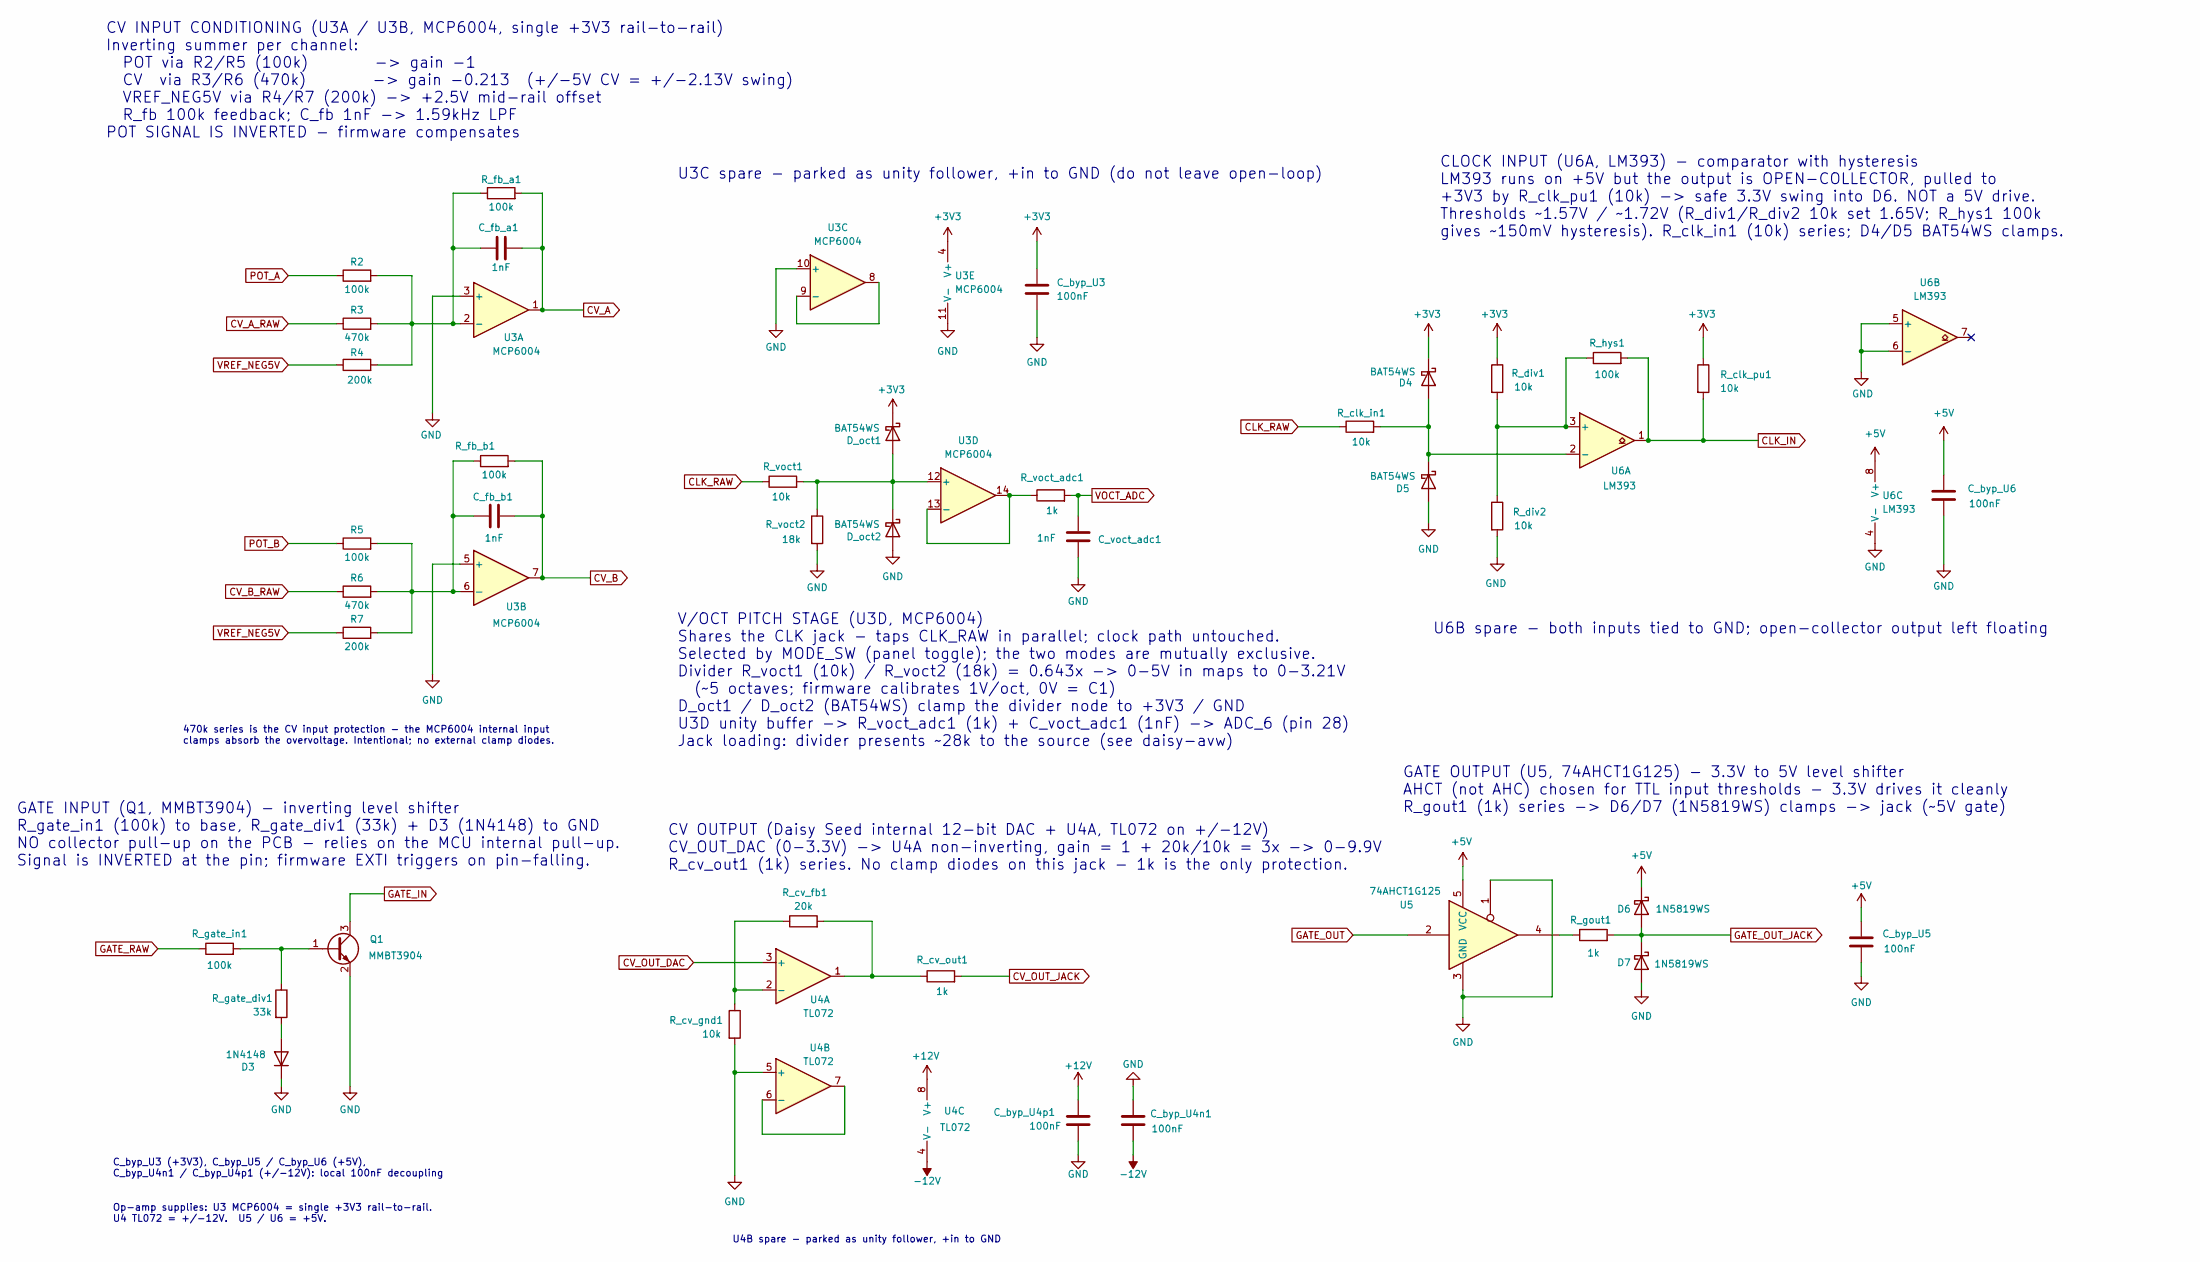
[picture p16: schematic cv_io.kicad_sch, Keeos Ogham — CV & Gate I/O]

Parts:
C_byp_U3, C_byp_U4n1, C_byp_U4p1, C_byp_U5, C_byp_U6: 100nF; C_0603_1608Metric; LCSC C14663
C_fb_a1: 1nF; C_0603_1608Metric; LCSC C1588
C_fb_b1: 1nF; C_0603_1608Metric; LCSC C1588
C_voct_adc1: 1nF; C_0603_1608Metric; LCSC C1588
D3: 1N4148; D_SOD-323; LCSC C2128
D4, D5: BAT54WS; D_SOD-323; LCSC C22629
D6, D7: 1N5819WS; D_SOD-323; LCSC C191023
D_oct1, D_oct2: BAT54WS; D_SOD-323; LCSC C22629
Q1: MMBT3904; SOT-23; LCSC C20526
R2, R5: 100k; R_0603_1608Metric; LCSC C25803
R3, R6: 470k; R_0603_1608Metric; LCSC C23178
R4, R7: 200k; R_0603_1608Metric; LCSC C25811
R_clk_in1: 10k; R_0603_1608Metric; LCSC C25804
R_clk_pu1: 10k; R_0603_1608Metric; LCSC C25804
R_cv_fb1: 20k; R_0603_1608Metric; LCSC C4184
R_cv_gnd1: 10k; R_0603_1608Metric; LCSC C25804
R_cv_out1: 1k; R_0603_1608Metric; LCSC C21190
R_div1, R_div2: 10k; R_0603_1608Metric; LCSC C25804
R_fb_a1: 100k; R_0603_1608Metric; LCSC C25803
R_fb_b1: 100k; R_0603_1608Metric; LCSC C25803
R_gate_div1: 33k; R_0603_1608Metric; LCSC C4216
R_gate_in1: 100k; R_0603_1608Metric; LCSC C25803
R_gout1: 1k; R_0603_1608Metric; LCSC C21190
R_hys1: 100k; R_0603_1608Metric; LCSC C25803
R_voct1: 10k; R_0603_1608Metric; LCSC C25804
R_voct2: 18k; R_0603_1608Metric; LCSC C25810
R_voct_adc1: 1k; R_0603_1608Metric; LCSC C21190
U3: MCP6004; TSSOP-14_4.4x5mm_P0.65mm; LCSC C50282
U4: TL072; SOIC-8_3.9x4.9mm_P1.27mm; LCSC C67473
U5: 74AHCT1G125; SOT-23-5; LCSC C7484
U6: LM393; SOIC-8_3.9x4.9mm_P1.27mm; LCSC C136033

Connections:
+3V3: C_byp_U3.1, D4.1 (K), D_oct1.1 (K), R_clk_pu1.1, R_div1.1, U3.4 (V+); also elsewhere on the board
+5V: C_byp_U5.1, C_byp_U6.1, D6.1 (K), U5.5 (VCC), U6.8 (V+); also elsewhere on the board
+12V: C_byp_U4p1.1, U4.8 (V+); also elsewhere on the board
-12V: C_byp_U4n1.2, U4.4 (V-); also elsewhere on the board
CLK_IN: R_clk_pu1.2, R_hys1.2, U6.1; also elsewhere on the board
CLK_RAW: R_clk_in1.1, R_voct1.1; also elsewhere on the board
CV_A: C_fb_a1.2, R_fb_a1.2, U3.1; also elsewhere on the board
CV_A_RAW: R3.1; also elsewhere on the board
CV_B: C_fb_b1.2, R_fb_b1.2, U3.7; also elsewhere on the board
CV_B_RAW: R6.1; also elsewhere on the board
CV_OUT_DAC: U4.3 (+); also elsewhere on the board
CV_OUT_JACK: R_cv_out1.2; also elsewhere on the board
GATE_IN: Q1.3 (C); also elsewhere on the board
GATE_OUT: U5.2; also elsewhere on the board
GATE_OUT_JACK: D6.2 (A), D7.1 (K), R_gout1.2; also elsewhere on the board
GATE_RAW: R_gate_in1.1; also elsewhere on the board
GND: C_byp_U3.2, C_byp_U4n1.1, C_byp_U4p1.2, C_byp_U5.2, C_byp_U6.2, C_voct_adc1.1, D3.1 (K), D5.2 (A), D7.2 (A), D_oct2.2 (A), Q1.2 (E), R_cv_gnd1.2, R_div2.2, R_voct2.2, U3.3 (+), U3.5 (+), U3.10 (+), U3.11 (V-), U4.5 (+), U5.1, U5.3 (GND), U6.4 (V-), U6.5 (+), U6.6 (-); also elsewhere on the board
unnamed: D3.2 (A), R_gate_div1.2
unnamed: D4.2 (A), D5.1 (K), R_clk_in1.2, U6.2 (-)
unnamed: D_oct1.2 (A), D_oct2.1 (K), R_voct1.2, R_voct2.1, U3.12 (+)
unnamed: Q1.1 (B), R_gate_div1.1, R_gate_in1.2
unnamed: R_cv_fb1.2, R_cv_out1.1, U4.1
unnamed: R_gout1.1, U5.4
unnamed: C_fb_a1.1, R2.2, R3.2, R4.2, R_fb_a1.1, U3.2 (-)
unnamed: C_fb_b1.1, R5.2, R6.2, R7.2, R_fb_b1.1, U3.6 (-)
unnamed: U3.8, U3.9 (-)
unnamed: R_voct_adc1.1, U3.13 (-), U3.14
unnamed: R_cv_fb1.1, R_cv_gnd1.1, U4.2 (-)
unnamed: U4.6 (-), U4.7
unnamed: R_div1.2, R_div2.1, R_hys1.1, U6.3 (+)
POT_A: R2.1; also elsewhere on the board
POT_B: R5.1; also elsewhere on the board
VOCT_ADC: C_voct_adc1.2, R_voct_adc1.2; also elsewhere on the board
VREF_NEG5V: R4.1, R7.1; also elsewhere on the board

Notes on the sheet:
U3C spare - parked as unity follower, +in to GND (do not leave open-loop)
U6B spare - both inputs tied to GND; open-collector output left floating
470k series is the CV input protection - the MCP6004 internal input clamps absorb the overvoltage. Intentional; no external clamp diodes.
V/OCT PITCH STAGE (U3D, MCP6004) Shares the CLK jack - taps CLK_RAW in parallel; clock path untouched. Selected by MODE_SW (panel toggle); the two modes are mutually exclusive. Divider R_voct1 (10k) / R_voct2 (18k) = 0.643x -> 0-5V in maps to 0-3.21V (~5 octaves; firmware calibrates 1V/oct, 0V = C1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
C_byp_U3 (+3V3), C_byp_U5 / C_byp_U6 (+5V), C_byp_U4n1 / C_byp_U4p1 (+/-12V): local 100nF decoupling
U4B spare - parked as unity follower, +in to GND
Op-amp supplies: U3 MCP6004 = single +3V3 rail-to-rail. U4 TL072 = +/-12V. U5 / U6 = +5V.
CV INPUT CONDITIONING (U3A / U3B, MCP6004, single +3V3 rail-to-rail) Inverting summer per channel: POT via R2/R5 (100k) -> gain -1 CV via R3/R6 (470k) -> gain -0.213 (+/-5V CV = +/-2.13V swing) VREF_NEG5V via R4/R7 (200k) -> +2.5V mid-rail offset R_fb 100k feedback; C_fb 1nF -> 1.59kHz LPF POT SIGN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
CLOCK INPUT (U6A, LM393) - comparator with hysteresis LM393 runs on +5V but the output is OPEN-COLLECTOR, pulled to +3V3 by R_clk_pu1 (10k) -> safe 3.3V swing into D6. NOT a 5V drive. Thresholds ~1.57V / ~1.72V (R_div1/R_div2 10k set 1.65V; R_hys1 100k gives ~150mV hysteresis). R_clk_in1 (10k) seri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
GATE INPUT (Q1, MMBT3904) - inverting level shifter R_gate_in1 (100k) to base, R_gate_div1 (33k) + D3 (1N4148) to GND NO collector pull-up on the PCB - relies on the MCU internal pull-up. Signal is INVERTED at the pin; firmware EXTI triggers on pin-falling.
GATE OUTPUT (U5, 74AHCT1G125) - 3.3V to 5V level shifter AHCT (not AHC) chosen for TTL input thresholds - 3.3V drives it cleanly R_gout1 (1k) series -> D6/D7 (1N5819WS) clamps -> jack (~5V gate)
CV OUTPUT (Daisy Seed internal 12-bit DAC + U4A, TL072 on +/-12V) CV_OUT_DAC (0-3.3V) -> U4A non-inverting, gain = 1 + 20k/10k = 3x -> 0-9.9V R_cv_out1 (1k) series. No clamp diodes on this jack - 1k is the only protection.

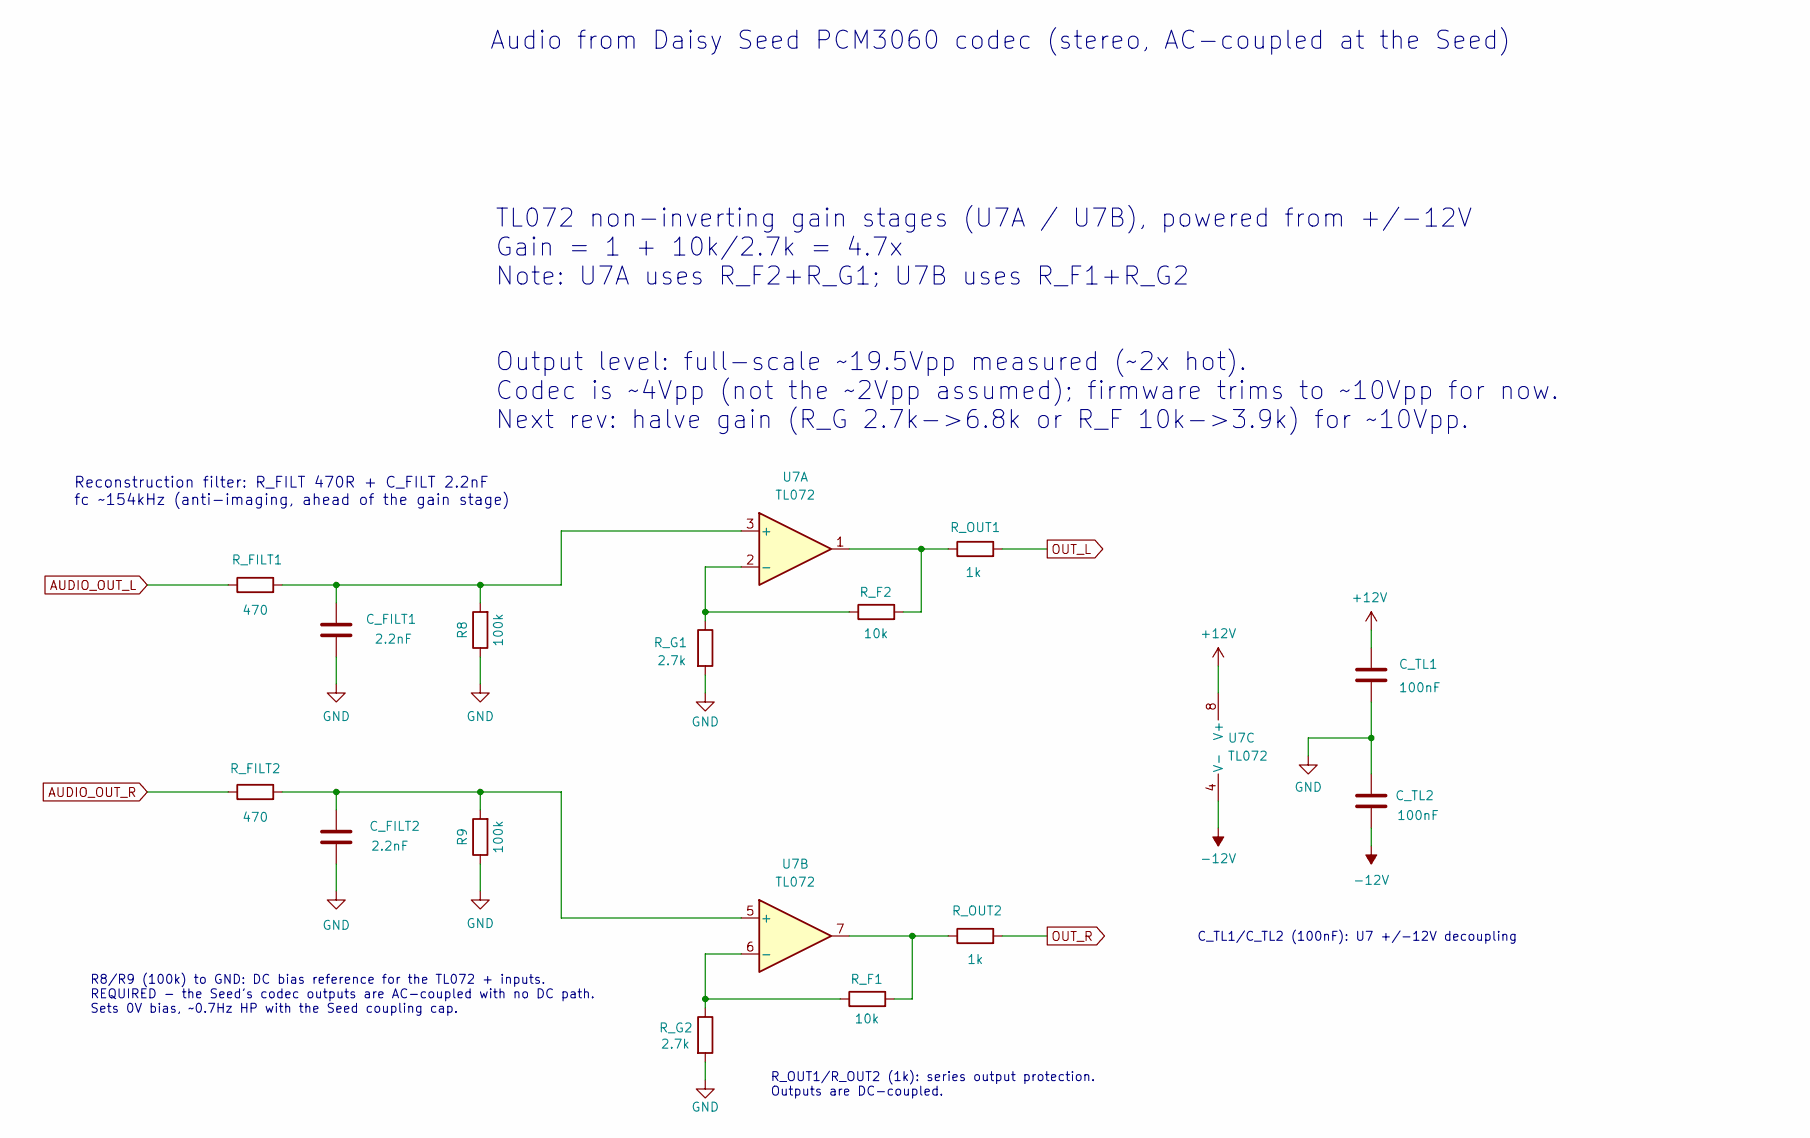
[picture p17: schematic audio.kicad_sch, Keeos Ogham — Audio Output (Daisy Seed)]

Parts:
C_FILT1, C_FILT2: 2.2nF; C_0603_1608Metric; LCSC C1604
C_TL1, C_TL2: 100nF; C_0603_1608Metric; LCSC C14663
R8, R9: 100k; R_0603_1608Metric; LCSC C25803
R_F1, R_F2: 10k; R_0603_1608Metric; LCSC C25804
R_FILT1, R_FILT2: 470; R_0603_1608Metric; LCSC C23179
R_G1, R_G2: 2.7k; R_0603_1608Metric; LCSC C13167
R_OUT1, R_OUT2: 1k; R_0603_1608Metric; LCSC C21190
U7: TL072; SOIC-8_3.9x4.9mm_P1.27mm; LCSC C67473

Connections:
+12V: C_TL1.1, U7.8 (V+); also elsewhere on the board
-12V: C_TL2.2, U7.4 (V-); also elsewhere on the board
AUDIO_OUT_L: R_FILT1.1; also elsewhere on the board
AUDIO_OUT_R: R_FILT2.1; also elsewhere on the board
GND: C_FILT1.2, C_FILT2.2, C_TL1.2, C_TL2.1, R8.1, R9.1, R_G1.2, R_G2.2; also elsewhere on the board
unnamed: R_F1.2, R_OUT2.1, U7.7
unnamed: R_F2.2, R_OUT1.1, U7.1
unnamed: C_FILT1.1, R8.2, R_FILT1.2, U7.3 (+)
unnamed: R_F2.1, R_G1.1, U7.2 (-)
unnamed: C_FILT2.1, R9.2, R_FILT2.2, U7.5 (+)
unnamed: R_F1.1, R_G2.1, U7.6 (-)
OUT_L: R_OUT1.2; also elsewhere on the board
OUT_R: R_OUT2.2; also elsewhere on the board

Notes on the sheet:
R_OUT1/R_OUT2 (1k): series output protection. Outputs are DC-coupled.
Audio from Daisy Seed PCM3060 codec (stereo, AC-coupled at the Seed)
TL072 non-inverting gain stages (U7A / U7B), powered from +/-12V Gain = 1 + 10k/2.7k = 4.7x Note: U7A uses R_F2+R_G1; U7B uses R_F1+R_G2
Output level: full-scale ~19.5Vpp measured (~2x hot). Codec is ~4Vpp (not the ~2Vpp assumed); firmware trims to ~10Vpp for now. Next rev: halve gain (R_G 2.7k->6.8k or R_F 10k->3.9k) for ~10Vpp.
Reconstruction filter: R_FILT 470R + C_FILT 2.2nF fc ~154kHz (anti-imaging, ahead of the gain stage)
R8/R9 (100k) to GND: DC bias reference for the TL072 + inputs. REQUIRED - the Seed's codec outputs are AC-coupled with no DC path. Sets 0V bias, ~0.7Hz HP with the Seed coupling cap.
C_TL1/C_TL2 (100nF): U7 +/-12V decoupling

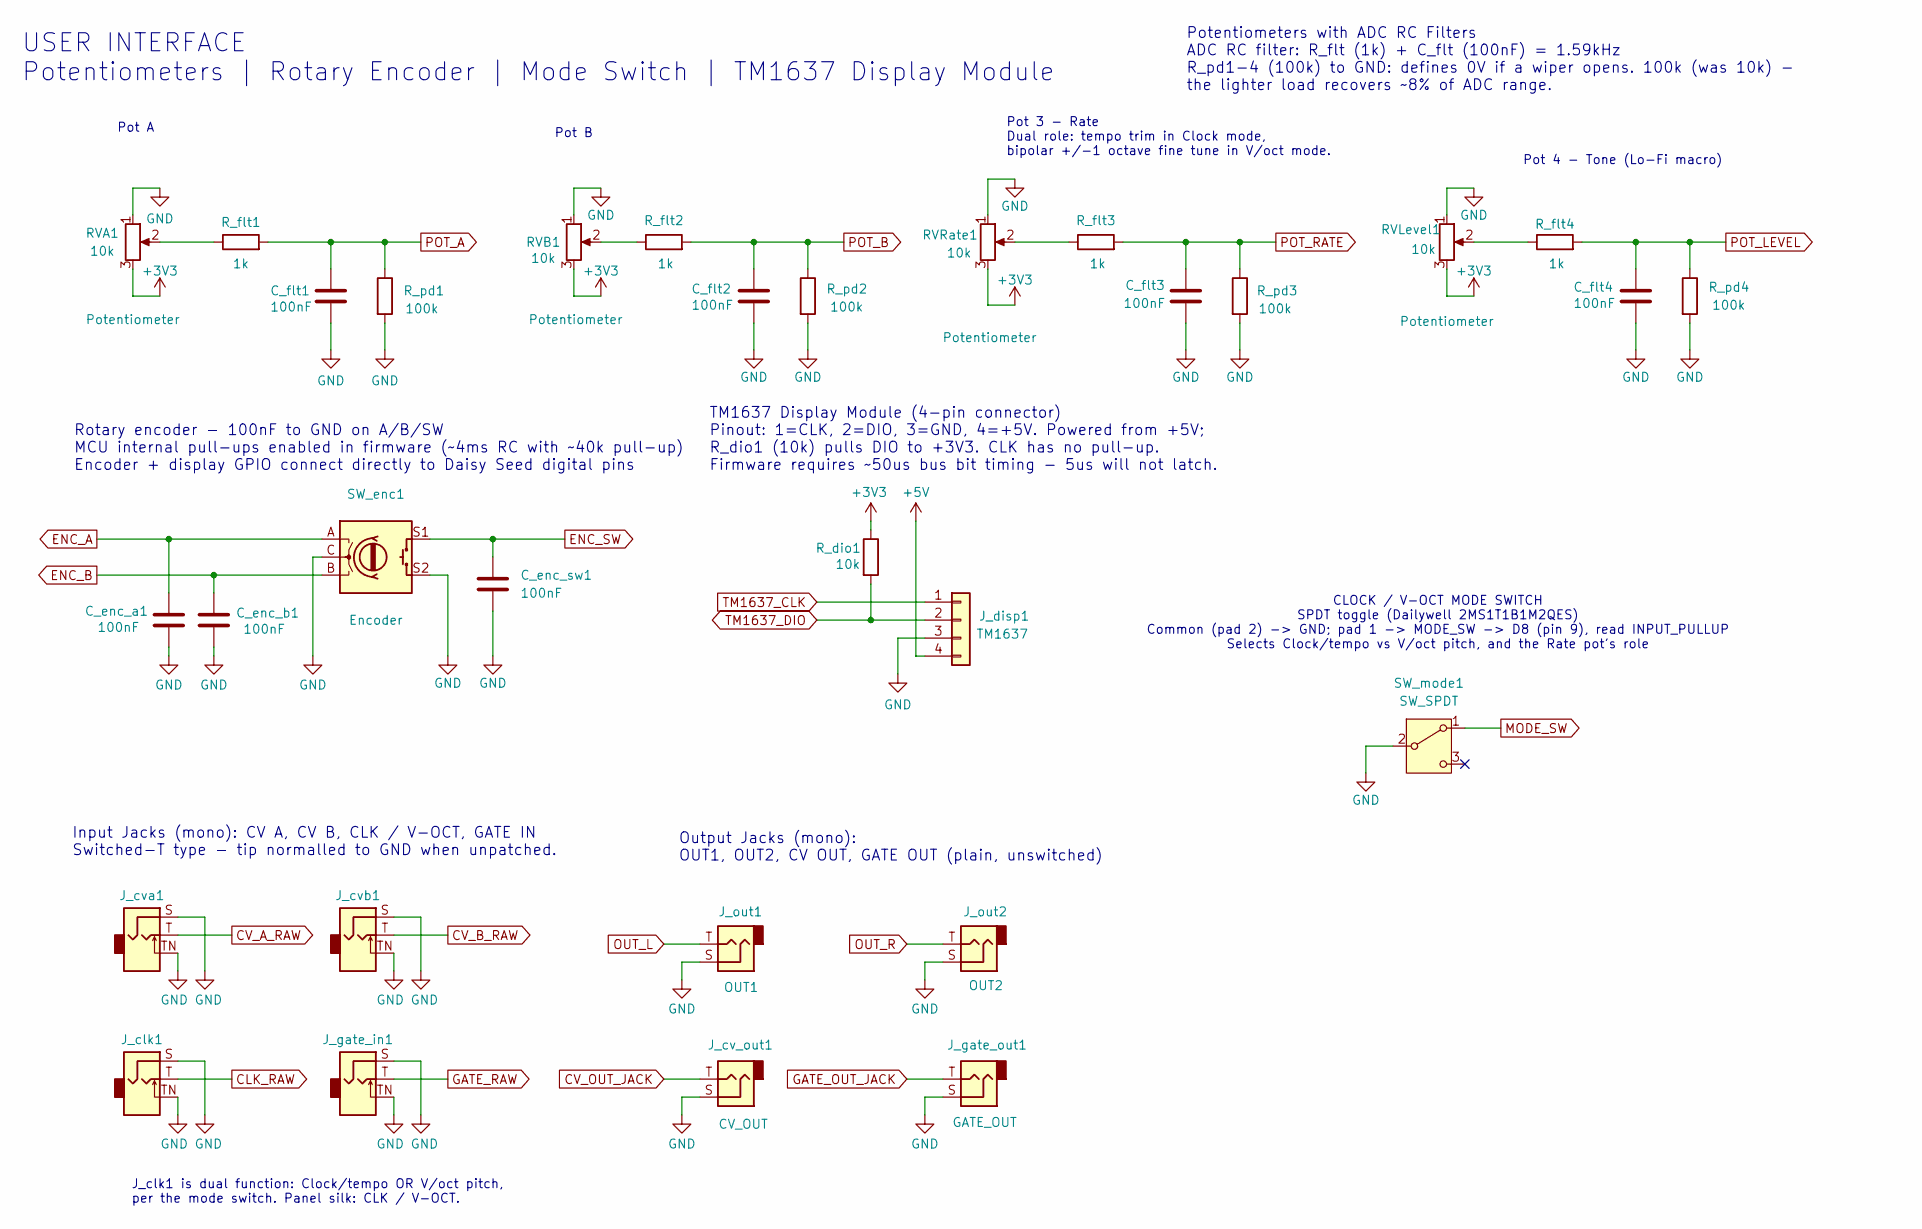
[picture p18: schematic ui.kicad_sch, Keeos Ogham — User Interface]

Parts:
C_enc_a1: 100nF; C_0603_1608Metric; LCSC C14663
C_enc_b1: 100nF; C_0603_1608Metric; LCSC C14663
C_enc_sw1: 100nF; C_0603_1608Metric; LCSC C14663
C_flt1, C_flt2, C_flt3, C_flt4: 100nF; C_0603_1608Metric; LCSC C14663
J_clk1: AudioJack2_SwitchT; Jack_3.5mm_QingPu_WQP-PJ398SM_Vertical_CircularHoles
J_cv_out1: CV_OUT; Jack_3.5mm_QingPu_WQP-PJ398SM_Vertical_CircularHoles
J_cva1: AudioJack2_SwitchT; Jack_3.5mm_QingPu_WQP-PJ398SM_Vertical_CircularHoles
J_cvb1: AudioJack2_SwitchT; Jack_3.5mm_QingPu_WQP-PJ398SM_Vertical_CircularHoles
J_disp1: TM1637; PinHeader_1x04_P2.54mm_Vertical
J_gate_in1: AudioJack2_SwitchT; Jack_3.5mm_QingPu_WQP-PJ398SM_Vertical_CircularHoles
J_gate_out1: GATE_OUT; Jack_3.5mm_QingPu_WQP-PJ398SM_Vertical_CircularHoles
J_out1: OUT1; Jack_3.5mm_QingPu_WQP-PJ398SM_Vertical_CircularHoles
J_out2: OUT2; Jack_3.5mm_QingPu_WQP-PJ398SM_Vertical_CircularHoles
RVA1: 10k; Potentiometer_Alpha_RD901F-40-00D_Single_Vertical
RVB1: 10k; Potentiometer_Alpha_RD901F-40-00D_Single_Vertical
RVLevel1: 10k; Potentiometer_Alpha_RD901F-40-00D_Single_Vertical
RVRate1: 10k; Potentiometer_Alpha_RD901F-40-00D_Single_Vertical
R_dio1: 10k; R_0603_1608Metric; LCSC C25804
R_flt1, R_flt2, R_flt3, R_flt4: 1k; R_0603_1608Metric; LCSC C21190
R_pd1, R_pd2, R_pd3, R_pd4: 100k; R_0603_1608Metric; LCSC C25803
SW_enc1: Encoder; RotaryEncoder_Alps_EC11E-Switch_Vertical_H20mm
SW_mode1: SW_SPDT; SW_2MS1T1B1M2QES

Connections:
+3V3: RVA1.3, RVB1.3, RVLevel1.3, RVRate1.3, R_dio1.1; also elsewhere on the board
+5V: J_disp1.4; also elsewhere on the board
CLK_RAW: J_clk1.T; also elsewhere on the board
CV_A_RAW: J_cva1.T; also elsewhere on the board
CV_B_RAW: J_cvb1.T; also elsewhere on the board
CV_OUT_JACK: J_cv_out1.T; also elsewhere on the board
ENC_A: C_enc_a1.1, SW_enc1.A; also elsewhere on the board
ENC_B: C_enc_b1.1, SW_enc1.B; also elsewhere on the board
ENC_SW: C_enc_sw1.1, SW_enc1.S1; also elsewhere on the board
GATE_OUT_JACK: J_gate_out1.T; also elsewhere on the board
GATE_RAW: J_gate_in1.T; also elsewhere on the board
GND: C_enc_a1.2, C_enc_b1.2, C_enc_sw1.2, C_flt1.2, C_flt2.2, C_flt3.2, C_flt4.2, J_clk1.S, J_clk1.TN, J_cv_out1.S, J_cva1.S, J_cva1.TN, J_cvb1.S, J_cvb1.TN, J_disp1.3, J_gate_in1.S, J_gate_in1.TN, J_gate_out1.S, J_out1.S, J_out2.S, RVA1.1, RVB1.1, RVLevel1.1, RVRate1.1, R_pd1.2, R_pd2.2, R_pd3.2, R_pd4.2, SW_enc1.C, SW_enc1.S2, SW_mode1.2 (B); also elsewhere on the board
MODE_SW: SW_mode1.1 (A); also elsewhere on the board
unnamed: RVA1.2, R_flt1.1
unnamed: RVB1.2, R_flt2.1
unnamed: RVLevel1.2, R_flt4.1
unnamed: RVRate1.2, R_flt3.1
OUT_L: J_out1.T; also elsewhere on the board
OUT_R: J_out2.T; also elsewhere on the board
POT_A: C_flt1.1, R_flt1.2, R_pd1.1; also elsewhere on the board
POT_B: C_flt2.1, R_flt2.2, R_pd2.1; also elsewhere on the board
POT_LEVEL: C_flt4.1, R_flt4.2, R_pd4.1; also elsewhere on the board
POT_RATE: C_flt3.1, R_flt3.2, R_pd3.1; also elsewhere on the board
TM1637_CLK: J_disp1.1; also elsewhere on the board
TM1637_DIO: J_disp1.2, R_dio1.2; also elsewhere on the board

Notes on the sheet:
CLOCK / V-OCT MODE SWITCH SPDT toggle (Dailywell 2MS1T1B1M2QES) Common (pad 2) -> GND; pad 1 -> MODE_SW -> D8 (pin 9), read INPUT_PULLUP Selects Clock/tempo vs V/oct pitch, and the Rate pot's role
Output Jacks (mono): OUT1, OUT2, CV OUT, GATE OUT (plain, unswitched)
Input Jacks (mono): CV A, CV B, CLK / V-OCT, GATE IN Switched-T type - tip normalled to GND when unpatched.
Pot A
Rotary encoder - 100nF to GND on A/B/SW MCU internal pull-ups enabled in firmware (~4ms RC with ~40k pull-up) Encoder + display GPIO connect directly to Daisy Seed digital pins
TM1637 Display Module (4-pin connector) Pinout: 1=CLK, 2=DIO, 3=GND, 4=+5V. Powered from +5V; R_dio1 (10k) pulls DIO to +3V3. CLK has no pull-up. Firmware requires ~50us bus bit timing - 5us will not latch.
USER INTERFACE Potentiometers | Rotary Encoder | Mode Switch | TM1637 Display Module
Potentiometers with ADC RC Filters ADC RC filter: R_flt (1k) + C_flt (100nF) = 1.59kHz R_pd1-4 (100k) to GND: defines 0V if a wiper opens. 100k (was 10k) - the lighter load recovers ~8% of ADC range.
Pot B
Pot 3 - Rate Dual role: tempo trim in Clock mode, bipolar +/-1 octave fine tune in V/oct mode.
Pot 4 - Tone (Lo-Fi macro)
J_clk1 is dual function: Clock/tempo OR V/oct pitch, per the mode switch. Panel silk: CLK / V-OCT.

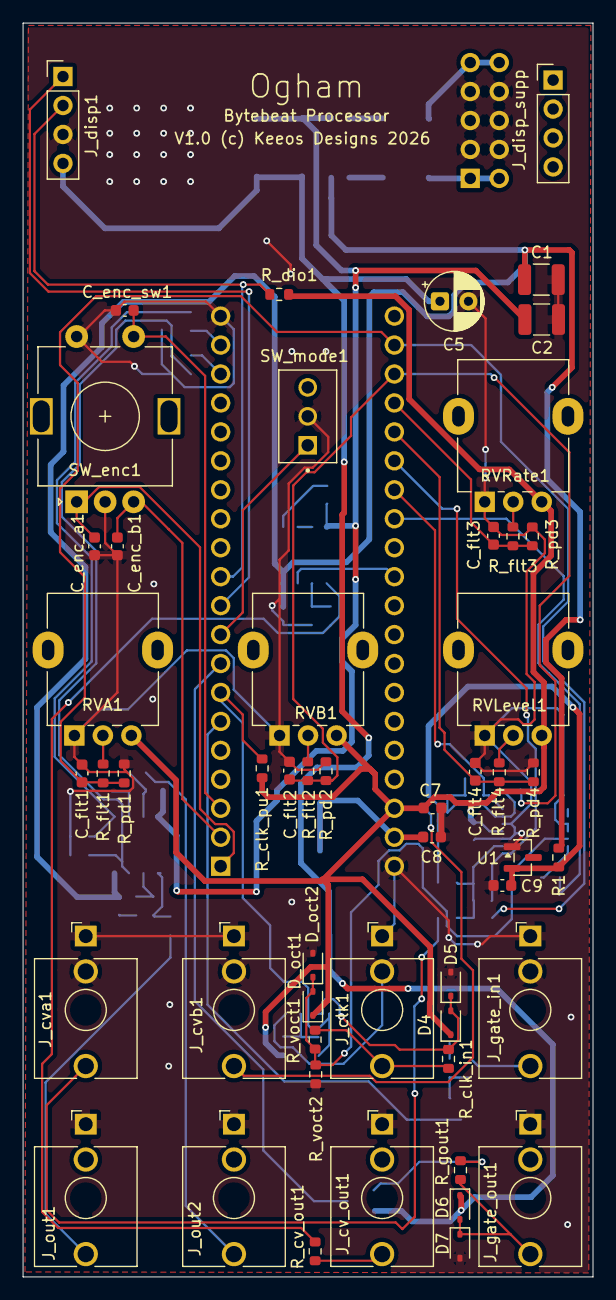
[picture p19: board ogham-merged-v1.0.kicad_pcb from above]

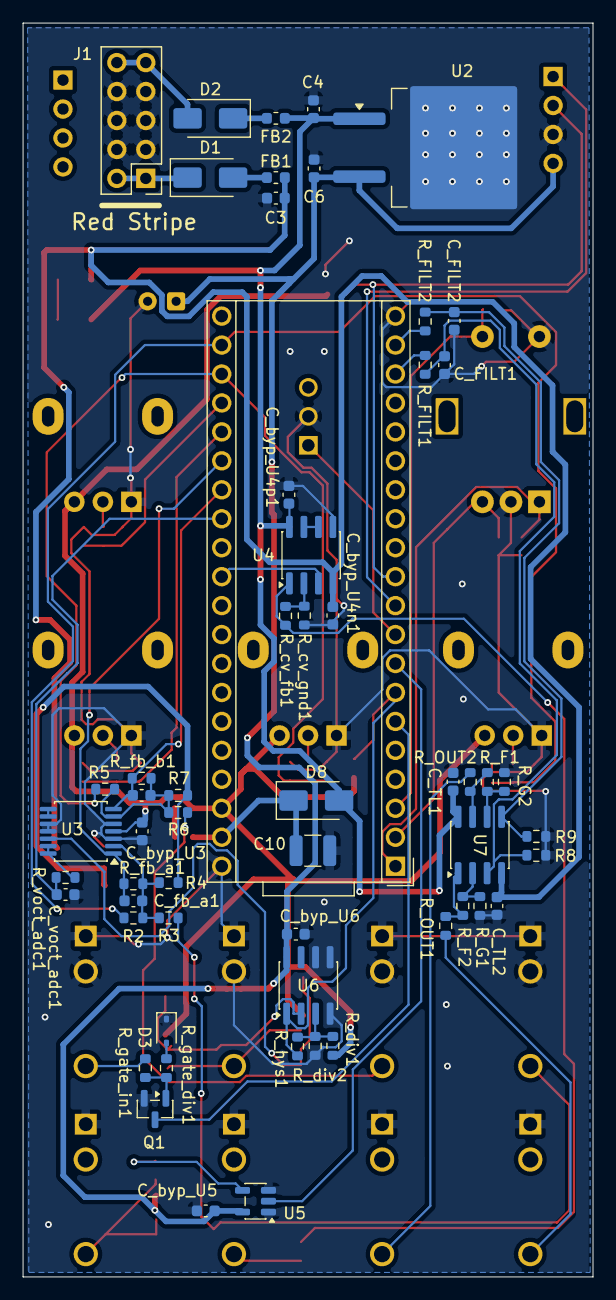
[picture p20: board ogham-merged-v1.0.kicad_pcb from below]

Board: 2 copper layers, 50.0 x 110.0 mm, 109 parts (57 on the bottom side), 61 nets.

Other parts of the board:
J_disp_supp: PinHeader_1x04_P2.54mm_Vertical

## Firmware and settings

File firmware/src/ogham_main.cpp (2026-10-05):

// -----------------------------------------------------------------------------
// Ogham — a dual-voice bytebeat synthesizer for Eurorack
//
// Author:     Steven Collins, 2026, Keeos.io
// Copyright:  (c) 2026 Steven Collins
//
// SPDX-FileCopyrightText: 2026 Steven Collins <https://keeos.io>
// SPDX-License-Identifier: MIT
//
// This file is part of the Ogham firmware. See LICENSE-firmware.txt at the
// repository root for the full licence text.
// https://github.com/keeos-io/ogham
// -----------------------------------------------------------------------------

#include "daisy_seed.h"
#include "util/PersistentStorage.h"
#include "ogham_pins.h"
#include "bytebeat_engine.h"
#include "ogham_audio_pipeline.h"
#include "ogham_controls.h"
#include "ogham_display.h"
#include "ogham_cv_output.h"
#include "bpm_clock.h"
#include "tm1637.h"
#include <cmath>
#include <cstring>

using namespace daisy;

// --- Global objects ---
static DaisySeed hw;
static Encoder encoder;
static GateIn gateIn;
static GateIn clockIn;
static GPIO gateOutGpio;

static BytebeatEngine engine;
static AudioPipeline pipeline;
static Controls controls;

// --- Encoder scan timer (daisy-szs) ---
// The quadrature decoder is POLLED (these pins have no timer-encoder alternate
// function, so hardware decoding isn't available, and EXTI on a mechanical
// encoder just floods the CPU with bounce). Polling only works if it outruns the
// contacts: a 24 PPR encoder is 96 quadrature transitions per revolution, so a
// hard 6-8 rev/s crank puts out 576-768 transitions/s. 20kHz gives >26 samples
// per transition even at a full crank, and a missed transition is a lost detent
// exactly at the speeds the encoder ACCELERATION is designed for. Costs ~0.25%
// CPU (two GPIO reads + a table lookup). Falls back to the audio callback if the
// timer won't start.
static TimerHandle encTim;
static bool encTimerRunning = false;
static constexpr uint32_t ENC_SCAN_HZ = 20000;
static void EncoderScanCallback(void*) { controls.SampleEncoder(); }
static TM1637 tm1637;
static Display display;
static CvOutput cvOutput;
static BpmClock bpmClock;

// --- Firmware version: shown for ~1s at boot ("M.mm") and persisted to QSPI so a
//     future build can read the previously-installed version (e.g. to migrate).
//     BUMP THIS on every flashed release. ---
static constexpr int      FW_VER_MAJOR = 1;
static constexpr int      FW_VER_MINOR = 19;  // 0..99, shown as two digits (v1.19)
static constexpr uint32_t FW_VERSION   = (uint32_t)FW_VER_MAJOR * 100u + FW_VER_MINOR; // 100 = v1.00

// --- Persisted settings (QSPI). Bump SETTINGS_VERSION to invalidate old layouts. ---
static constexpr uint32_t SETTINGS_VERSION = 16; // v16: V/oct rate-tracking
struct OghamSettings {
    uint32_t version;
    int out1Formula;
    int out2Formula;
    FxChainConfig fx;   // 3-stage FX chain (mixes + flavour params + topology)
    // Out2 drone frozen state (daisy-pcq), meaningful only when fx.out2Drone: the
    // exact phase increment (rate) + A/B captured at decouple, so the drone's pitch
    // and sound survive a power cycle instead of re-snapshotting live boot state.
    uint64_t droneInc;
    int32_t  droneA;
    int32_t  droneB;
    uint32_t fwVersion;   // firmware version that last wrote these settings (FW_VERSION)
    bool operator!=(const OghamSettings& o) const {
        return version != o.version
            || out1Formula != o.out1Formula
            || out2Formula != o.out2Formula
            || memcmp(&fx, &o.fx, sizeof(FxChainConfig)) != 0
            || droneInc != o.droneInc
            || droneA != o.droneA
            || droneB != o.droneB
            || fwVersion != o.fwVersion;   // so a version-only change actually persists
    }
    bool operator==(const OghamSettings& o) const { return !(*this != o); }
};
static PersistentStorage<OghamSettings> storage(hw.qspi);
static bool settingsDirty = false;
static uint32_t lastSettingChangeMs = 0;
static constexpr uint32_t SETTINGS_SAVE_DELAY_MS = 3000;  // debounce flash writes

// --- Telemetry for the PC monitor (read live over SWD; daisy-emp). ---
// All fields are 4 bytes for a predictable, padding-free layout. `volatile`
// keeps the writes alive (nothing on-device reads this struct).
struct Telemetry {
    uint32_t magic;        // 0x4F474841 ("OGHA")
    uint32_t counter;      // increments each loop (liveness)
    uint32_t segs;         // 4 TM1637 seg bytes, LE: seg0 | seg1<<8 | seg2<<16 | seg3<<24
    uint32_t modeState;    // funcMode | selOut<<8 | lofiClean<<16 | extClockActive<<24
    uint32_t ioState;      // gateIn | clockIn<<8
    int32_t  out1Formula;
    int32_t  out2Formula;
    int32_t  paramA;
    int32_t  paramB;
    float    rate;
    float    extClockRate;
    float    potA;         // raw ADC0
    float    potB;         // raw ADC1
    float    potRate;      // raw ADC2
    float    potLevel;     // raw ADC3
    float    combinedA;    // 0-1 (pot+CV, MCP6004)
    float    combinedB;    // 0-1
    float    cvA;          // raw ADC4 (CV_A pin)
    float    cvB;          // raw ADC5 (CV_B pin)
    uint32_t cpuPeak;      // audio-callback peak work (cycles)
    uint32_t cpuPeriod;    // audio block period (cycles)
    uint32_t syncCount;    // gate hard-sync (EXTI) events
    int32_t  fxType;       // selected post-Lo-Fi effect (FxType; 0 = Off)
    // Appended after fxType so the monitor's existing 22-word read still
    // matches. BPM estimator state (daisy-3q1).
    float    bpm;          // detected tempo at the current rate
    float    baseBpm;      // same, normalised to 1x rate (a formula constant)
    float    bpmConfidence;// 0-1: peak height x proportion of estimates agreeing
    uint32_t bpmLocked;    // 1 once an estimate has been adopted
};
volatile Telemetry g_telemetry;
volatile uint32_t g_syncCount = 0;   // incremented by the gate EXTI ISR

// --- Timing ---
static uint32_t lastDisplayTime = 0;
static constexpr uint32_t DISPLAY_INTERVAL_MS = 33; // ~30Hz

// --- Display brightness + auto-off (v1.19, FX field 22, "br.NN") ---
// The TM1637's multiplexed LED current couples into the audio outputs as a
// buzz on the v1.0 board (it needs a series R + bulk cap at J_disp1 to fix in
// hardware), so the display can go dark DISPLAY_SLEEP_MS after the last
// movement of the encoder or a knob, and wake on the next one. The Mode
// switch, CV, gates and clock never wake it. It stays awake in the FX menu
// and while a value flash is showing, so a flash still gets its full time and
// then goes straight to dark.
//
// One menu value carries both settings: the units digit is the brightness
// (0-7, the TM1637's eight levels) and a tens digit of 1 adds auto-off, so the
// valid values are 0-7 and 10-17. FxChainConfig::displayMode stores the menu
// value + 1, so the 0 that every pre-v1.19 patch holds reads as the default.
static constexpr uint32_t DISPLAY_SLEEP_MS = 1000;
static constexpr int DISPLAY_MODE_DEFAULT = 14;   // brightness 4 (as v1.18) + auto-off
static uint32_t lastControlMs = 0;
static bool displayAsleep = false;
static inline void NoteControlMoved() { lastControlMs = System::GetNow(); }

static inline bool DisplayModeValid(int v) { return v >= 0 && v <= 17 && v % 10 <= 7; }
static int DisplayMode(uint8_t stored) {
    int v = (int)stored - 1;
    return DisplayModeValid(v) ? v : DISPLAY_MODE_DEFAULT;
}
static inline uint8_t DisplayBrightness(uint8_t stored) { return (uint8_t)(DisplayMode(stored) % 10); }
static inline bool DisplayAutoOff(uint8_t stored) { return DisplayMode(stored) >= 10; }
// One detent through 0-7 / 10-17, stepping over 8 and 9 in either direction.
static uint8_t NextDisplayMode(uint8_t stored, int dir) {
    int v = DisplayMode(stored) + (dir > 0 ? 1 : -1);
    if (v == 8 || v == 9) v = (dir > 0) ? 10 : 7;
    if (v < 0) v = 0;
    if (v > 17) v = 17;
    return (uint8_t)(v + 1);
}

// Tone pot movement needed to wake the display. Rate's flash threshold is
// 0.001 (~10x the ADC noise); this is a little coarser, since a stray wake
// costs more than a missed hairline nudge.
static constexpr float TONE_WAKE_EPS = 0.002f;

// --- Func (encoder) state machine ---
// SELECT: turn = formula, short-click = switch voice.
// FX menu: turn = cycle field; click = enter edit (value flashes); turn = edit
//          value; click = commit + back to navigate.
// Long-press enters FX from SELECT, and exits FX from anywhere (incl. editing).
enum FuncMode { FUNC_SELECT = 0, FUNC_FX = 1 };
static FuncMode funcMode = FUNC_SELECT;
static int  selOut = 0;       // voice the encoder edits in SELECT mode (0=Out1, 1=Out2)
// Current FX field (0..FX_NUM_FIELDS-1). Survives leaving and re-entering the
// menu so you land back where you were; zero-initialised, so a power cycle
// resets it to the first field. Not persisted to QSPI, by design.
static int  fxField = 0;
static bool fxEditing = false; // FX menu: false = navigate fields, true = edit value

// Live FX-chain config (the 0..99 source of truth; loaded from / saved to QSPI).
static FxChainConfig g_fx;

// Pointer to a stage param field's value (fields 2..13). Order MUST match
// FxChainConfig, Display::ShowFxEdit, and the menu. Returns nullptr for the
// global on/off (0) and the chain toggle (1).
static uint8_t* FxFieldPtr(FxChainConfig& f, int field) {
    switch (field) {
        case 2:  return &f.chorusLevel;  case 3:  return &f.chorusType;  case 4:  return &f.chorusP1;  case 5:  return &f.chorusP2;
        case 6:  return &f.flangerLevel; case 7:  return &f.flangerType; case 8:  return &f.flangerP1; case 9:  return &f.flangerP2;
        case 10: return &f.phaserLevel;  case 11: return &f.phaserType;  case 12: return &f.phaserP1; case 13: return &f.phaserP2;
        default: return nullptr;
    }
}

// True for the per-stage "type" sub-field (sub == 1): fields 3, 7, 11.
static inline bool FxFieldIsType(int field) {
    return field >= 2 && field <= 13 && ((field - 2) % 4) == 1;
}

// Param-interp grid (q) steps through this discrete list (0 = off). dir = turn.
static uint8_t NextQuant(uint8_t cur, int dir) {
    static const uint8_t list[] = {0, 4, 8, 16, 32, 64, 128};
    const int n = (int)(sizeof(list) / sizeof(list[0]));
    int idx = 0;
    for (int i = 0; i < n; i++) if (list[i] == cur) { idx = i; break; }
    idx += (dir > 0) ? 1 : -1;
    if (idx < 0) idx = 0;
    if (idx >= n) idx = n - 1;
    return list[idx];
}

// Encoder gesture tracking (short click / long press / double click)
static bool encWasPressed = false;
static uint32_t encPressStart = 0;
static bool encLongFired = false;
static constexpr uint32_t LONG_PRESS_MS = 600;  // hold threshold to enter/exit the FX menu

// Encoder acceleration: the faster you turn, the bigger the step (rapid travel
// through the formula bank); slow turns stay 1-per-detent for fine control.
static uint32_t lastEncMs = 0;
static constexpr uint32_t ENC_FAST_MS = 25;   // detent gap below this -> fastest
static constexpr uint32_t ENC_MED_MS  = 50;
static constexpr uint32_t ENC_SLOW_MS = 90;
// Acceleration multipliers (tuned for the 100-slot function range): a hard crank
// jumps ~8/detent (~12 detents across the whole range), while single/slow detents
// stay 1-for-1 for precise landing. No-wrap clamps hard cranks at F0 / AA.
static constexpr int ENC_FAST_MULT = 8;
static constexpr int ENC_MED_MULT  = 4;
static constexpr int ENC_SLOW_MULT = 2;
// Menu-navigation acceleration is deliberately GENTLER than the function
// selector's 8/4/2. The menu is FX_NUM_FIELDS long, not 100 slots: at x8 a
// single fast detent would cross a third of the list and overshooting would be
// the norm. x3 still slams end-to-end in ~8 detents (and clamping makes those
// ends a reliable landing spot), while anything slower than a brisk turn stays
// exactly one field per detent so you can always land on the one you want.
static constexpr int ENC_MENU_FAST_MULT = 3;   // detent gap < ENC_FAST_MS
static constexpr int ENC_MENU_MED_MULT  = 2;   // detent gap < ENC_MED_MS

// --- POT_RATE calibration (raw ADC; pots non-linear from the 10k pull-down,
//     daisy-uzd). Center-aware so 12 o'clock = 1x rate.
//
//     The 2026-09 standard part is a CENTRE-DETENT pot, which changes the basis
//     of this calibration. The old values were fleet MEANS (12 o'clock read
//     459/476/450/450 across modules 1/2/4/5) because noon on a smooth pot is
//     found by eye and lands somewhere different on every unit, so a mean was
//     the least-bad compromise. A detent puts noon in the same place every
//     time, so a single measured value is now both exact and repeatable.
//
//     Measured on the standard part: full CW 0.945. MIN and MAX are set inside
//     the travel on purpose -- see POT_ZERO in ogham_controls.h for why.
//     CenterNorm already clamps, so the ends simply arrive early.
//
//     THE CENTRE IS THE MIDPOINT OF THE TWO APPROACHES, not a single parked
//     reading. The detent has about 12 ADC counts of mechanical play: brought
//     in from the left it rests near 0.4470, from the right near 0.4590. A
//     reading taken from one side is therefore up to 6 counts off whichever way
//     the hand happened to be moving. 0.453 is the middle of the measured pair.
//     The earlier 0.461 was a single parked reading of unknown approach on a
//     different module, which is why the detent read 23 cents flat in V/oct.
//
//     The play itself is mechanical and no constant removes it: it remains
//     worth about 32 cents of V/oct fine tune, half either side of centre. That
//     was accepted deliberately rather than narrowing the +-12 semitone span,
//     which would have shrunk it proportionally but cost fine-tune range.
//
//     It bites ONLY in V/oct, because that is the one consumer with no
//     tolerance band of its own: the Tone knob's clean centre carries a +-20
//     count deadzone that swallows 12 counts of play whole, and a few counts of
//     free-running rate error at noon is inaudible. ---
static constexpr float RATE_POT_MIN    = 0.020f;   // margin, not the measured 0.000
static constexpr float RATE_POT_CENTER = 0.453f;   // midpoint of the two approaches
static constexpr float RATE_POT_MAX    = 0.915f;   // 0.030 under the measured 0.945
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
int main(void) {
    // --- Initialize Daisy Seed hardware ---
    hw.Init();

    // --- Configure 7 ADC channels (pots + CV + V/oct) ---
    AdcChannelConfig adcConfig[ogham::NUM_ADC_CHANNELS];
    adcConfig[0].InitSingle(hw.GetPin(ogham::POT_A));
    adcConfig[1].InitSingle(hw.GetPin(ogham::POT_B));
    adcConfig[2].InitSingle(hw.GetPin(ogham::POT_RATE));
    adcConfig[3].InitSingle(hw.GetPin(ogham::POT_LEVEL));
    adcConfig[4].InitSingle(hw.GetPin(ogham::CV_A));
    adcConfig[5].InitSingle(hw.GetPin(ogham::CV_B));
    adcConfig[6].InitSingle(hw.GetPin(ogham::VOCT_ADC));
    hw.adc.Init(adcConfig, ogham::NUM_ADC_CHANNELS);

    // --- Configure DAC for CV output ---
    DacHandle::Config dacConfig;
    dacConfig.mode = DacHandle::Mode::POLLING;
    dacConfig.bitdepth = DacHandle::BitDepth::BITS_12;
    dacConfig.chn = DacHandle::Channel::ONE;
    hw.dac.Init(dacConfig);

    // --- Configure encoder ---
    encoder.Init(hw.GetPin(ogham::ENC_A),
                 hw.GetPin(ogham::ENC_B),
                 hw.GetPin(ogham::ENC_SW));

    // --- Configure gate input (active-high after MMBT3904 inversion) ---
    gateIn.Init(hw.GetPin(ogham::GATE_IN));

    // Gate hard-sync: EXTI interrupt on GATE_IN (PD2). Q1 inverts the signal, so
    // an external gate RISING edge is a FALLING edge on the pin. The ISR requests
    // a sample-accurate reset in the engine (vs the jittery main-loop poll).
    {
        __HAL_RCC_SYSCFG_CLK_ENABLE();   // required for the EXTI line->port mapping
        GPIO_InitTypeDef g = {};
        g.Pin  = GPIO_PIN_2;
        g.Mode = GPIO_MODE_IT_FALLING;
        g.Pull = GPIO_PULLUP;   // GATE_IN needs the internal pull-up (Q1 collector)
        HAL_GPIO_Init(GPIOD, &g);
        HAL_NVIC_SetPriority(EXTI2_IRQn, 3, 0);
        HAL_NVIC_EnableIRQ(EXTI2_IRQn);
    }

    // --- Configure clock input (active-high after LM393 comparator) ---
    clockIn.Init(hw.GetPin(ogham::CLK_IN));   // still read via State() for telemetry

    // Clock pitch: EXTI on CLK_IN (PC12, line 12). Like the gate, the inverting
    // input stage makes an external rising edge a FALLING edge on the pin. The
    // ISR times the period in hardware -> stable pitch (no main-loop/display
    // jitter). SYSCFG clock was enabled above for the gate EXTI.
    {
        GPIO_InitTypeDef c = {};
        c.Pin  = GPIO_PIN_12;
        c.Mode = GPIO_MODE_IT_FALLING;
        c.Pull = GPIO_PULLUP;
        HAL_GPIO_Init(GPIOC, &c);
        HAL_NVIC_SetPriority(EXTI15_10_IRQn, 3, 0);
        HAL_NVIC_EnableIRQ(EXTI15_10_IRQn);
    }

    // --- Configure gate output ---
    gateOutGpio.Init(hw.GetPin(ogham::GATE_OUT),
                     GPIO::Mode::OUTPUT,
                     GPIO::Pull::NOPULL,
                     GPIO::Speed::LOW);
    gateOutGpio.Write(false);

    // --- Initialize modules ---
    engine.Init();
    pipeline.Init();
    controls.Init(&hw, &encoder, &gateIn, &clockIn);
    tm1637.Init(&hw, ogham::TM1637_CLK, ogham::TM1637_DIO);
    display.Init(&tm1637);
    cvOutput.Init(&hw.dac);
    bpmClock.Init();
    bpmClock.RequestEstimate();

    // --- Encoder scan timer (daisy-szs): TIM5 @ ENC_SCAN_HZ ---
    // Must follow controls.Init() (which configures the A/B pins and seeds the
    // decoder's previous state). TIM2 belongs to libDaisy's System clock; TIM5
    // is free on this board. If either call fails, encTimerRunning stays false
    // and the audio callback scans at 1kHz instead.
    {
        TimerHandle::Config cfg;
        cfg.periph     = TimerHandle::Config::Peripheral::TIM_5;
        cfg.dir        = TimerHandle::Config::CounterDir::UP;
        cfg.enable_irq = true;
        // APB1 timer kernel clock = PCLK1 * 2 (NOT PCLK2 -- see ENC_SCAN_HZ).
        cfg.period     = (HAL_RCC_GetPCLK1Freq() * 2) / ENC_SCAN_HZ;
        if (encTim.Init(cfg) == TimerHandle::Result::OK) {
            encTim.SetCallback(EncoderScanCallback);
            encTimerRunning = (encTim.Start() == TimerHandle::Result::OK);
        }
    }

    // --- Persistence: load saved settings (or factory defaults) from QSPI ---
    // Both voices = first formula; FX chain = module default.
    OghamSettings defaults = { SETTINGS_VERSION, 0, 0, AudioPipeline::DefaultFxChain(),
                               0, 128, 128, FW_VERSION };  // drone inc=0, A/B mid; fw stamp
    storage.Init(defaults);
    if (storage.GetSettings().version != SETTINGS_VERSION) {
        storage.RestoreDefaults();  // stored layout is from an old version -> wipe
    }

    // Capture the previously-stored firmware version (available for a future
    // migration). The running version is stamped + persisted LATER, via the normal
    // debounced main-loop save -- NOT with an inline storage.Save() here: a blocking
    // QSPI erase/write this early in boot (before the display splash even starts)
    // stalled the boot on the first update that triggered it. See the stamp after
    // settings are applied.
    uint32_t prevFwVersion = storage.GetSettings().fwVersion;
    (void)prevFwVersion;   // no version-keyed migrations yet

    // The splash and version screens use the saved brightness too.
    tm1637.SetBrightness(DisplayBrightness(storage.GetSettings().fx.displayMode));

    // --- Enable DWT cycle counter for CPU-load measurement (daisy-5wx) ---
    CoreDebug->DEMCR |= CoreDebug_DEMCR_TRCENA_Msk;
    DWT->CYCCNT = 0;
    DWT->CTRL |= DWT_CTRL_CYCCNTENA_Msk;

    // --- Start the ADC (audio is started later, once the params are stable) ---
    hw.adc.Start();

    // --- Startup splash (~1s): a single segment chases the outer border for 4
    //     laps. controls.Process() runs in the gaps to debounce the encoder and
    //     warm the pot ADC. Audio is NOT running yet, so there's no startup noise. ---
    {
        const int N = 12, STEPS = N * 4;    // 4 laps
        const uint32_t STEP_MS = 21;         // ~1s total (48 * 21ms)
        for (int s = 0; s < STEPS; s++) {
            uint32_t t0 = System::GetNow();
            tm1637.ShowBorderSegment(s % N);
            while (System::GetNow() - t0 < STEP_MS) {
                controls.Process();
                System::Delay(1);            // ~1kHz for the encoder debounce
            }
        }
        tm1637.Clear();
    }

    // --- Firmware version (~1s): show "M.mm" (e.g. " 1.00") so the installed build
    //     is identifiable at power-on and after a future flash update. controls
    //     keeps processing so a held encoder still arms the factory reset below. ---
    {
        display.ShowVersion(FW_VER_MAJOR, FW_VER_MINOR);
        uint32_t t0 = System::GetNow();
        while (System::GetNow() - t0 < 1000) {
            controls.Process();
            System::Delay(1);
        }
        tm1637.Clear();
    }

    // Snap the pot/CV smoothers to the actual readings -> stable params right now.
    controls.PrimeSmoothing();

    // --- Factory reset: hold the Func encoder at power-on to restore defaults
    //     (both voices on the first formula, default FX chain). The encoder is
    //     already debounced by the splash above. ---
    if (controls.GetEncoderPressed()) {
        storage.RestoreDefaults();
    }

    // Consume the power-on hold so the main-loop gesture detector doesn't see
    // the already-held encoder as a fresh press (which would fire a long-press
    // and drop straight into FX mode).
    encWasPressed = controls.GetEncoderPressed();
    encLongFired  = true;
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

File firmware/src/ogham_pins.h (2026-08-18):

// -----------------------------------------------------------------------------
// Ogham — a dual-voice bytebeat synthesizer for Eurorack
//
// Author:     Steven Collins, 2026, Keeos.io
// Copyright:  (c) 2026 Steven Collins
//
// SPDX-FileCopyrightText: 2026 Steven Collins <https://keeos.io>
// SPDX-License-Identifier: MIT
//
// This file is part of the Ogham firmware. See LICENSE-firmware.txt at the
// repository root for the full licence text.
// https://github.com/keeos-io/ogham
// -----------------------------------------------------------------------------

#pragma once
// Ogham Eurorack Module — Pin Assignments
// Source of truth: KiCad schematic v0.4 (ERC clean)
// See hardware/ogham/ERC_manual_review.md for full pin table

namespace ogham {

// --- Encoder (directly connected, active-low with pull-ups) ---
constexpr int ENC_A  = 0;   // GPIO0, Seed pin 1
constexpr int ENC_B  = 1;   // GPIO1, Seed pin 2
constexpr int ENC_SW = 2;   // GPIO2, Seed pin 3

// --- Gate / Clock (active-high after transistor/comparator inversion) ---
constexpr int GATE_IN  = 5;  // GPIO5, Seed pin 6  — via MMBT3904 NPN
constexpr int CLK_IN   = 6;  // GPIO6, Seed pin 7  — via LM393 comparator
constexpr int GATE_OUT = 7;  // GPIO7, Seed pin 8  — via 74AHCT1G125 buffer

// --- TM1637 Display ---
constexpr int TM1637_CLK = 9;   // GPIO9,  Seed pin 10
constexpr int TM1637_DIO = 10;  // GPIO10, Seed pin 11 — open-drain, 10k pull-up

// --- ADC Channels (D15-D21 = ADC0-ADC6) ---
constexpr int POT_A     = 15;  // ADC0, Seed pin 22
constexpr int POT_B     = 16;  // ADC1, Seed pin 23
constexpr int POT_RATE  = 17;  // ADC2, Seed pin 24
constexpr int POT_LEVEL = 18;  // ADC3, Seed pin 25
constexpr int CV_A      = 19;  // ADC4, Seed pin 26 — via MCP6004 (inverted)
constexpr int CV_B      = 20;  // ADC5, Seed pin 27 — via MCP6004 (inverted)
constexpr int VOCT_ADC  = 21;  // ADC6, Seed pin 28 (A6/D21) — V/oct tap on the Clock jack
constexpr int NUM_ADC_CHANNELS = 7;

// --- Mode toggle: Clock (tempo) <-> V/oct (pitch) ---
// Dailywell SPDT: common (pin 2) -> GND, throw (pin 1) -> this GPIO w/ pull-up.
constexpr int MODE_SW   = 8;   // GPIO8, Seed pin 9 (D8 / PG11)

// --- DAC Output ---
constexpr int CV_OUT_DAC = 23;  // DAC_OUT1 / PA4, Seed pin 30

}  // namespace ogham

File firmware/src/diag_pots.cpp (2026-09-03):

// -----------------------------------------------------------------------------
// Ogham — a dual-voice bytebeat synthesizer for Eurorack
//
// Author:     Steven Collins, 2026, Keeos.io
// Copyright:  (c) 2026 Steven Collins
//
// SPDX-FileCopyrightText: 2026 Steven Collins <https://keeos.io>
// SPDX-License-Identifier: MIT
//
// This file is part of the Ogham firmware. See LICENSE-firmware.txt at the
// repository root for the full licence text.
// https://github.com/keeos-io/ogham
// -----------------------------------------------------------------------------

// Ogham pot-calibration diagnostic (standalone firmware).
//
// Displays the RAW, smoothed ADC reading (0.000-1.000 shown as 0-999) of each of
// the four pots, using the SAME Controls smoothing the real firmware uses -- so a
// value read here is exactly what the firmware's calibration is compared against.
//
// The display auto-selects whichever pot you move:
//   A nnn = Param A pot        (linear; POT_ZERO 020 .. POT_FULL_SCALE 906)
//   b nnn = Param B pot        (linear; same span as A)
//   r nnn = Rate / Fine pot    (RATE_POT_CENTER 453, MIN 020, MAX 915)
//           NB the detent has ~12 counts of play -- park it from BOTH sides and
//           take the midpoint, not a single reading.
//   t nnn = Tone pot           (LOFI_CENTER 477, MIN 020, MAX 915)
//
// The MODE SWITCH picks the bank. Flipped the other way, the display shows the
// SLOPE of the summing amp, solved live:
//   c nnn = POT_ADC_GAIN for channel A, x1000   (999 = 0.999)
//   d nnn = POT_ADC_GAIN for channel B, x1000
// from adc = CV_ZERO_OFFSET - GAIN * pot, i.e. GAIN = (OFFSET - adc) / pot,
// using the intercept the firmware itself holds (Controls::CvZeroOffset).
//
// Solving it on the module rather than reporting two numbers to pair up by hand
// is the point: pot and summed channel are sampled in the same instant, so the
// answer does not depend on the knob holding still between two readings -- and
// it is INDEPENDENT OF KNOB POSITION, so nudging a pot to select its channel
// cannot corrupt the value being read.
//
// Park the pot anywhere from about a third to two thirds of the throw. Below
// that the division is dominated by noise; above it the amp rails at ground
// (around 78% of rotation) and there is no slope left to measure. Either way
// the display reads "---" rather than a wrong number.
//
// Encoder CLICK cycles the VIEW (peak-hold), shown by the decimal point:
//   LIVE  -> no dot        current position (park at 12 o'clock to read centre)
//   LO    -> dot on letter latched MINIMUM  ("A.458")   sweep fully CCW to capture
//   HI    -> dot on units  latched MAXIMUM  ("A458.")   sweep fully CW  to capture
// Min/Max latch from power-on; power-cycle / re-flash to reset them.
//
// Reflash the normal firmware afterwards:
//   openocd -f interface/stlink.cfg -f target/stm32h7x.cfg \
//     -c "program ./build/ogham_bytebeat.elf verify reset exit"

#include "daisy_seed.h"
#include "ogham_pins.h"
#include "ogham_controls.h"
#include "tm1637.h"

using namespace daisy;

static DaisySeed hw;
static Encoder   encoder;
static GateIn    gateIn;
static GateIn    clockIn;
static Controls  controls;
static TM1637    tm1637;

static const char POT_LETTER[6] = {'A', 'b', 'r', 't', 'c', 'd'};

// RAW channel value, used for movement detection and peak-hold: 0-3 are the
// pots (ADC0-3), 4-5 the MCP6004 summed channels (ADC4-5), all through the same
// smoothing the real firmware uses.
static float ChanValue(Controls& c, int i) {
    return (i < 4) ? c.GetPot(i) : c.GetCvRaw(i - 4);
}

// What actually gets DISPLAYED. Pots show their raw reading; the summed
// channels show the solved gain instead, which is why selection has to key off
// ChanValue above -- the gain is deliberately steady while the pot moves, so it
// would never trip a movement test.
static constexpr float GAIN_MIN_POT = 0.30f;   // below: division dominated by noise
static constexpr float GAIN_MIN_ADC = 0.02f;   // below: amp railed, no slope left
static bool DisplayValue(Controls& c, int i, float& out) {
    if (i < 4) { out = c.GetPot(i); return true; }
    float pot = c.GetPot(i - 4);
    float adc = c.GetCvRaw(i - 4);
    if (pot < GAIN_MIN_POT || adc < GAIN_MIN_ADC) return false;
    out = (Controls::CvZeroOffset(i - 4) - adc) / pot;
    return true;
}

// A pot must move by more than this (of full scale) to grab the display.
static constexpr float MOVE_THRESH = 0.008f;  // ~2 LSB of the 8-bit-ish reading
static constexpr uint32_t DRAW_MS  = 33;      // ~30 Hz display refresh

// view: 0 = LIVE, 1 = LO (min), 2 = HI (max)
static void ShowLetterValue(char letter, int value, int view) {
    if (value < 0)   value = 0;
    if (value > 999) value = 999;
    uint8_t s[4];
    s[0] = TM1637::Encode(letter);
    s[1] = TM1637::Encode('0' + (value / 100) % 10);   // always 3 digits (leading
    s[2] = TM1637::Encode('0' + (value / 10) % 10);    // zeros shown for clarity)
    s[3] = TM1637::Encode('0' + value % 10);
    if (view == 1) s[0] |= 0x80;   // LO: dot on the pot letter
    if (view == 2) s[3] |= 0x80;   // HI: dot on the last digit
    tm1637.ShowChars(s);
}
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

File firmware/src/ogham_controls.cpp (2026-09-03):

// -----------------------------------------------------------------------------
// Ogham — a dual-voice bytebeat synthesizer for Eurorack
//
// Author:     Steven Collins, 2026, Keeos.io
// Copyright:  (c) 2026 Steven Collins
//
// SPDX-FileCopyrightText: 2026 Steven Collins <https://keeos.io>
// SPDX-License-Identifier: MIT
//
// This file is part of the Ogham firmware. See LICENSE-firmware.txt at the
// repository root for the full licence text.
// https://github.com/keeos-io/ogham
// -----------------------------------------------------------------------------

#include "ogham_controls.h"
#include <cmath>

// Scans of stillness before leftover sub-steps are discarded (150ms @ 20kHz).
static constexpr uint16_t ENC_IDLE_CLEAR_SCANS = 3000;


// Encoder direction (daisy-0wf, daisy-796). Encoder batches exist with opposite
// A/B phase, and which one is the DEFAULT has now changed twice -- so read this
// rather than trusting memory.
//
// Since 2026-09 the default is ENC_REVERSED=0, the part used by the standard
// distribution build. Module 1's original encoder happens to want the same
// direction, so it shares this build. Modules 2-5 carry the swapped-A/B part
// and need -DENC_REVERSED=1 (see Makefile.encswap, output
// ogham_bytebeat_encswap).
//
// Before 2026-09 the default was 1 and the variant was 0, which is the reverse
// of this. Getting it backwards ships a module whose encoder counts down when
// turned clockwise, so confirm against a real unit rather than against an older
// release note. Either way round, switching a unit over is only a reflash.
#ifndef ENC_REVERSED
#define ENC_REVERSED 0
#endif

void Controls::Init(daisy::DaisySeed* seed,
                    daisy::Encoder* encoder,
                    daisy::GateIn* gateIn,
                    daisy::GateIn* clockIn) {
    seed_ = seed;
    encoder_ = encoder;
    gateIn_ = gateIn;
    clockIn_ = clockIn;

    // Mode toggle input (Clock <-> V/oct): SPDT common -> GND, internal pull-up.
    modeGpio_.Init(seed_->GetPin(ogham::MODE_SW),
                   daisy::GPIO::Mode::INPUT, daisy::GPIO::Pull::PULLUP);
    voctSmoothed_ = 0.0f;
    voctMode_ = false;
    modeDebounce_ = 0;

    for (int i = 0; i < 4; i++) {
        potValues_[i] = 0.0f;
        potSmoothed_[i] = 0.0f;
    }
    cvSmoothed_[0] = CV_ZERO_OFFSET_A;
    cvSmoothed_[1] = CV_ZERO_OFFSET_B;
    combinedA_ = 0.5f;
    combinedB_ = 0.5f;
    encoderInc_ = 0;
    encoderPressed_ = false;
    encoderRising_ = false;
    lastEncoderPressed_ = false;
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

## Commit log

2026-08-03 Ogham v1.09: firmware and hardware sources
    First publication of the Ogham module: firmware source, KiCad schematics and
    PCB, panel, and a ready-to-upload fabrication package.
    Firmware is MIT, matching libDaisy and DaisySP so there is no friction linking
    them. Hardware and documentation are CC BY-SA 4.0 — build one, sell one, fork
    it, but share hardware modifications alike. The Keeos name and the panel
    identity are explicitly not covered; the design is open, the branding is not.
    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
    [Ogham Panel Graphics (JLCPCB).kicad_pcb, audio.kicad_sch, bom.csv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]
2026-08-03 Add licence headers to the firmware sources; fix the site domain
    Copyright Steven Collins, MIT, with SPDX tags on every C++ source, Python tool
    and Makefile. KiCad files are left alone -- they are CC BY-SA rather than MIT,
    and KiCad rewrites them wholesale so a hand-added comment would not survive.
    Also corrects the site domain: the READMEs and CHANGELOG said keeos.co.uk,
    which does not exist. It is keeos.io. Four dead links.
    The headers are comments, and that was checked rather than assumed: a clean
    build still reproduces both released v1.09 binaries byte for byte, so the
    published checksums remain valid.
    [bpm_clock.h, bytebeat_engine.h, diag_pots.cpp]
2026-08-03 Docs: per-platform build instructions for Windows, macOS and Linux
    Adds docs/BUILDING.md. The existing instructions assumed a Windows machine with
    everything already installed, which is fine for the person who built it and
    useless to anyone else.
    Covers per platform: installing the toolchain, Make, and the flashing tools;
    the USB driver work each one needs; and a troubleshooting table keyed by the
    error message you actually see rather than by cause.
    The platform-specific traps are the point of the document:
    - Windows ships no Make, and the Arm toolchain does not include one. DFU also
    needs the WinUSB driver bound via Zadig or dfu-util reports no device.
    - macOS quarantines the downloade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
2026-08-03 Hardware: interactive HTML BOM for assembly
    Adds production/ogham-merged-v1.0-ibom.html — one self-contained 588 KB file
    where clicking a BOM line lights the parts up on the board, front and back,
    with checkboxes for tracking what has been sourced and placed. No install and
    no network; it is the thing to have open while populating a board.
    Generated with InteractiveHtmlBom v2.11.2, which is the first version that
    reads KiCad 10 files — anything earlier fails on our format (20260206).
    Verified by actually loading the output: 8 canvases, 41 BOM rows, zero page
    errors, both board faces rendering.
    Configured to show the LCSC column, which turns out to double as the
    hand-populate list: part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
2026-08-08 Firmware v1.10
    Maintenance release: firmware source clean-up (dead code removed from
    earlier, since-superseded designs -- an unused Out 2 delay mechanism, an
    unused engine freeze, unused polled gate/clock edge detection, among
    others; no behaviour change) plus a Makefile.diag BUILD_DIR isolation fix
    (same fix applied to this repo's own copy, which had the identical bug).
    No FxChainConfig/OghamSettings changes -- updating from 1.09 does not reset
    saved settings.
    Manual gained a new Troubleshooting section (LPG-on + nothing-on-Sync =
    expected silence, not a fault); PDF regenerated to match.
    Claude-Session: https://claude.ai/code/sessio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
    [bpm_clock.h, bytebeat_engine.h, ogham_audio_pipeline.cpp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]
2026-08-10 Firmware v1.11: the full hundred-formula bank
    All 100 numbered slots are real formulas now, grouped by character: twenty each
    of textural (F0-F19), noise (F20-F39), percussive (F40-F59), rhythmic (F60-F79)
    and melodic (F80-F99). The Viznut placeholder is no longer reachable from the
    panel, and the previous 22-formula bank is entirely replaced - so a saved patch
    selects a different sound than it did on 1.10. Settings layout is unchanged, so
    updating does not reset anything else.
    formulas.h and formulas.cpp are generated, not hand-written: the bytebeat repo's
    tools/gen_ogham_bank.cpp translates the curated library into C++ and compares
    every function against the evaluator the formulas were au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
    [ogham_main.cpp]
2026-08-10 Firmware v1.13: encoder fix, FX bypass, and the dev tree resynced
    Brings the firmware sources back in line with the development tree. They had
    fallen a release behind: this repo carried v1.10-era sources with the new
    hundred-formula bank grafted on, so it claimed v1.11 while missing every part of
    v1.11 except the formulas -- SETTINGS_VERSION 12 against the real 15, and no CV
    slew, hold, capture-phase or multi-step tick work at all. Anyone building from
    here got something that had never shipped.
    Now identical to the development tree at v1.13. Makefiles deliberately not
    synced: this repo's use LIB_DIR ?= ../lib for its own layout.
    Two firmware changes since the bank landed.
    The encoder stop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
    [bytebeat_engine.h, ogham_audio_pipeline.cpp, ogham_audio_pipeline.h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]
2026-08-11 Firmware v1.14: V/oct rate-tracking, beat-rate clock, LPG curve, A/B resolution
    Resyncs the mirror from the development tree at FW_VER_MINOR 14. Makefiles
    deliberately not synced: this repo's use LIB_DIR ?= ../lib for its own layout.
    SETTINGS_VERSION 15 -> 16, for the persisted V/oct start offset. Flashing this
    resets saved settings.
    The behaviour changes, briefly:
    - V/oct sets the playback rate exponentially instead of hard-syncing the engine
    each cycle. The formula runs out normally and every partial scales together --
    varispeed transposition rather than a forced restart -- so formulas keep their
    character across the keyboard and the ones that used to fall silent under
    V/oct no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
    [bpm_clock.h, bytebeat_engine.h, ogham_audio_pipeline.cpp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]
2026-08-11 Tools: fix read_once.py's telemetry field indices (off by one)
    Mirrors the dev tree. It read potA from v[12] where struct Telemetry puts it at
    v[11], so every printed field was the next one along and "cvB" was actually
    cpuPeak. Not pushed as a release; it rides with the next one.
    Claude-Session: https://claude.ai/code/session_01XENjVeWf9AfjqdA2k3DhAa
2026-08-18 Firmware v1.15, and move to the keeos-io organization
    Sources synced from the development tree at v1.15: the A/B pot range fix,
    one-shot formulas restarting on selection, and the withdrawal of the V/oct
    start-offset menu field. Both encoder builds from this tree reproduce the
    binaries flashed to the fleet byte-for-byte.
    Repository URL updated to github.com/keeos-io/ogham throughout, ahead of the
    transfer — it appears in the licence header of every source file.
    Also: changelog entries for 1.13, 1.14 and 1.15; the manual PDF refreshed to
    the current build; four development tools added, one of which (formula_life)
    is referenced from a source comment; and the note about the bank generator no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
    [bpm_clock.h, bytebeat_engine.h, diag_pots.cpp]
2026-08-18 Docs: fix the clone directory name, and the Windows long-path trap
    The repository is now named ogham, so `cd keeos-ogham` after cloning was wrong
    in all three places it appeared.
    A fresh clone on Windows fails at libDaisy's nested CMSIS_5 submodule — some
    test-suite paths exceed 260 characters — with an error that names the submodule
    but not the cause. BUILDING.md now says to set core.longpaths first. Found by
    cloning the repository from its new URL and rebuilding: both encoder binaries
    come out byte-identical to the ones flashed to the fleet.
    Claude-Session: https://claude.ai/code/session_01B7Nk9E4jqoEcfqKaG6cDLP
2026-08-18 Firmware v1.16: remove the placeholder formula
    The out-of-range fallback is gone from the bank and from THIRD-PARTY.md. It has
    been unreachable since 1.11 — all hundred slots hold real formulas, and both
    voices clamp their index before the lookup — so this changes nothing audible.
    An out-of-range index now returns slot 0.
    Regenerated from the curated library and verified at 72,000,000 samples against
    the evaluator the formulas were auditioned on. Flash 127,712 B, 97.44%.
    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
2026-08-18 Hardware: known issues and planned changes, written out
    The section existed but only covered electrical limits. It now also carries the
    mechanical and sourcing items someone would otherwise rediscover with a fab
    invoice already paid: mounting holes slightly out, the bottom jack row about a
    millimetre too low for reliable case clearance, panel holes still stored as
    piecewise curves rather than drills, and the display's fit behind the panel.
    Also recorded as intentions rather than defects: the ENV OUT to CV OUT rename,
    C5 moving to SMD, dropping the proprietary panel font, standardising on one
    encoder so the variant firmware build can go, and the centre-detent pots on the
    recent prototypes th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
2026-08-28 Publish the v2 panel: DINish in place of Bahnschrift, and CV Out
    The repository was carrying the first panel revision while the modules were being
    built from the second. That started as a stale font reference in THIRD-PARTY.md
    and turned out to be the artwork and the panel PCB both being a revision behind.
    Adds hardware/panel/PanelPCB-v2/ and the v2 SVG, and marks them as current.
    PanelPCB/ and the unversioned SVG stay, because the earliest modules were made
    from them.
    Two things the v2 artwork fixes, both of which were open issues in
    hardware/README.md and are now closed by publishing it:
    - Bahnschrift is gone. It is a Microsoft system font, not redistributable and
    absent on macOS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
    [Ogham Panel Graphics (JLCPCB) v2-B_Cu.gbl, Ogham Panel Graphics (JLCPCB) v2-B_Mask.gbs, Ogham Panel Graphics (JLCPCB) v2-B_Paste.gbp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]
2026-08-28 Changelog: the jack is CV Out
    The v2 panel relabelled jack 14 from "Env Out" to "CV Out", and the 1.14 entry
    still described the settings reset by the old name. Same jack, same reset — this
    is the name printed on the panel.
    Claude-Session: https://claude.ai/code/session_01SYHdhxTqBdJYwW27RyMdTR
2026-08-28 Docs: refresh the manual PDF
    Rebuilt from the site source, which had been a revision behind since 2026-08-18.
    Picks up the CV Out rename that went with the v2 panel, and the new "Why the
    pitch shifts when you flip the switch" subsection. 41 -> 42 pages.
    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
2026-08-29 Docs: refresh the manual PDF
    Picks up the dfu-util example moving from v1.03 to v1.16 — the old byte size
    would have failed a readback check against a current image.
    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
2026-08-29 Hardware: browse the schematic and PCB in the browser via KiCanvas
    The circuit has been the one part of this design nobody could see without
    installing software. The interactive BOM already covers board geometry and the
    parts list, but the five hierarchical sheets that explain how the thing works
    needed KiCad — and specifically KiCad 10, since KiCad 9 cannot open these files
    at all. Adds a KiCanvas link for the main board and one for the panel.
    Both links point at a DIRECTORY rather than a file, which is not the pattern
    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
2026-08-30 Firmware: strip historical narration from the source comments
    Sync with the development tree, where a systematic pass went over every
    hand-written file in firmware/src (formulas.h/.cpp are generated and excluded).
    Three kinds of change:
    Comments that narrated a superseded fix rather than explaining the code are
    gone, with anything load-bearing kept as a statement about the present. The
    encoder scan no longer recounts that its rate was 20kHz by accident; the NVIC
    priority block keeps the rule and the mechanism but not the full measurement
    log; the CV Out capture phase, the param-commit hysteresis, the A/B software
    sum, the LPG decay curve, the BPM lock and the DC make-up gain all keep their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
    [bpm_clock.h, bytebeat_engine.h, diag_pots.cpp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]
2026-09-02 Docs: flashing a Seed3 has no debug connector to clip onto
    Electro-Smith replaced the Seed's surface-mount debug connector with bare
    through-hole pads on the Seed3, so SWD needs a header soldered on before an
    ST-Link is any use. DFU needs no probe and is the easier path there.
    Also names the cable: USB-C on a Seed3, micro-USB on earlier revisions, and
    data-capable either way.
    Verified on a Seed3 in module #3 — the firmware itself needs no change for
    that revision.
    Claude-Session: https://claude.ai/code/session_01TwaaWV8X6Myo2bnFkFYvxA
2026-09-02 Firmware v1.17: A and B reach both rails exactly
    Bumps FW_VER_MINOR to 17, which the v1.17 tag should have carried and did
    not — a module built from that tag reported 1.16 at power-up.
    Also brings in the CV null band. At full CCW both parameters bottomed out at
    1-2 rather than 0, which matters because formulas treat 0 as a real value.
    The pot was not at fault: pot / POT_FULL_SCALE is exactly 0 at the rail. The
    residual is the CV term, which should be 0 with nothing patched and is not,
    because the offsets were fitted on one module and another module's amp sits a
    few thousandths away. The same error costs a count at the top on a module
    whose sign runs the other way, so the fix goes on the C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
    [ogham_controls.cpp, ogham_controls.h, ogham_main.cpp]
2026-09-03 Firmware v1.18: calibrated for the current standard build
    Pot spans, the CV summing-amp intercept and the Rate detent centre are all
    re-measured on the hardware being built now, with deliberate margin at both
    ends so the calibration tolerates part variation rather than fitting one unit.
    - A and B reach 0 and 255 across their full travel. The old span sat above the
    pots' actual maximum, so full clockwise stopped at 253, and the recovered-CV
    intercept held the bottom off zero.
    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
2026-09-03 Hardware README: drop the known-issues section, correct two facts
    The known-issues and planned-changes section is retired — most of what it
    listed is fixed, and the outstanding items are tracked privately rather than
    in the public tree. The top-level README linked to that anchor, so its status
    note loses the dangling link and the "two mechanical fixes are due" clause
    with it.
    Two corrections to what remains:
    - The summary table said the on-board +5 V regulator powers the Daisy Seed.
    It does not, and has not since 2026-07-13: the Seed's VIN comes from +12 V
    through D8 (SS14), and U2 (L7805) supplies only the TM1637 display, the
    gate buffer U5 and the comparator U6. power.kicad_sch s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
2026-09-03 Hardware: name the encoder actually fitted, drop a stray SVG
    The sourcing table listed a 20 mm T18 / 24 PPR encoder against a Thonk link.
    That is a different component from the one the modules are built with: the
    production part is Bourns PEC11R-4115K-S0018 — 15 mm knurled T18 shaft, push
    switch, 18 detents and 18 pulses per revolution. It was bought direct rather
    than through Thonk, so the row now points at distributors the way the C5 row
    already does.
    The encoder note gains the decode and says which build the part wants. It is
    the swapped-A/B production part, which is what the default firmware build
    targets; firmware/README.md already describes the pair, and this makes the
    link between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
2026-09-03 Panel: keep only the v2 revision
    PanelPCB/ and the unversioned Ogham Panel Graphics (JLCPCB).svg were the
    first panel revision, retained only because the earliest modules were made
    from them. Two panel projects side by side is an invitation to order the
    wrong one, and the v1 artwork is the Bahnschrift version that cannot be
    edited off Windows anyway. Removed; git history still has them.
    The Panel section is rewritten to describe one revision rather than compare
    two, and the layout table no longer needs to say which of them is current.
    Claude-Session: https://claude.ai/code/session_01JjKhj8acrihM7Sy76orMho
    [Ogham Panel Graphics (JLCPCB).kicad_pcb, bom.csv, designators.csv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]
2026-09-03 Hardware README: say why the 15 mm encoder, and that it needs a washer
    The 15 mm shaft is a deliberate choice, not the accident it could look like
    next to a 20 mm part. Above the mounting shoulder the encoder is dimensionally
    identical to the Alpha pots — 5 mm of M7 x 0.75 bushing and 15 mm to the shaft
    tip on both — so the encoder knob finishes level with the four pot knobs. The
    20 mm variant carries a 7 mm bushing and would stand proud.
    The consequence is only 5 mm of thread against a 1.6 mm panel, which is why
    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
2026-09-07 Repoint the KiCad absolute paths after the module move
    The 3D-model and netlist-source paths named D:/daisy/hardware/ogham, which is
    now D:/modules/ogham/hardware/ogham. These absolute paths only ever resolved on
    the authoring machine; making them ${KIPRJMOD}-relative would serve anyone
    cloning this repo better, but that is a design change, not this move.
    Claude-Session: https://claude.ai/code/session_01UmKMTM6UmxVSuPPxNnAGq4
    [ogham-merged-v1.0.kicad_pcb]
2026-09-07 Hardware: make the 3D model paths ${KIPRJMOD}-relative and say what is missing
    The PCB named its 3D models by absolute path on the authoring machine, so the
    model references were dead for anyone who cloned this repository, and the 3D
    view came up with seventeen missing files and no explanation of what they were.
    The references now go through ${KIPRJMOD}, which KiCad resolves against the
    project directory, so creating hardware/_libs/ and dropping the files in is
    enough to fill the 3D view in with no edit to the PCB. hardware/README.md gains
    a table of the seven models, what each one is for, where to get it and what its
    licence is where that is stated.
    The models themselves are still not red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
    [ogham-merged-v1.0.kicad_pcb]
2026-09-07 KiCad: drop the dead KICAD9 jack model from the eight jacks
    Each jack footprint carried two 3D models. Only one resolves: the AudioJacks
    PJ398SM_Hex_nut.step, referenced relative to the project. The other named
    ${KICAD9_3DMODEL_DIR}, which is not a variable KiCad 10 defines, so it never
    loaded and only produced a "could not add 3D model" warning per jack on every
    3D export. The jacks look exactly as they did; the export is now silent.
    Verified with kicad-cli: eight warnings before, none after. Pure deletion, no
    other change to the board.
    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
    [ogham-merged-v1.0.kicad_pcb]
2026-09-12 U1 reference: replace LCSC C156302 with C156291 (LM4040C50FTA)
    Same LM4040-5.0 shunt reference in the same SOT-23 footprint, so the
    schematic, netlist and layout are unchanged. JLCPCB places U1 during
    assembly, so kits, the build guide and the manuals are unaffected.
    Claude-Session: https://claude.ai/code/session_01BFcNtHK4juky97LkdECFZu
    [bom.csv]
2026-10-05 Firmware v1.19: display brightness + auto-off
    New Menu field br.NN: last digit = display brightness 0-7, first digit 1 =
    auto-off (dark 1 s after the last encoder or knob movement). Default br.14.
    On the v1.0 board the display's LED current is audible on the outputs as a
    faint buzz; auto-off removes it hands-off. Settings survive (SETTINGS_VERSION
    16 unchanged). Manual PDF refreshed. The changelog intro no longer claims two
    encoder builds per release.
    [ogham_audio_pipeline.cpp, ogham_audio_pipeline.h, ogham_main.cpp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]
